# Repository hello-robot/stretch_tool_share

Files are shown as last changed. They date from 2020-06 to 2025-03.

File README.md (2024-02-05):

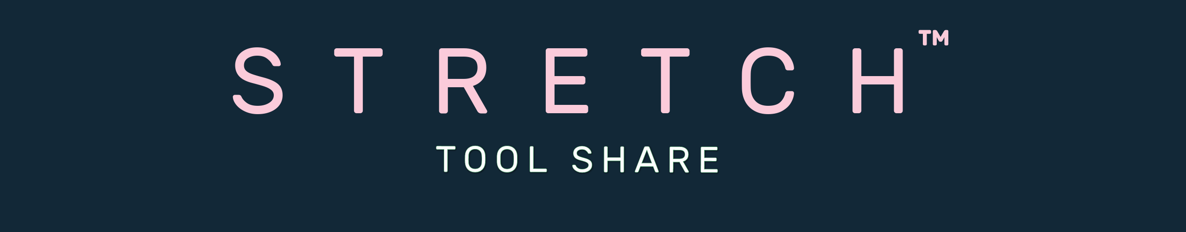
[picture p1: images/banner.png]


# Overview

We designed Stretch's hardware to be easily extended. You can make your own tool and attach it to the wrist to creatively expand what the Stretch RE1 can do. Your tool can also use Dynamixel X-series servos from Robotis via the provided TTL bus. 

In this repository, we provide examples of tools that we've created. We've released them with a permissive Apache 2.0 license, so you're free to use them as you wish. We hope they'll inspire you to create your own tools.

We also include URDF and mesh files for many of the tools in their `stretch_description` folder. See the [Stretch ROS](https://github.com/hello-robot/stretch_ros/tree/master/stretch_description) documentation for guidance on integrating these tools into your robot model.

We'd love it if you shared your creations with the community. We recommend you create a GitHub repository similar to this one for your own tools and then post an announcement to the [forum](https://forum.hello-robot.com/) to let people know about it. 

| Tool | |
|:---:| :---: |
| [NVIDIA Jetson Orin AGX Backpack](./tool_share/jetson_orin_agx_mount) |  || | |
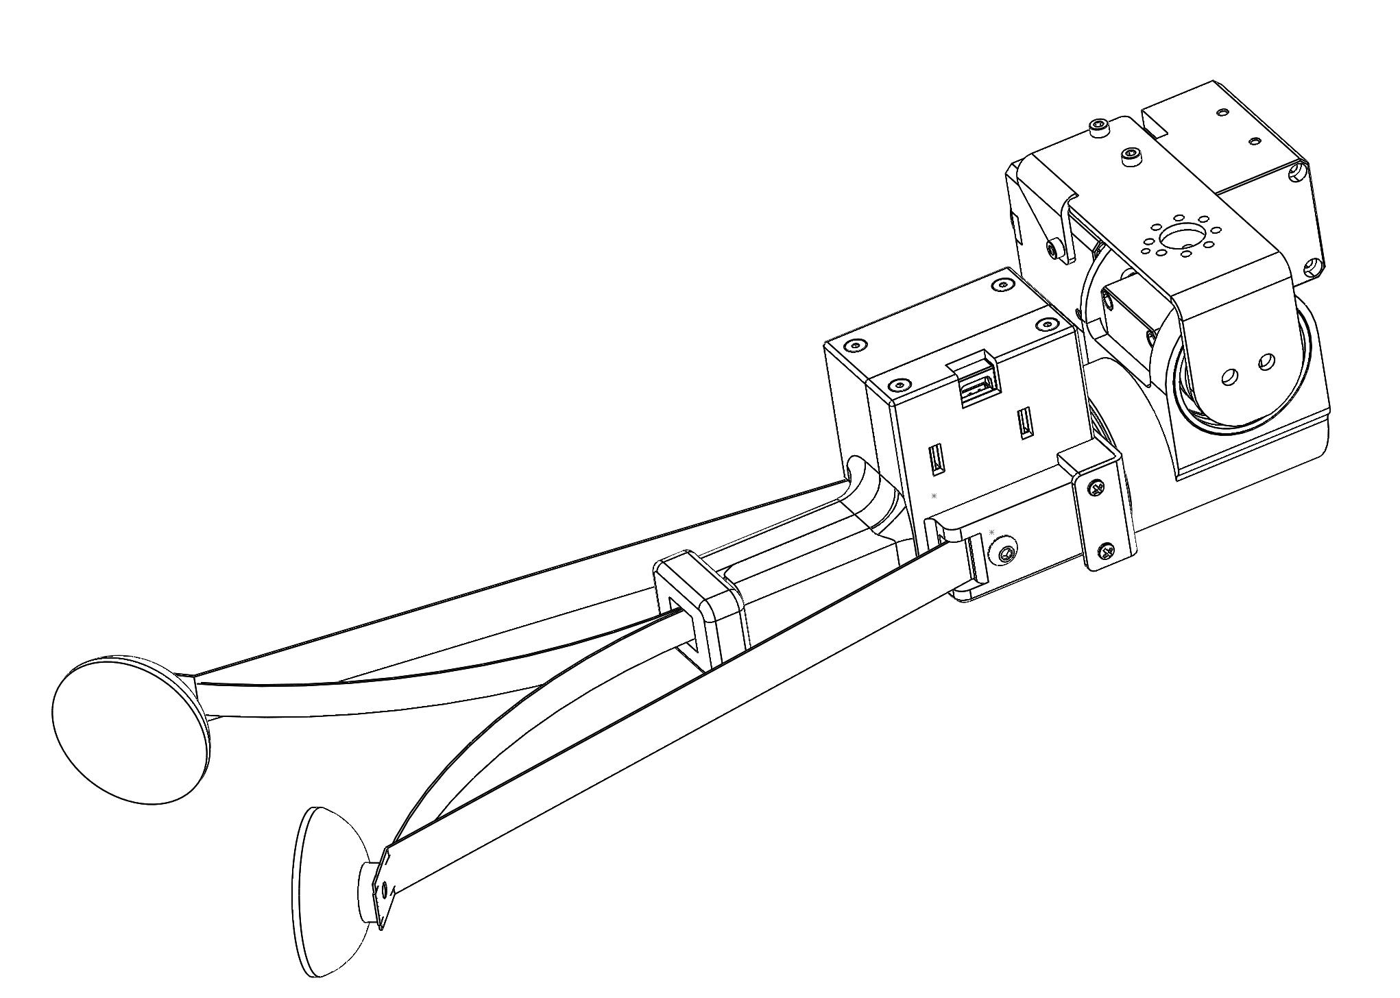
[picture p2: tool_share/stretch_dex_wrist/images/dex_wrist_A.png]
| [Stretch Dex Wrist](./tool_share/stretch_dex_wrist) |  |
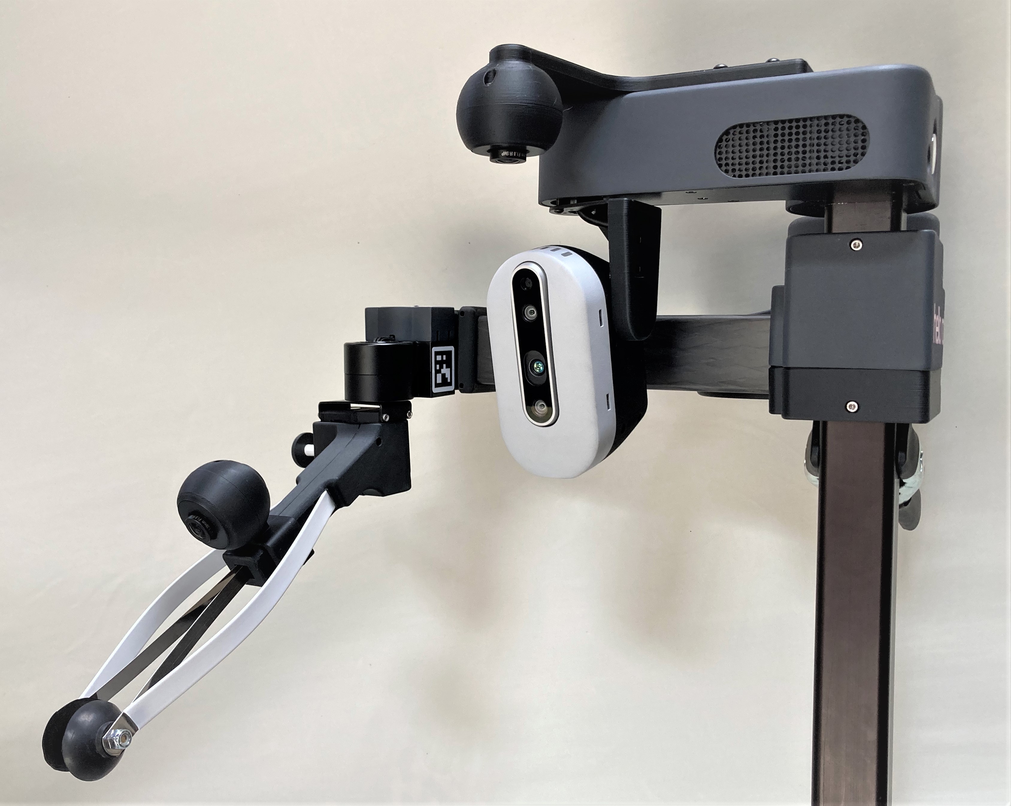
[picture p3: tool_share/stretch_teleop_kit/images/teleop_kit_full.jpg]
| [Stretch Teleop Kit](./tool_share/stretch_teleop_kit) |  |
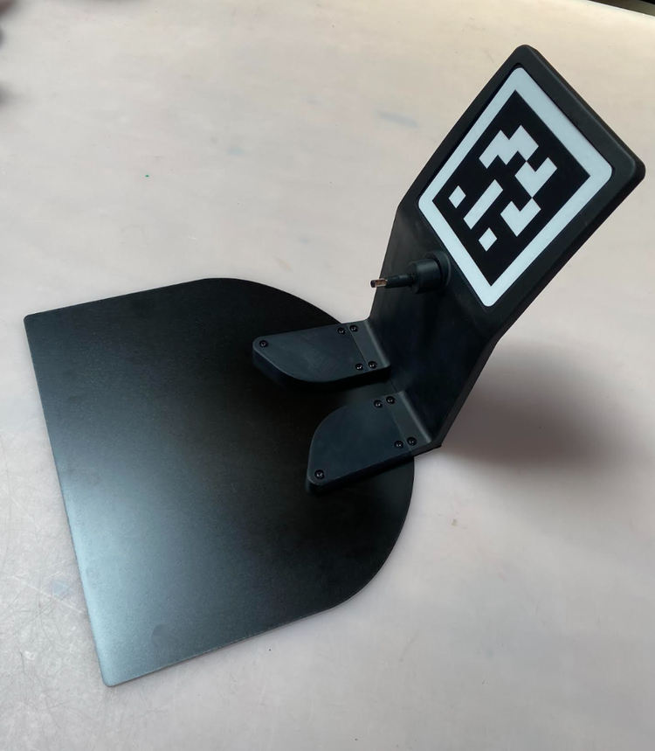
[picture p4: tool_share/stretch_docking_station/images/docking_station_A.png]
| [Stretch Docking Station](./tool_share/stretch_docking_station) |  |
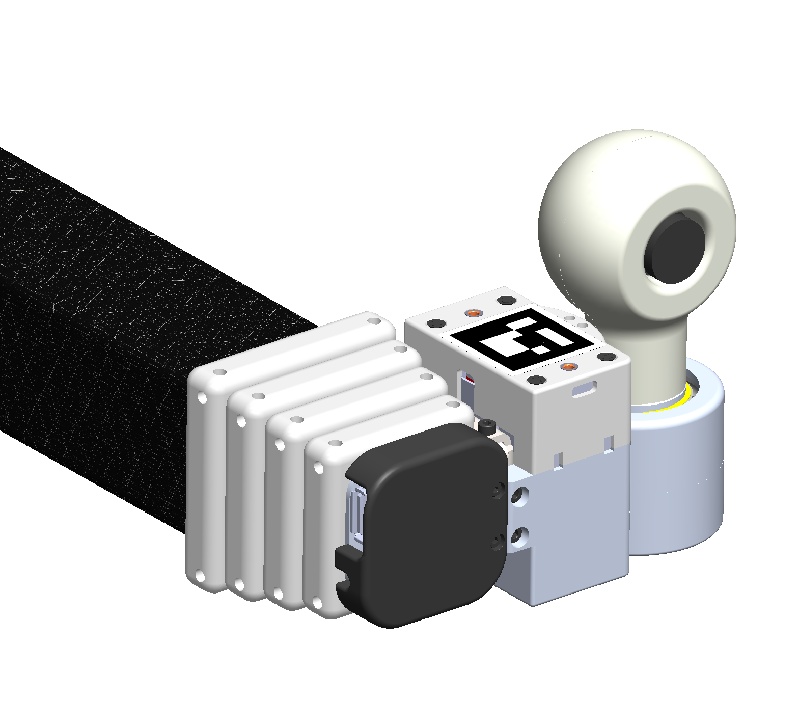
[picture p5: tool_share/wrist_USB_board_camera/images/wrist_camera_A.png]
| [Wrist USB Board Camera](./tool_share/wrist_USB_board_camera) |  |
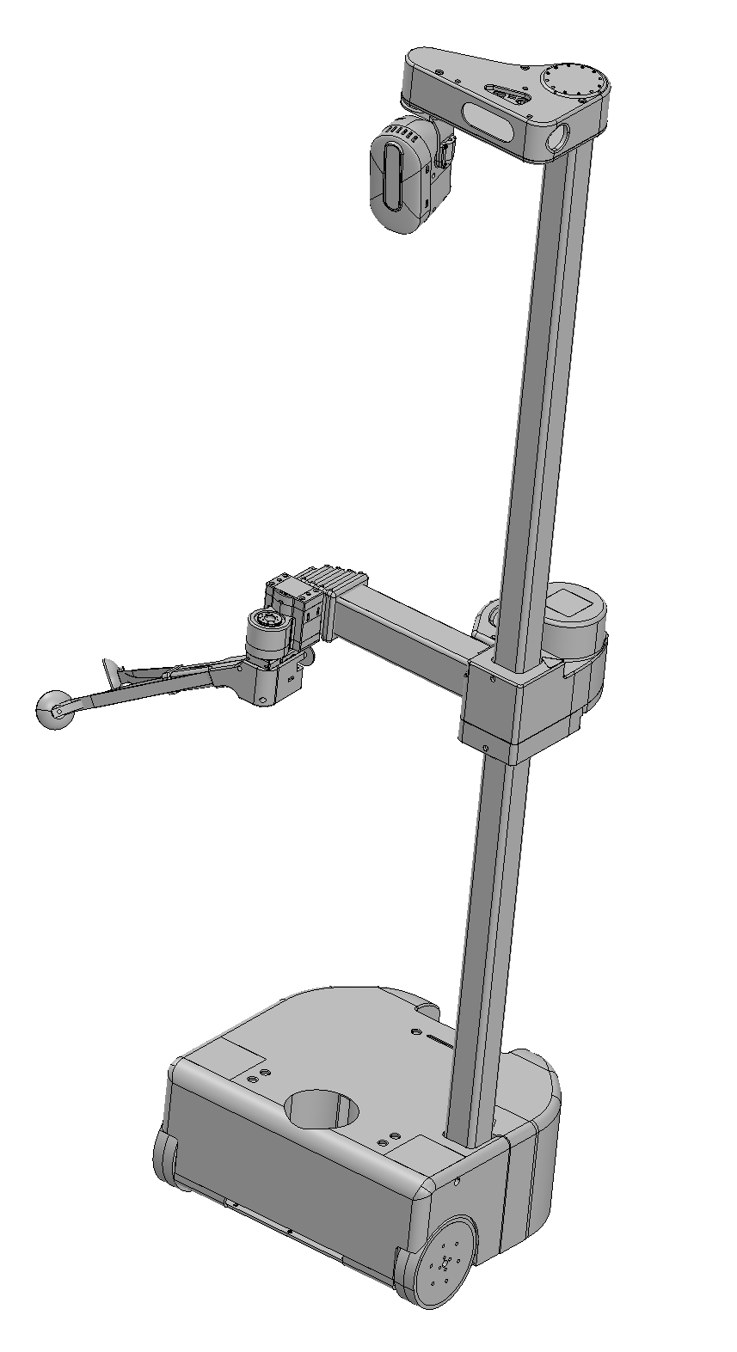
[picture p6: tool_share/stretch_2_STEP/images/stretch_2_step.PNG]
| [Stretch 2 Model](./tool_share/stretch_2_STEP) |  |
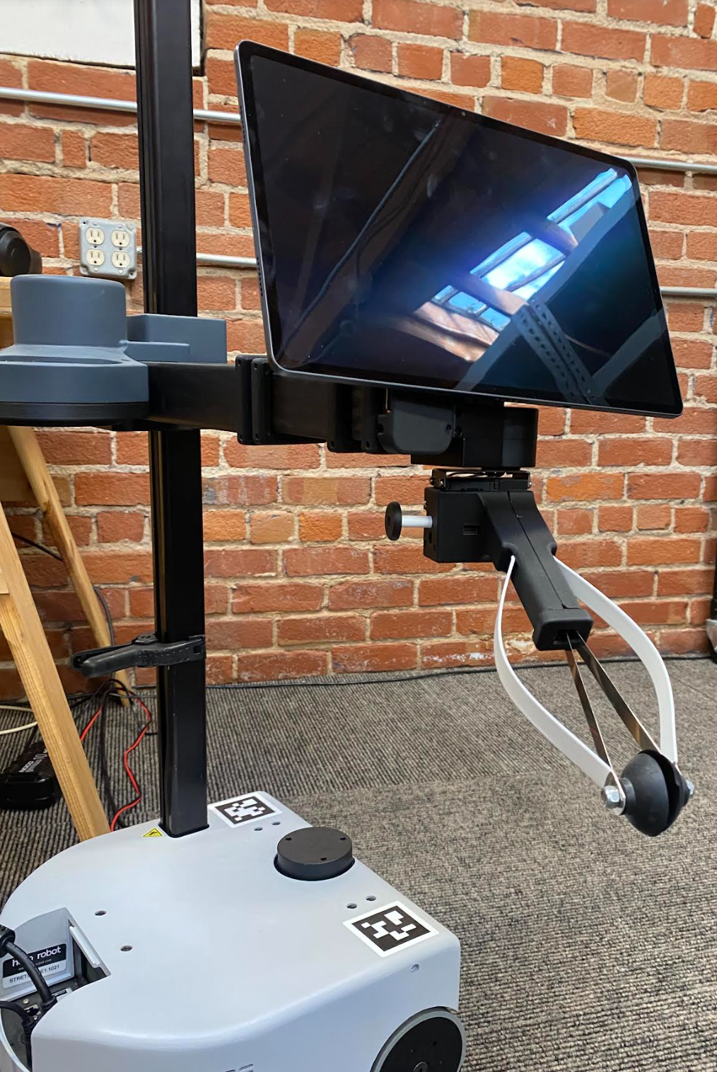
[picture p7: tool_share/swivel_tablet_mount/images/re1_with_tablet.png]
| [Swivel Tablet Mount](./tool_share/swivel_tablet_mount) |  |
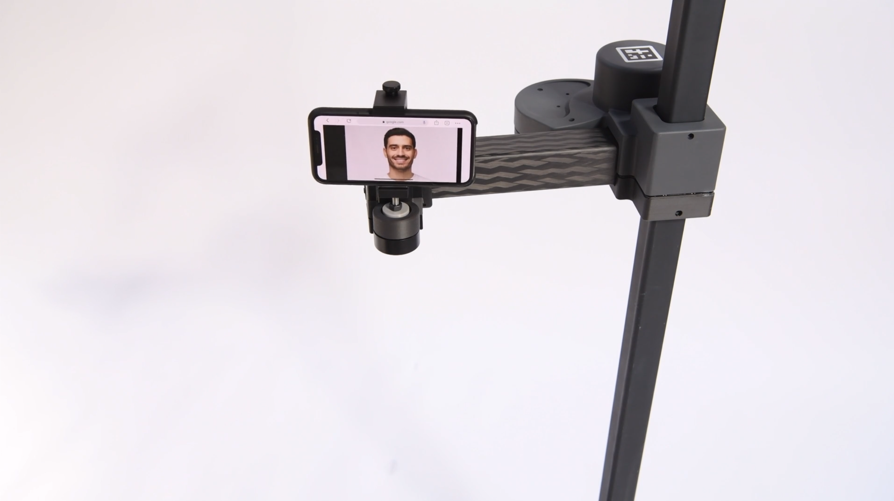
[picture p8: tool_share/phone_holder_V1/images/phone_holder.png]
| [Phone Holder V1](./tool_share/phone_holder_V1) |  |
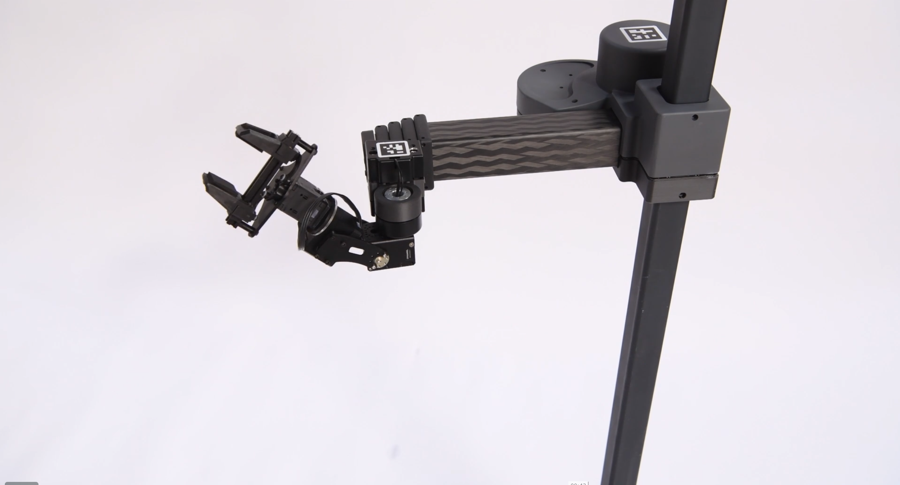
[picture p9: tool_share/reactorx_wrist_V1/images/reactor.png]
| [ReactorX Wrist V1](./tool_share/reactorx_wrist_V1) |  |
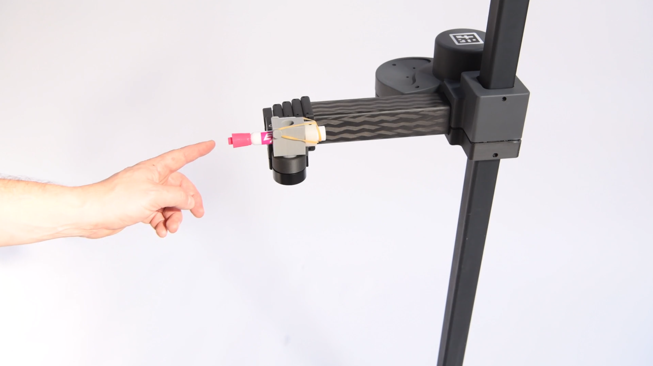
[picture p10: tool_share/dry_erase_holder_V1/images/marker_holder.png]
| [Dry Erase Holder V1](./tool_share/dry_erase_holder_V1) |  |
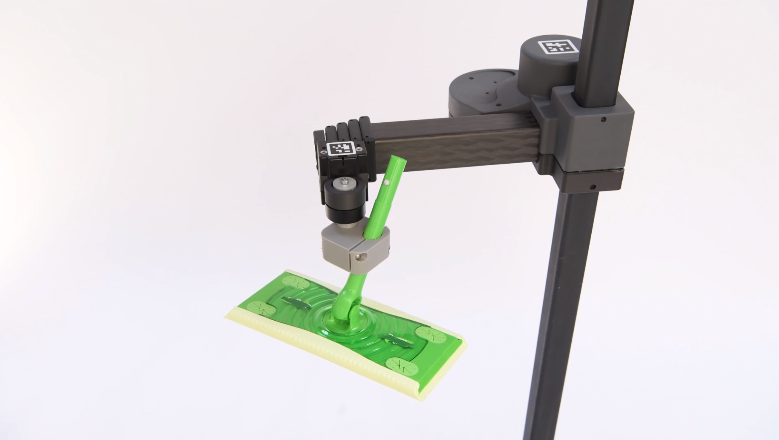
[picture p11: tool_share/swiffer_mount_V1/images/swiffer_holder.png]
| [Swiffer Mount V1](./tool_share/swiffer_mount_V1) |  |
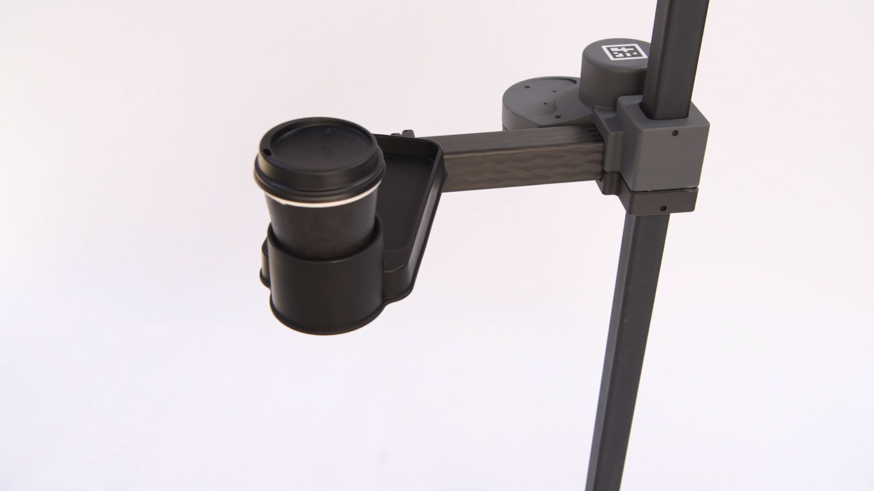
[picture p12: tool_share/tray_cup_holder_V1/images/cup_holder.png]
| [Tray Cup Holder V1](./tool_share/tray_cup_holder_V1) |  |
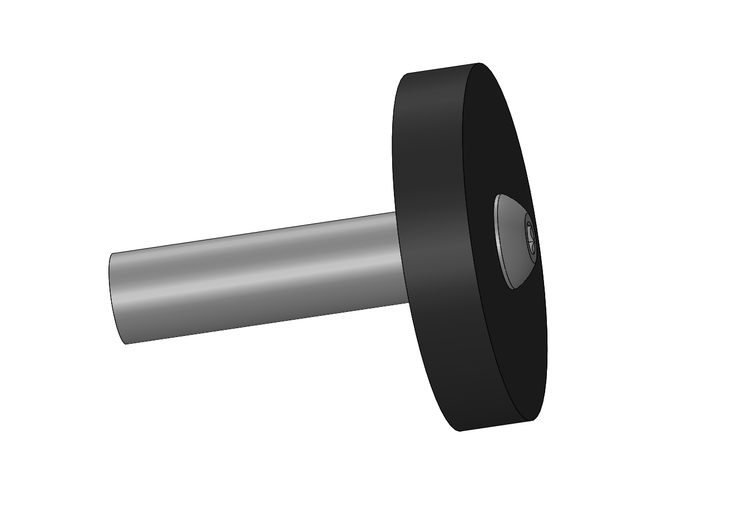
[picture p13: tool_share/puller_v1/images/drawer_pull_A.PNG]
| [Puller V1](./tool_share/puller_v1) |  |
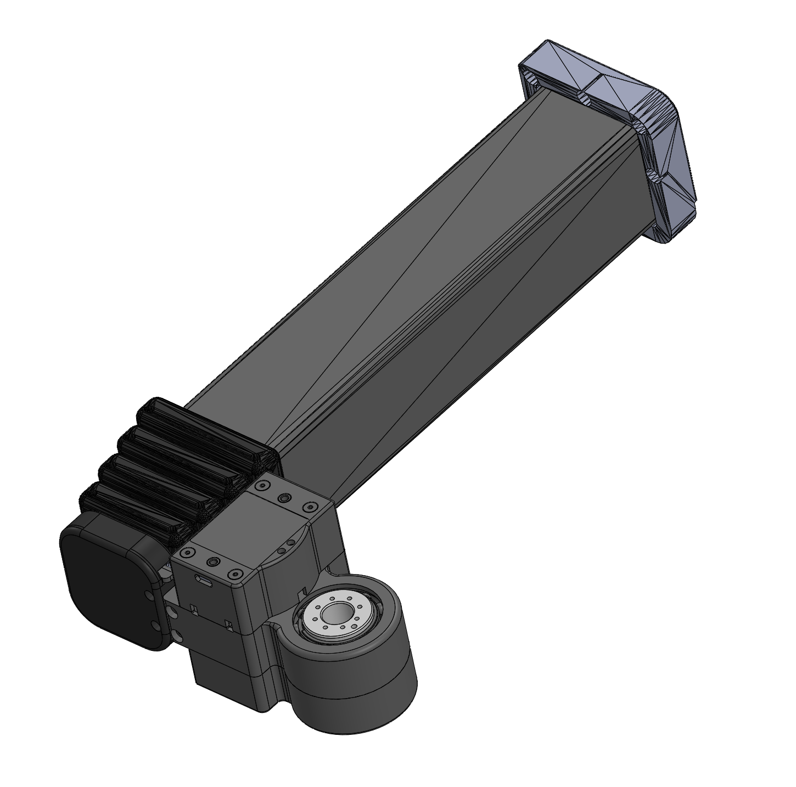
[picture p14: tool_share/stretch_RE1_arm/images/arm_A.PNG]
| [Stretch RE1 Arm](./tool_share/stretch_RE1_arm) |  |
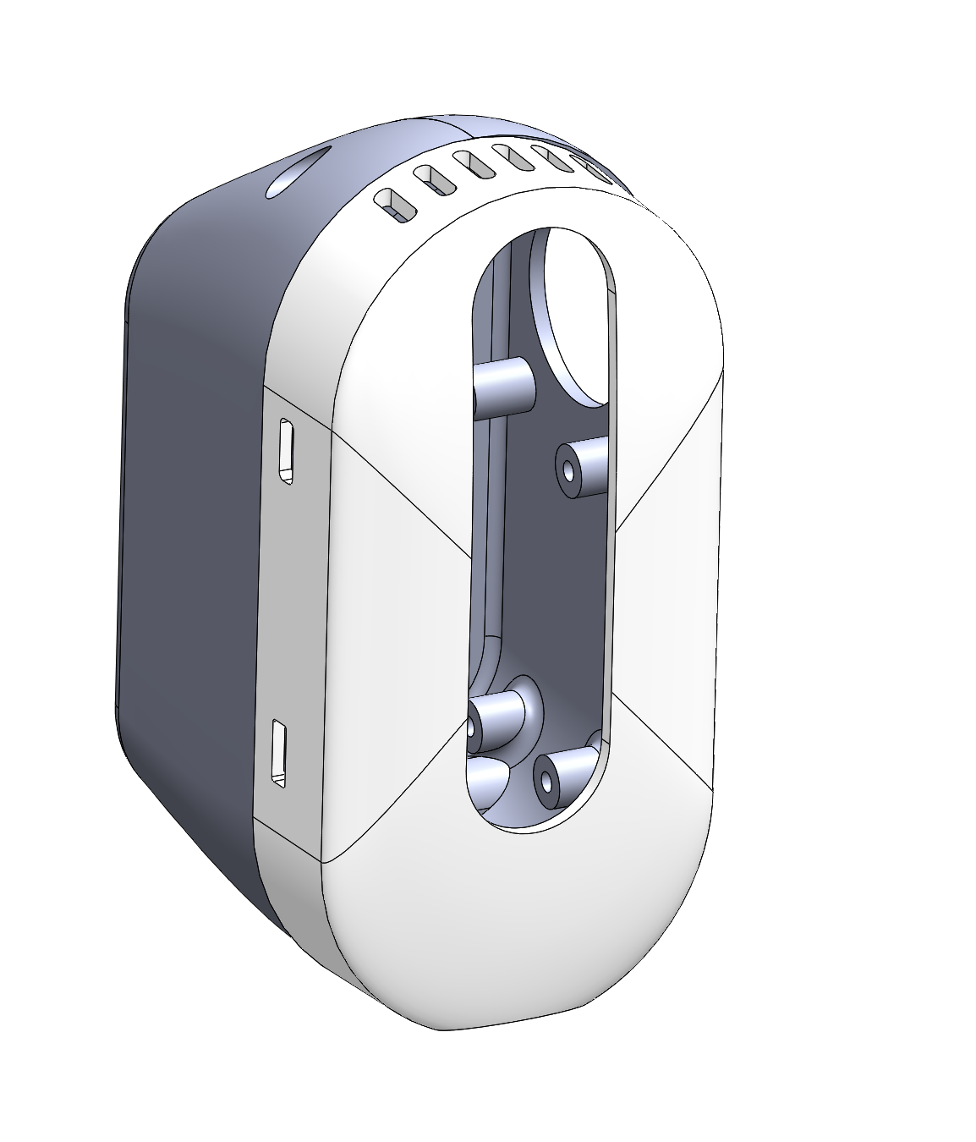
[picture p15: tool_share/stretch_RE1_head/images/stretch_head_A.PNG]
| [Stretch RE1 Head](./tool_share/stretch_RE1_head) |  |
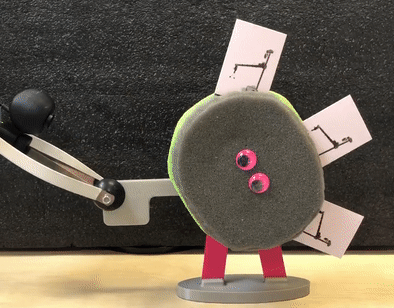
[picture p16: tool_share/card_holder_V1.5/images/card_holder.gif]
| [Easy-Access Card Holder](./tool_share/card_holder_V1.5) |  |
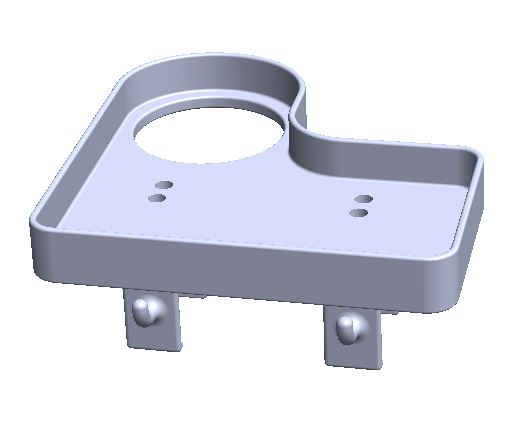
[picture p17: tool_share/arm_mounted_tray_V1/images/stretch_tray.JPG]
| [Arm-Mounted Tray](./tool_share/arm_mounted_tray_V1) |  |
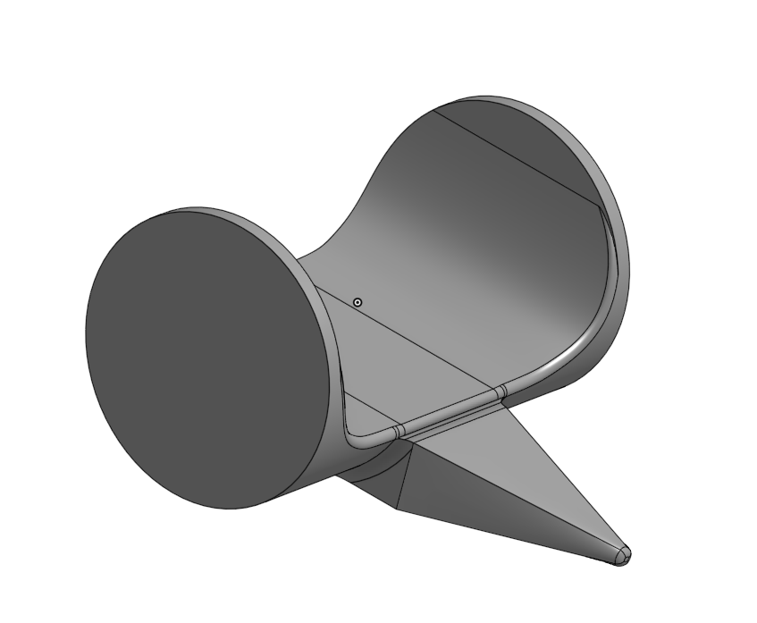
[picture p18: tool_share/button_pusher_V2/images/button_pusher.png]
| [Button Pusher](./tool_share/button_pusher_V2) |  |

## Licenses

The contents in this repository that represent parts of a Stretch robot, such as its head, arm, wrist, and default gripper, are covered by the [CC BY-NC-SA 4.0](https://creativecommons.org/licenses/by-nc-sa/4.0/) license. Please note that the Stretch robot and its default gripper are also covered by patents. Please see the [ROBOT_LICENSE](ROBOT_LICENSE.md) file for details.

Other contents in this repository created by Hello Robot Inc. that specifically pertain to the tools that attach to the Stretch mobile manipulators as accessories are covered by the [Apache 2.0](http://www.apache.org/licenses/LICENSE-2.0) license. Please see the [TOOL_LICENSE](TOOL_LICENSE.md) file for details.

The contents of this repository are intended for use with the Stretch mobile manipulators, which are robots produced and sold by Hello Robot Inc. For further information, including inquiries about dual licensing, please contact Hello Robot Inc.

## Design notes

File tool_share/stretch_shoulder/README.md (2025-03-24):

# Stretch Shoulder

This step file captures the robot's shoulder shell. It aims to make it easier to build designs in CAD that attach to the shoulder's mounting points. Schematics and more details available in the [Extending Stretch with Additional Hardware](https://docs.hello-robot.com/0.3/extending_stretch/extending_stretch_additional_hardware/).

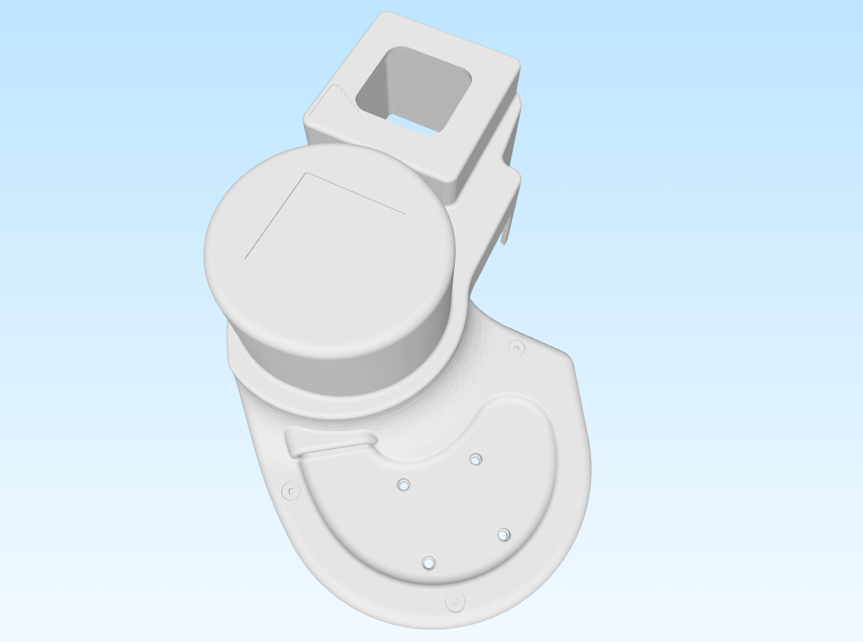
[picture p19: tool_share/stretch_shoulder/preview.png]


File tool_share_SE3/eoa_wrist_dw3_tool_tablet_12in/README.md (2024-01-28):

To install:

Add the following to your user yaml:

robot:
  tool: eoa_wrist_dw3_tool_tablet_12in

params:
  - stretch_tool_share_se3.eoa_wrist_dw3_tool_tablet_12in.params

Copy mesh and xacro data to ~/repos/stretch_urdf/stretch_urdf/<ROBOT_MODEL>

Make a new top level xacro under stretch_urdf, eg:

stretch_description_SE3_eoa_wrist_dw3_tool_tablet_12in.xacro

<?xml version="1.0"?>
<robot xmlns:xacro="http://www.ros.org/wiki/xacro" name="stretch">

  <xacro:include filename="stretch_main.xacro" />
  <xacro:include filename="stretch_aruco.xacro" />
  <xacro:include filename="stretch_d435i.xacro" />
  <xacro:include filename="stretch_laser_range_finder.xacro" />
  <xacro:include filename="stretch_base_imu.xacro" />
  <xacro:include filename="stretch_respeaker.xacro" />
  <xacro:include filename="stretch_wrist_dw3.xacro" />
  <xacro:include filename="stretch_tool_tablet_12in.xacro" />
  <xacro:include filename="stretch_head_nav_cam.xacro" />
</robot>

Then run ~/repos/stretch_urdf/urdf_generate.py to create a new URDF that matches your tool
Then copy the URDF and meshes to 

pkg = str(importlib_resources.files("stretch_urdf"))  # .local/lib/python3.10/site-packages/stretch_urdf)

Then copy the URDF and meshes for ROS2...

Note: Need to copy mesh and urdf files to the PKG install place
 1298  cd ~/repos/stretch_tool_share/tool_share_SE3/eoa_wrist_dw3_tool_tablet_12in
 1300  cp meshes/*.STL ~/repos/stretch_urdf/stretch_urdf/SE3/meshes/
 1301  cp xacro/stretch_tool_tablet_12in.xacro ~/repos/stretch_urdf/stretch_urdf/SE3/xacro/

 cp stretch_urdf/SE3/*.urdf ~/.local/lib/python3.10/site-packages/stretch_urdf/SE3/
 1319  ./stretch_urdf/tools/stretch_urdf_viz.py 
 1320  cp stretch_urdf/SE3/meshes/*tablet* ~/.local/lib/python3.10/site-packages/stretch_urdf/SE3/meshes/
 1321  ./stretch_urdf/tools/stretch_urdf_viz.py 
 1322  ls
 1323  cd stretch_urdf/
 1324  pip3 install -e .
 1329  pip3 list | grep stretch

Verify that new tool shows up here
 1330  ./stretch_urdf/tools/stretch_urdf_viz.py

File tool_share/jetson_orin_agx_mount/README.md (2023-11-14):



## Nvidia Jetson Orin AGX Backpack

**Created by**: Hello Robot Inc

This tool allows an Nvidia Jetson Orin AGX to be mounted and wired to the Stretch base. The design uses a laser cut piece of white Delrin ordered from Ponoko.com, and a number of off the shelf items listed below.

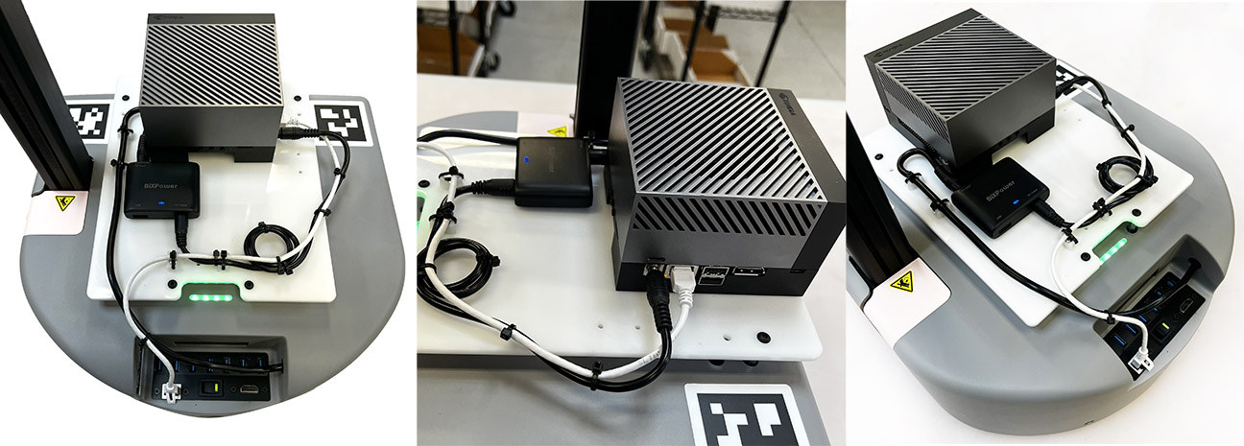
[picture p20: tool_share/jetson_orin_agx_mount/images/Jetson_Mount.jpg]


## Parts List

| Item | Qty | Vendor |
|---|:---:|---:|
| [DC Power Pigtails Cable, DC 5.5mm x 2.5mm Male Plug Jack to Bare Wire Open End Power Supply Replacement 3Ft](https://www.amazon.com/gp/product/B09JKNRHBZ/ref=ppx_yo_dt_b_asin_title_o03_s00?ie=UTF8&psc=1) | 1 | Amazon |
| [12V DC to 19V DC Mini Size Ultra-slim High Efficiency 90W Power Adapter DD90M-19V](https://www.bixpower.com/BX-DD90M-p/bx-dd90m-19v.htm) | 1 | BIX |
| [JST VH 3.96 mm Pitch 2 Pin](https://www.amazon.com/pzsmocn-JST-VH-VH-SMT-Terminal-Connector/dp/B089QRPTYS?th=1) | 1 | Amazon |
| [CAT6A Slim Cable UTP Booted 1.5 FT](https://www.amazon.com/gp/product/B07WZQCBBF/ref=ppx_yo_dt_b_asin_title_o05_s00?ie=UTF8&psc=1) | 1 | Amazon |
| [White Delrin Laser Cut Base](https://www.ponoko.com/materials/white-delrin) using [Jetson_Orin_AGX_base_plate_flat_pattern.DXF](CAD/Jetson_Orin_AGX_base_plate_flat_pattern.DXF) | 1 | Ponoko |
| [Male-Female Threaded Hex Standoff](https://www.mcmaster.com/93655A308/) | 4 | McMaster-Carr |
| [Cable Tie Mount](https://www.mcmaster.com/7566K12/) | 5 | McMaster-Carr |
| [Cable Zip Ties 4 Inch](https://www.amazon.com/gp/product/B07V6QLSBP/ref=ppx_yo_dt_b_search_asin_title?ie=UTF8&psc=1) | 8 | Amazon |
| [Phillips Rounded Head Thread-Forming Screws](https://www.mcmaster.com/90380A375/) | 5 | McMaster-Carr |
| [Black-Oxide Alloy Steel Button Head Torx Screws](https://www.mcmaster.com/96452A714/) | 4 | McMaster-Carr |
| [Torx Flat Head Thread-Cutting Screws for Metal](https://www.mcmaster.com/90390A112/) | 4 | McMaster-Carr |

## Assembly instructions                                                                                               
 [NVIDIA Jetson Orin AGX Mount Assembly Instructions PDF](images/Stretch_2_NVIDIA_Jetson_Orin_AGX_Mount_Installation.pdf)                                                                                  
1. Cut the DC power cable 20" in length. Pigtail the cable and expose 3/16" of copper wire . Crimp with JST-VH crimper tool and attach the JST-VH 2 pin connector.

2. Remove base shell from Stretch base.

3. Connect the 2 pin connector to 12volt Aux on PIMU.

4. Using a digital multimeter place the <span style="color:red;">**positive (red) probe**</span> inside the barrel jack connector of the new cable, and touch the **negative (black) probe** on the outside of the barrel jack connector.

5. Turn on Stretch and measure the voltage coming out of new cable that is connected to the 12volt Aux connector using a digital multimeter. Ensure that the voltage reading is **positive 12V** or higher
      > [!WARNING]
      > Ensuring that the voltage coming out of the new cable is positive, is crucial in protecting Stretch's main power board from damaging.

6. Route cable through Aux hole in the base shell and re-install base shell.

7. Mount the Jetson Orin AGX to white delrin custom plate using 4x Torx Flat Head Thread-Cutting Screws for Metal.

8. Add 4x Male-Female Threaded Hex Standoff to Stretch Base accessory mounts.

9. Mount the white delrin custom plate to standoffs using 4x Steel Button Head Torx Screws.

10. Plug in ethernet cable to Jetson Orin AGX.

11. Plug your custom length DC power cable into the BIX power adaptor. Plug the Bix power adapter to Jetson Orin AGX.
    > [!IMPORTANT]
    > The BIX Power Adapter is a crucial component that we highly recommend purchasing for this setup. It adds additional safety features to the power path system. Not adding this part to the setup can lead to the Jetson power system failing.

12. Attach 5x Cable tie mounts using 5x Phillips Rounded Head Thread forming screws.

13. Zip-tie cables and cut excess.

## Software

Adding this requires limiting the range of motion of the lift joint so that it does not collide with the part. To do this, modify the lower range in your ```stretch_user_params.yaml``` to:

```commandline
lift:
  range_m: [0.25, 1.xxx]
```

Note: `1.xx` is the calibrated upper bound found from ```stretch_params.py | grep lift | grep range_m```

Note: This conservatively limits the range of motion such that the standard gripper will not collide when stowed.

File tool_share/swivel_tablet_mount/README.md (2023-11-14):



## Swivel Tablet Mount

**Created by**: Hello Robot Inc

This tool allows a tablet to be attached to the Stretch wrist. The design uses an off-the-shelf swivel phone holder, two 3D printed adapter plates, and a die-cut double stick tape..

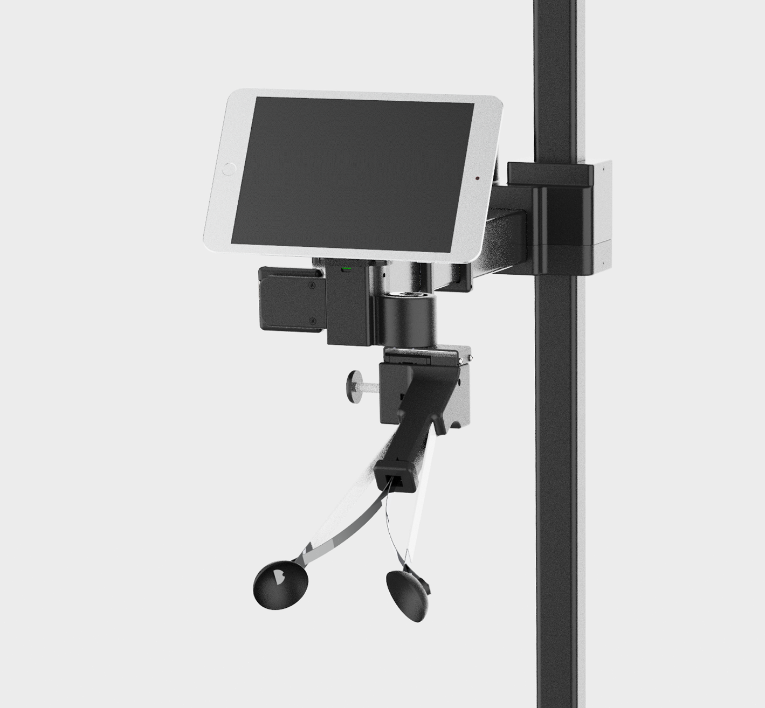
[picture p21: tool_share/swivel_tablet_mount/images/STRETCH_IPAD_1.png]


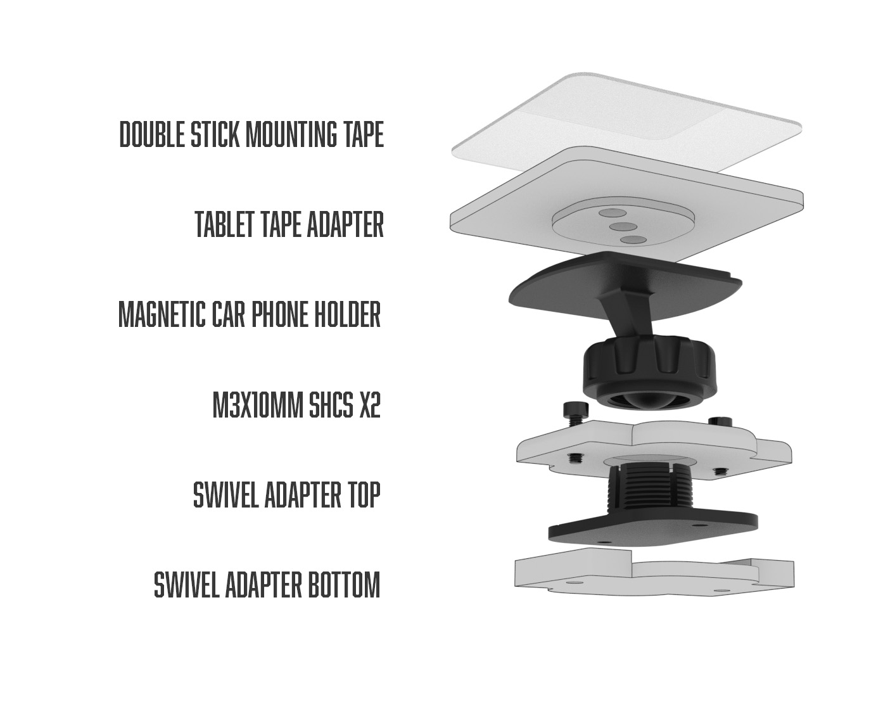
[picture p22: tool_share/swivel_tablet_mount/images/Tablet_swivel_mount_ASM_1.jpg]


## Parts List

| Item | Qty | Vendor |
|---|:---:| -----: |
| [M3x10mm SHCS](https://www.mcmaster.com/91290A115/) | 2 | McMaster-Carr|
| [Double stick mounting tape 2 3/8"](https://www.amazon.com/gp/product/B09VRXDMWW/ref=ppx_yo_dt_b_search_asin_title?ie=UTF8&psc=1) | 1 | Amazon |
| [swivel_adapter_top.STL](CAD/swivel_adapter_top.STL) | 1 | PLA 3D printer |
| [swivel_adapter_bottom.STL](CAD/swivel_adapter_bottom.STL) | 1 | PLA 3D printer | 
| [tablet_tape_adapter.STL](CAD/tablet_tape_adapter.STL) | 1 | PLA 3D printer |
| [Magnetic car phone holder](https://www.amazon.com/gp/product/B075XZBKBQ/ref=ppx_yo_dt_b_search_asin_title?ie=UTF8&th=1) | 1 | Amazon |

## Assembly instructions
[View 3D Assembly](CAD/ASSEM_ball_swivel.STEP)

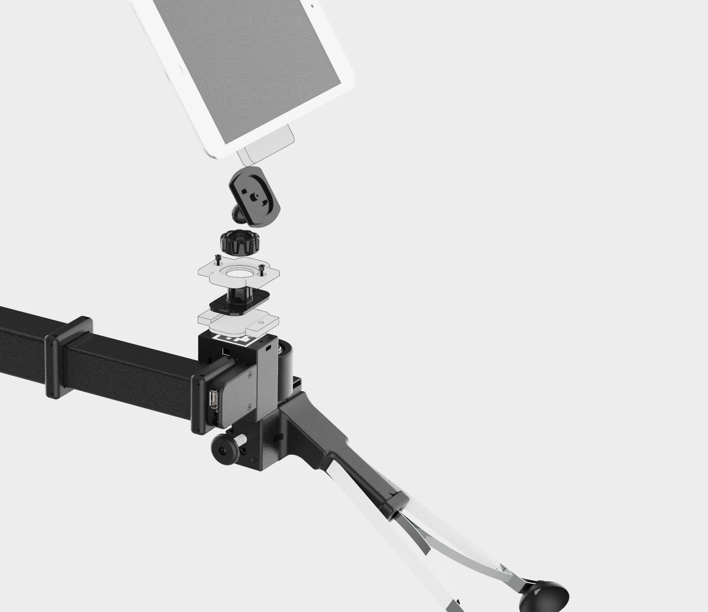
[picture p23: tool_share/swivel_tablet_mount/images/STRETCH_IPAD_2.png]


1. Remove the rubber cover from the phone holder. You'll see metal plate holding the magnets. Remove the metal plate with a screw driver.
2. Attach the 'tablet_tape_adapter' to the phone holder, reusing the screw you just remove. Note: If the adapter does not sit flat you may want to clip the plastic 'L' tabs from the holder using side cutters.
3. Unscrew the large nut on the phone holder and disengage the ball from its socket.
4. Remove the red sticker from the phone holder, exposing the double stick tape. Stick the phone holder firmly onto the 'swivel adapter'
5. Attach the swivel adapter to the top of the Stretch wrist using the M3 bolts
6. Attach the tablet_tape_adapter to your tablet in the desired position using the 'double stick mounting tape'
7. Finally, insert the ball back into the socket of the phone holder. Attach firmly using the large nut.

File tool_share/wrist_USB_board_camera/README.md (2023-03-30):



## Wrist USB Board Camera

**Create by**: Hello Robot Inc

This design allows you to attach a USB board camera to the wrist yaw joint of Stretch. The wrist mounted camera can pan left-right, making it perfect for simple remote inspection tasks.

The camera can be integrated into your robot URDF by integrating its [stretch_description](./stretch_description) as described in the [Stretch ROS documentation](https://github.com/hello-robot/stretch_ros/tree/master/stretch_description).


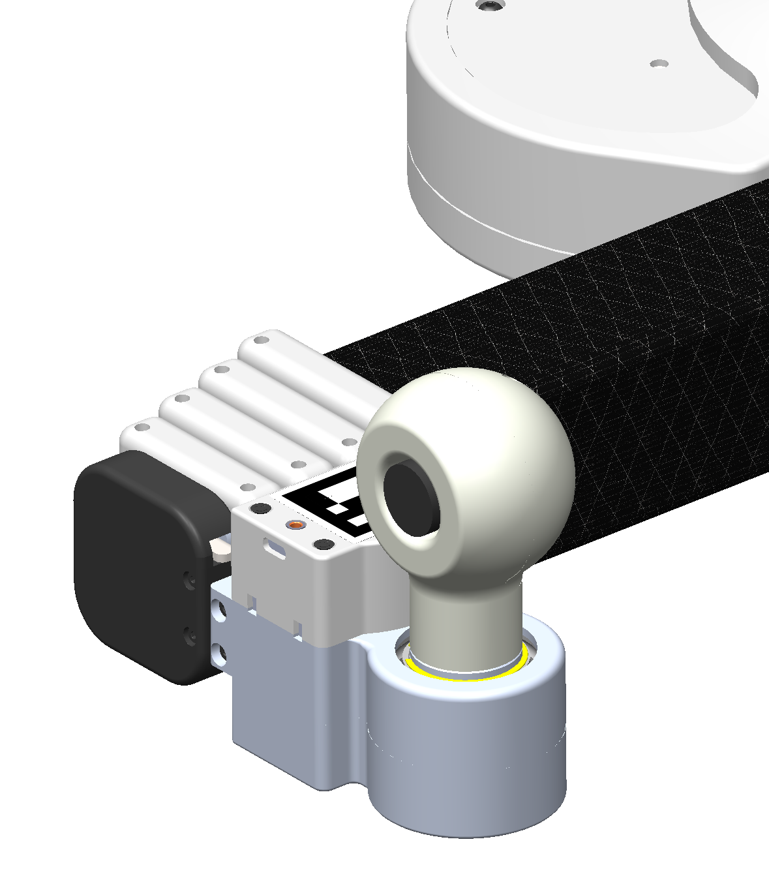
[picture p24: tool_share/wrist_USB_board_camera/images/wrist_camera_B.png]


## Parts List

| Item | Qty | Vendor |
| --- |:---:| -----: |
| [M2x8mm SHCS](https://www.mcmaster.com/91290A015) | 8 | McMaster-Carr|
| [M2x6mm Thread Forming Screw](https://www.mcmaster.com/96817A209) | 5 | McMaster-Carr|
| [Board_Camera_Ball_Shell.STL](CAD/Board_Camera_Ball_Shell.STL) | 1 | PLA 3D printer|
| [Board_Camera_Ball_Cover.STL](CAD/Board_Camera_Ball_Cover.STL) | 1 | PLA 3D printer |
| [ELP 2MP USB Board Camera](https://www.amazon.com/ELP-Camera-Megapixel-Windows-Android/dp/B00KA7WSSU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) (Suggested) | 1 | Amazon / Spinel |

## Assembly instructions
[View 3D assembly](CAD/wrist_USB_board_camera_assembly.STL)

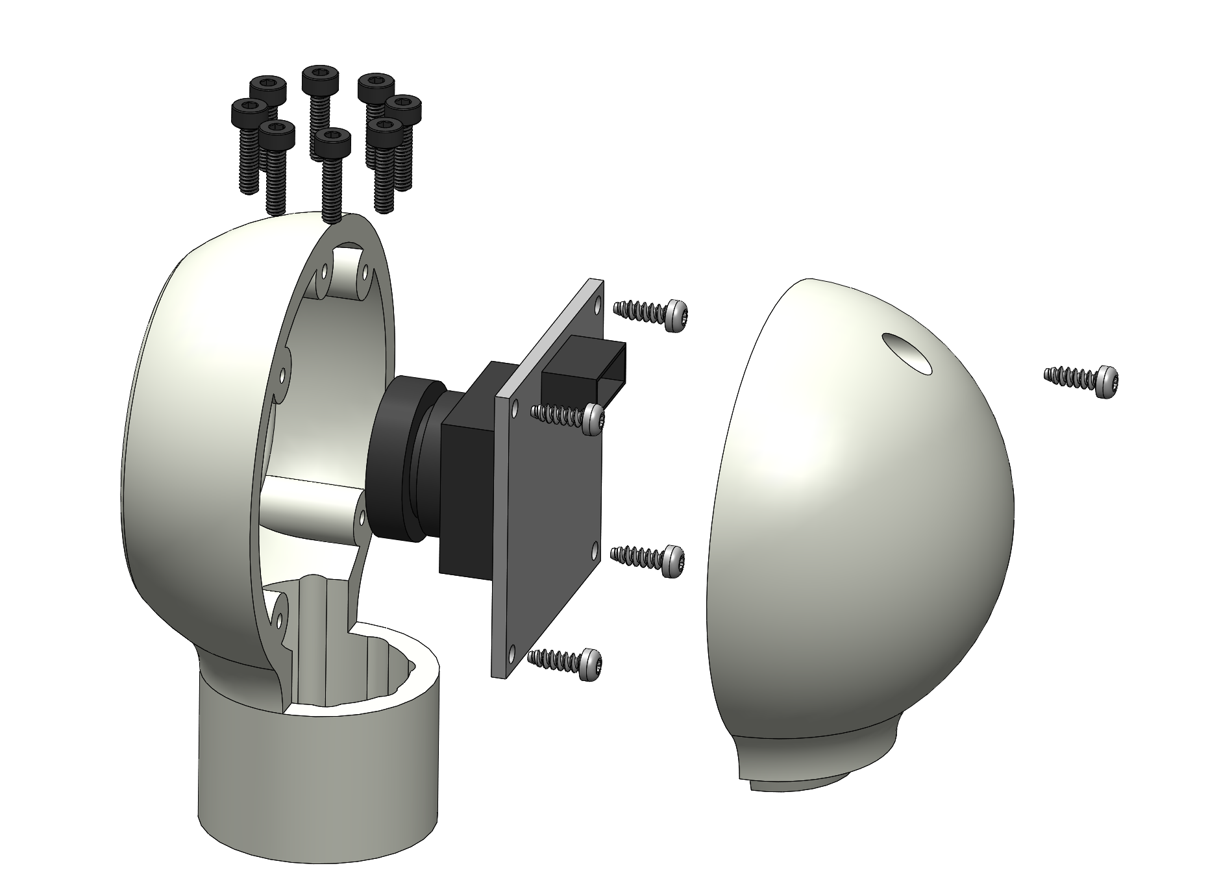
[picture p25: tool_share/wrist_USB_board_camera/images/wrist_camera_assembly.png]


1. Attach the Board_Camera_Ball_Shell to the wrist tool plate using the 8 M2 bolts
2. Attach the camera to the Board_Camera_Ball_Shell using 4 self-threading screws
3. Attach the USB cable and route it down and through the wrist yaw passage
4. Attach the Board_Camera_Ball_Cover using 1 self-threading screw
5. Plug the USB cable into the USB-A port on the wrist

NOTE: The USB cable that comes with the camera uses a JST-PH connector. You may want to make your own cable with a custom length using a right-angle USB-A cable. This may require a JST-PH crimp tool.

NOTE: A variety of USB board cameras are available from ELP and Spinel, among others. The shells may need to be modified to accommodate variations in the mechanical packaging of these cameras.

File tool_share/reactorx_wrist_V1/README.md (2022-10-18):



## Reactor X Wrist

**Created by**: Hello Robot Inc

Here we describe how to modify an [Interbotx ReactorX 150 Dynamixel arm](https://www.trossenrobotics.com/reactorx-150-robot-arm.aspx) to add a Pitch-Roll wrist plus parallel jaw gripper to Stretch, giving you a Yaw-Pitch-Roll wrist!

The ReactorX 150 comes standard with Dynamixel XM430-W350-T servos for the shoulder joints and XL430-W250-T servos for its wrist and gripper. We're going to disassemble the arm and then rebuild it so that the Pitch and Roll DOF use the stronger XM430-W350-T servos.

[View the 3D assembly](CAD/ReactorX_Wrist_V1.STL)

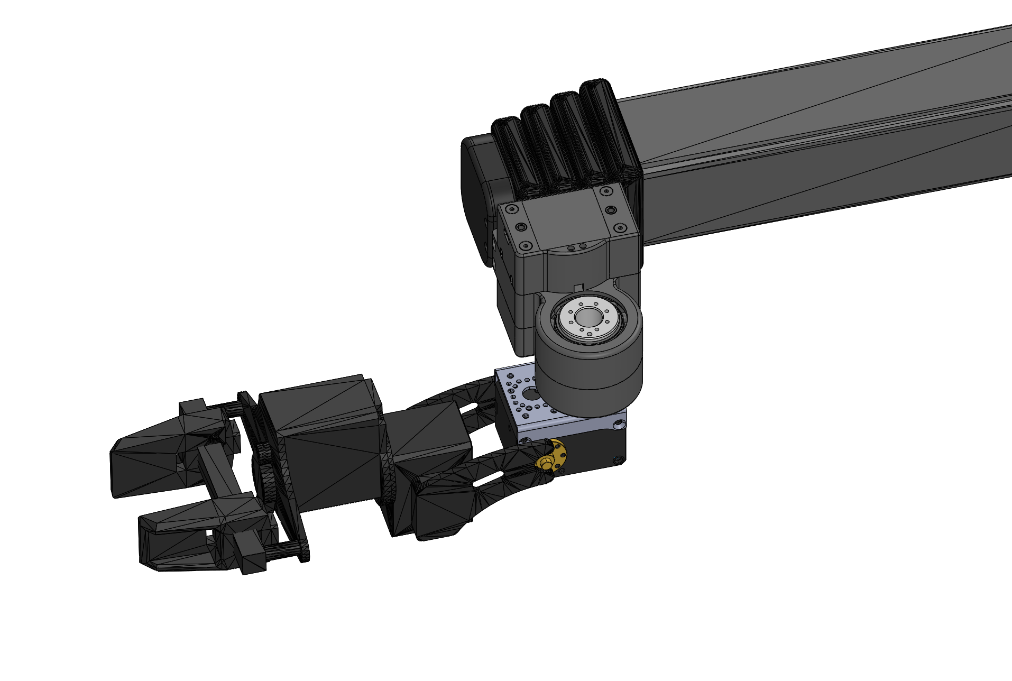
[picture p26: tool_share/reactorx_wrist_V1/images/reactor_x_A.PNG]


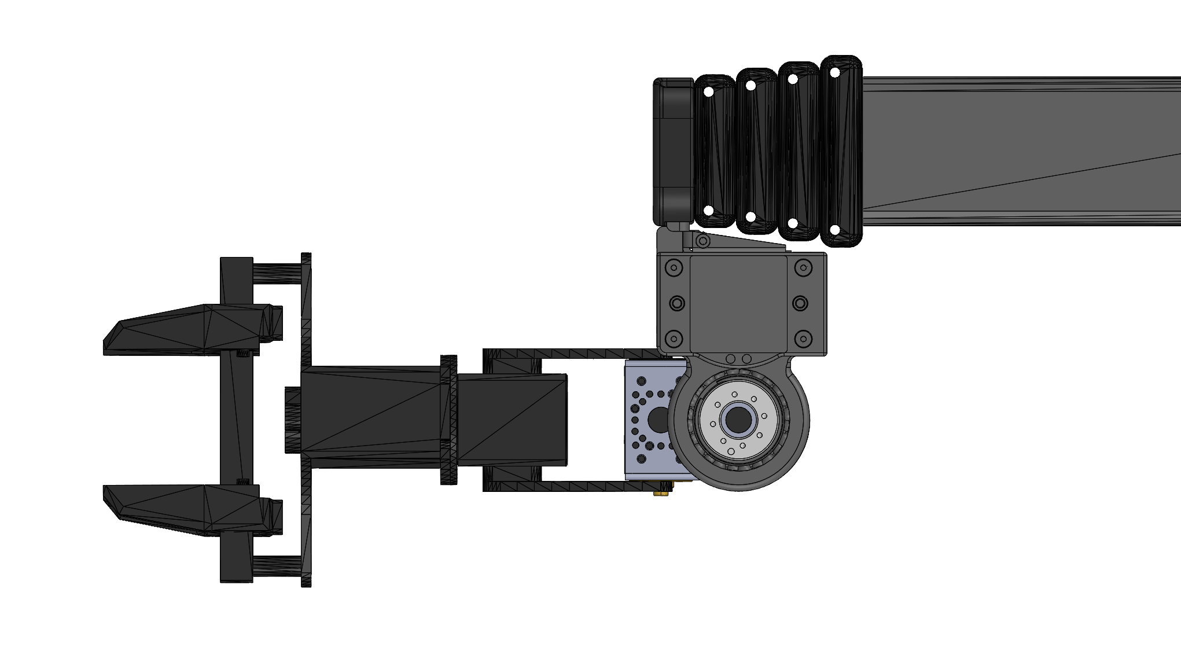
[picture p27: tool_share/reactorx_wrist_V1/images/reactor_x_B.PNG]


## Parts List

| Item | Qty | Vendor |
| --- |:---:| -----: |
| [ReactorX 150 Robot Arm](https://www.trossenrobotics.com/reactorx-150-robot-arm.aspx) | 1 | Trossen Robotics |
| [Robotis FR12-S101K Frame](http://www.robotis.us/fr12-s101k-set/) | 1 | Robotis |
| [M2x4mm SHCS](https://www.mcmaster.com/90128a176) | 10 | McMaster Carr |

## Wrist Build

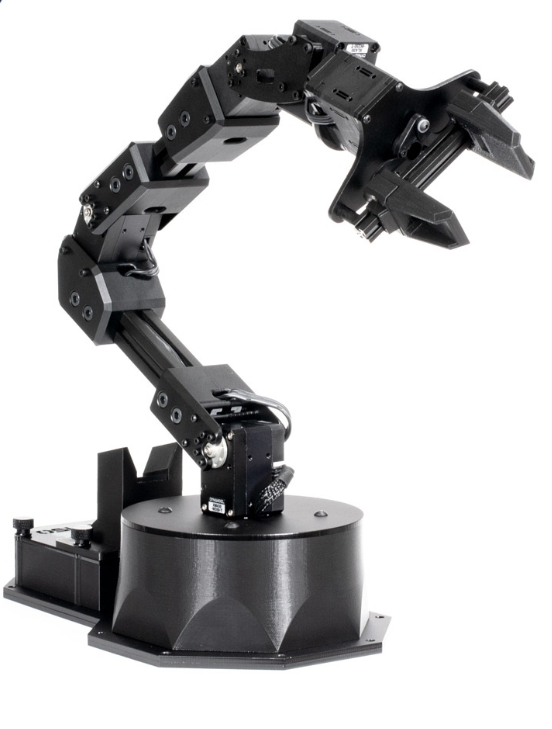
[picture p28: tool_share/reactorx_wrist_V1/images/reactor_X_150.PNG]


Start with a ReactorX 150

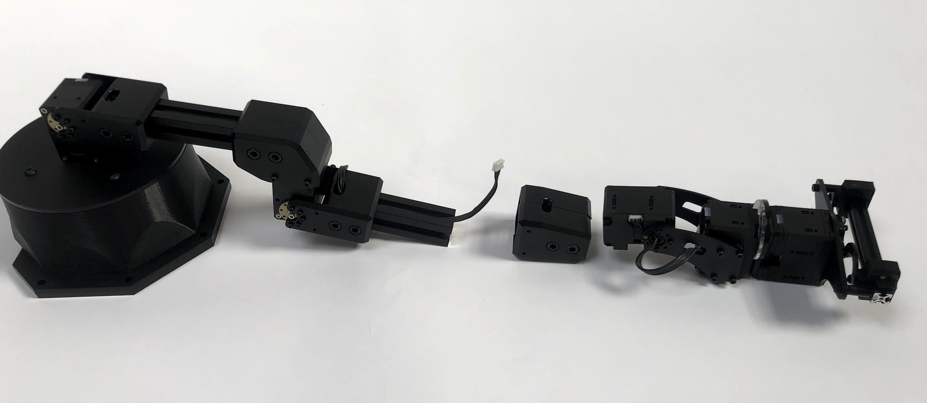
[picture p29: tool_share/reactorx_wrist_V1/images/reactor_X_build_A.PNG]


Detach the the wrist unit from the arm. This includes the final pitch / roll /gripper DOFs with the XL430 servos.

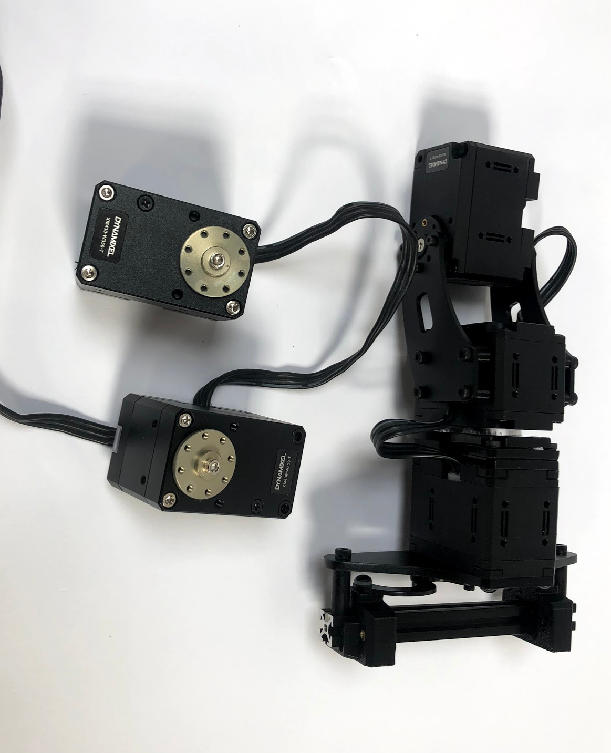
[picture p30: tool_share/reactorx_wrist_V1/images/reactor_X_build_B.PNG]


Remove the XM430 servos from the shoulder of the arm. The XM430s have the metal horns as shown.

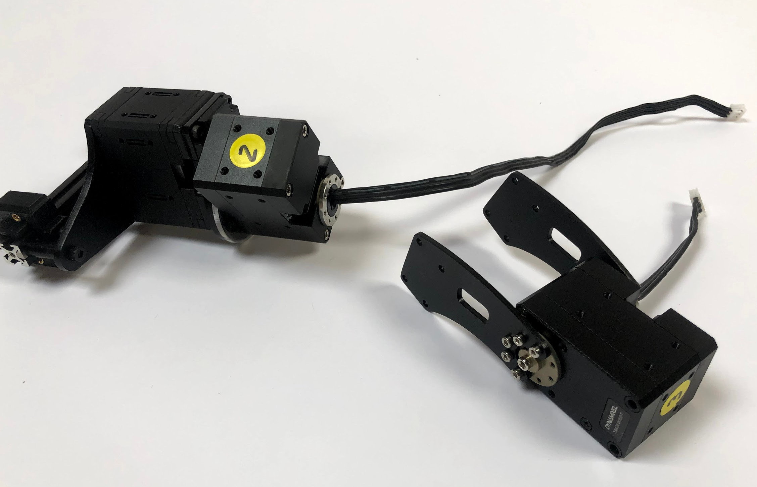
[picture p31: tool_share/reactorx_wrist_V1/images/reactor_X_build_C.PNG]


No replace the pitch and roll servos with the XM430s. Pay attention to how the cables route and which ports they plug into so you can recable the wrist correctly. 

To attach the two side plates to the pitch servo (above, right), you'll want to use the shorter M2x4mm screws. The ones that came off of the XL430s are too long and will cause the servo to bind up if used. 

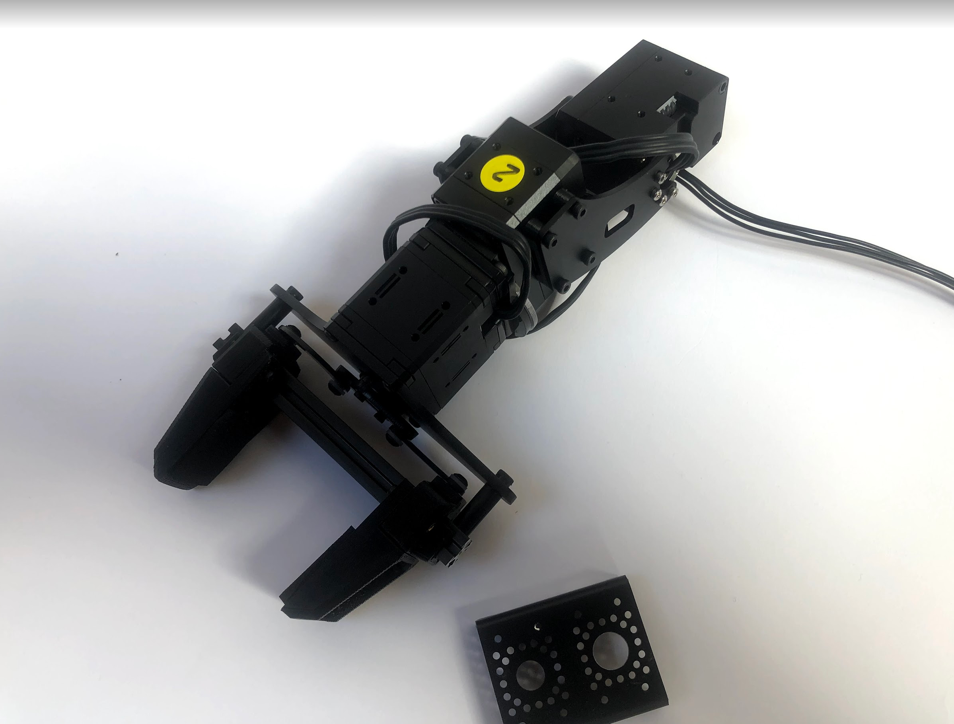
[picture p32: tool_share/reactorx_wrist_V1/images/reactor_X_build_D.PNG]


Recable the servos and attach the pitch and roll joints to the gripper. You're done!

## Other Modifications

The FR12-S101K frame doesn't allow a X-Series TTL connector to pass through by default. You will need to drill out one of the 8mm holes on a drill press to 10mm. This will allow the cable routing to go through the center of Wrist Yaw rotation (recommended)

## Dynamixel Configuration

The Dynamixel servos that come with the Reactor arm need to be reprogrammed with the correct IDs and baudrate. Out of the box, the Reactor servos use a baudrate of 1Mbps while Stretch requires 115200Kbps. To reconfigure the servos:

1. Download and install the Dynamixel Wizard 2.0 from Robotis
2. Attach your 3 DOF gripper-wrist to a PC using a U2D2 adapter from Robotis
3. Launch the Wizard and click Scan. It should identify the three servos.
4. Select each servo from the left hand drop down menu and set its baudrate and ID. Hit save.

By convention we use Dynamixel IDs of:

* Wrist PITCH: 14
* Wrist ROLL: 15
* Gripper: 16

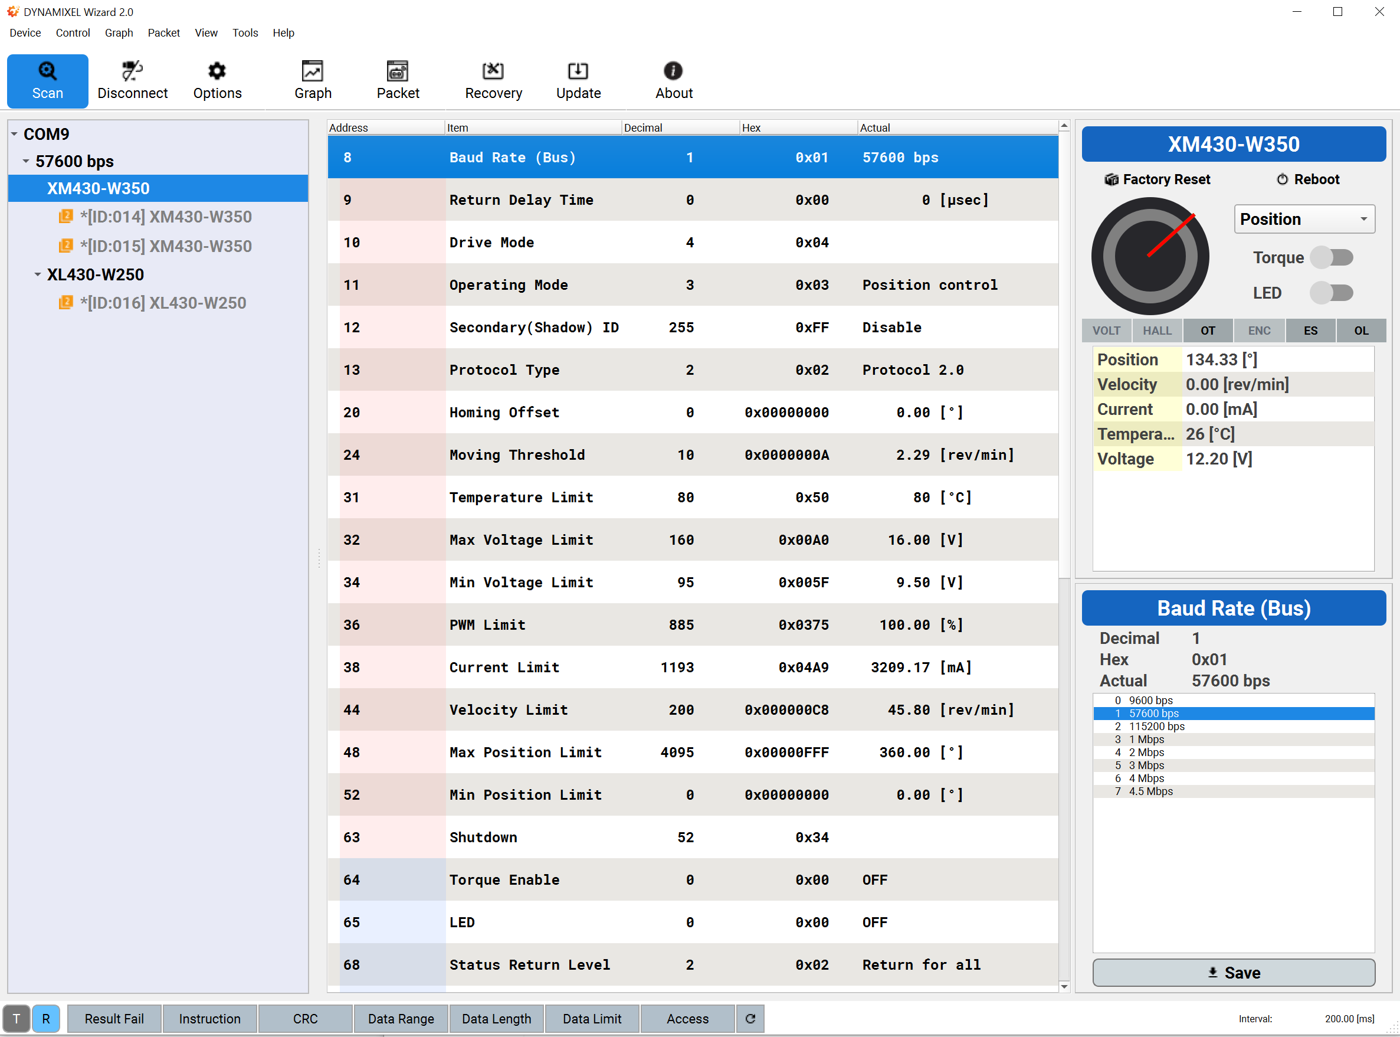
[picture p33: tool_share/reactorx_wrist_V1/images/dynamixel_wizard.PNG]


## Assembly instructions

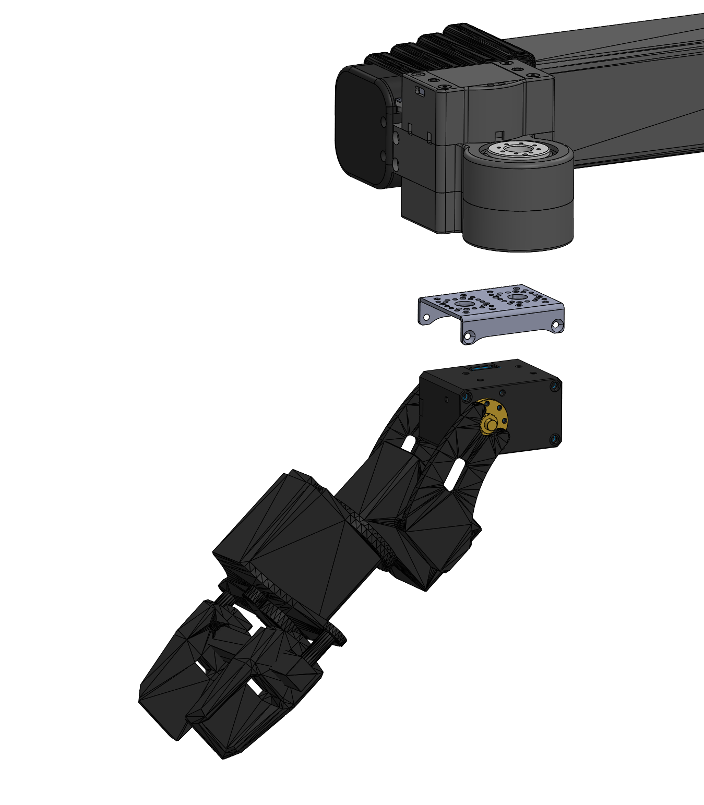
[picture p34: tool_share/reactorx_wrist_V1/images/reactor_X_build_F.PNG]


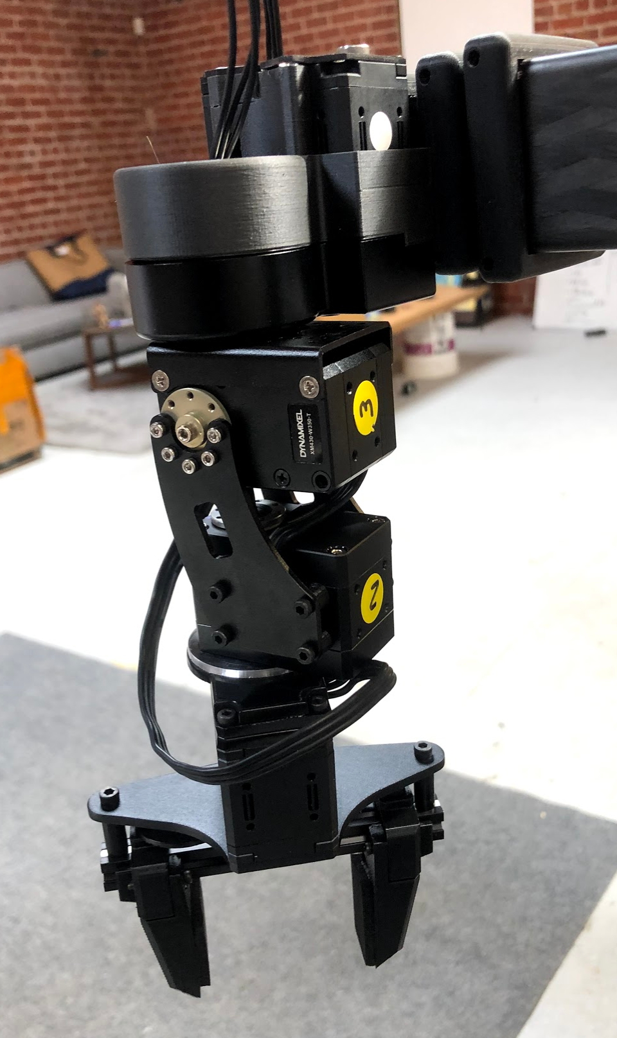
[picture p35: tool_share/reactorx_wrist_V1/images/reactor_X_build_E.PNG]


Now attach your wrist to the Stretch tool plate using the Robotis Frame and their provided hardware, as shown above.

## Code

You're ready to start using your wrist. Once it is plugged into the robot you will want to:

### Install Stretch Tool Share

```bash
>>$ pip install -U hello-robot-stretch-tool-share
```

#### Backup User YAML

```
$ cd $HELLO_FLEET_PATH/$HELLO_FLEET_ID
$ cp stretch_user_params.yaml stretch_user_params.yaml.bak
```

#### Update User YAML

```yaml
   robot:
     tool: tool_reactor_wrist
     params: ['stretch_tool_share.reactorx_wrist_v1.params']
   lift:
     i_feedforward: 0.75
   hello-motor-lift:
     gains:
       i_safety_feedforward: 0.75
```

#### Set the Baud Rate

The default YAML for the Reactor wrist is set to 115200. Your robot may be running at 57600. 

You can check the current baud settings by:

```bash
>>$ stretch_params.py | grep baud
stretch_body.robot_params.nominal_params   param.end_of_arm.baud                                                  115200                        
stretch_body.robot_params.nominal_params   param.head.baud                                                        115200                        
stretch_body.robot_params.nominal_params   param.head_pan.baud                                                    115200                        
stretch_body.robot_params.nominal_params   param.head_tilt.baud                                                   115200                        
stretch_body.robot_params.nominal_params   param.stretch_gripper.baud                                             115200                        
stretch_body.robot_params.nominal_params   param.tool_none.baud                                                   115200                        
stretch_body.robot_params.nominal_params   param.tool_stretch_gripper.baud                                        115200                        
stretch_body.robot_params.nominal_params   param.wrist_yaw.baud                                                   115200  
```

You can change the baud for a joint (eg ID 15)

```bash
>>$ REx_dynamixel_set_baud.py /dev/hello-dynamixel-wrist 15 115200
```

Ensure that all baud rates are at 115200 for the end-of-arm (IDs 13, 14, 15, 16)

#### Jog the Wrist

Try out the jog tool

```bash
>>$ reactor_wrist_jog.py
```

## Important Notes
With the release of the Stretch Dex Wrist, the Reactor Wrist build is not being actively supported by Hello Robot. Parameters describing the range of motion of the wrist pitch, roll, and gripper were most recently updated by [Kavya Puthuveetil](https://kpputhuveetil.github.io/) from [RCHI Lab @ CMU](https://rchi-lab.github.io/) for an independent research project using the Reactor X Wrist in September 2022. As a result, these values may not match the convention used for other end of arm tools in Stretch Tool Share created by Hello Robot. We provide visualizations of the updated range of motion and zero position of each joint here for your reference.

### Wrist Pitch
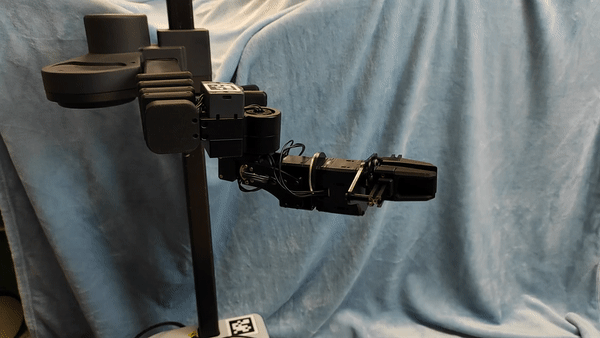
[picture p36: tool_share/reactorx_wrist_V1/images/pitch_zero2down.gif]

Pitch Angle = 0 &rarr; Pitch Angle = π/2

### Wrist Roll
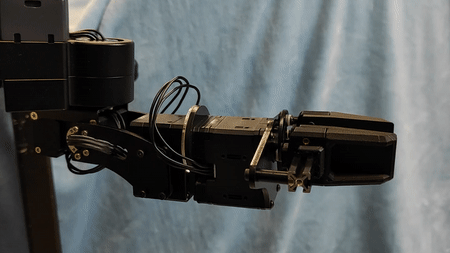
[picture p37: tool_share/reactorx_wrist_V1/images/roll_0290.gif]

Roll Angle = 0 &rarr; Roll Angle = π

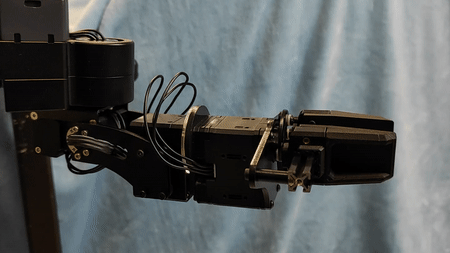
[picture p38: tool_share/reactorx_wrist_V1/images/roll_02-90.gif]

Roll Angle = 0 &rarr; Roll Angle = -π

### Gripper
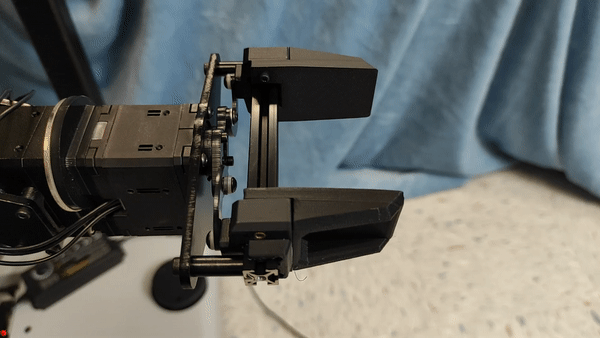
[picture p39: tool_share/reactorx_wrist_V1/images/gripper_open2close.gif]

Gripper Angle = π/2 &rarr; Gripper Angle = 0

### Example: All Joints Zeroed
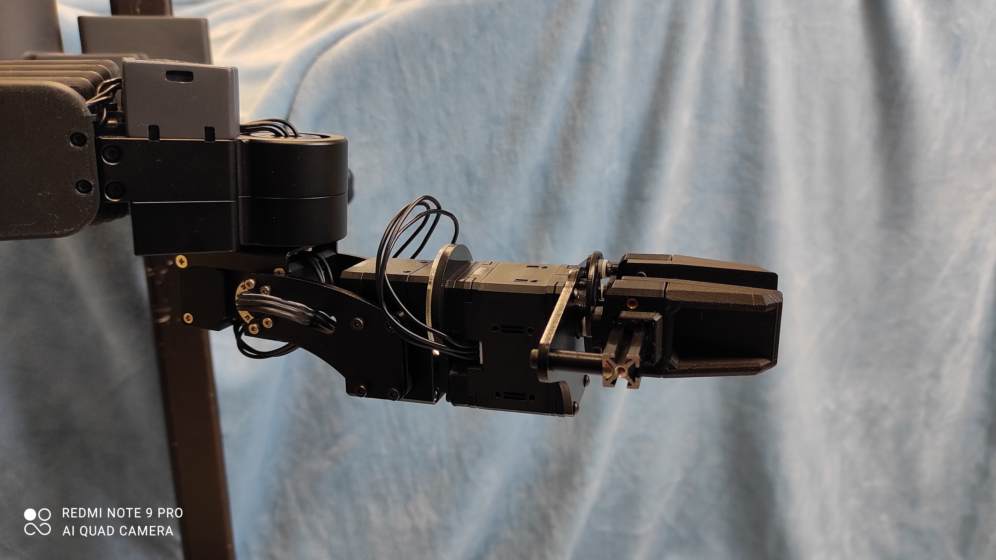
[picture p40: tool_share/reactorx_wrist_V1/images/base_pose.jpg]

Pitch, Roll, Gripper Angle = 0

### Modifying Reactor X Wrist Parameters
To customize the range of motion or zero position of any of the gripper joints for your own application, you can modify the 'range_t' and 'zero_t' parameters, respectively, defined in `stretch_tool_share/python/stretch_tool_share/reactorx_wrist_v1/params.py`.

Note that your changes will not be applied unless you override the system version of the Python package `hello-robot-stretch-tool-share` with a local install. To do this, execute the file `stretch_tool_share/python/local_install.sh` by navigating to the `stretch_tool_share/python` directory and running:

```
./ local_install.sh
```

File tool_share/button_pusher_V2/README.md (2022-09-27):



## Button Pusher

**Create by**: Hello Robot Inc. and Henry Evans

A simple part to help Stretch push buttons or anything else you can imagine. The concave shape is designed to avoid blocking the gripper teleop camera, allowing for high-percision and easy use.  

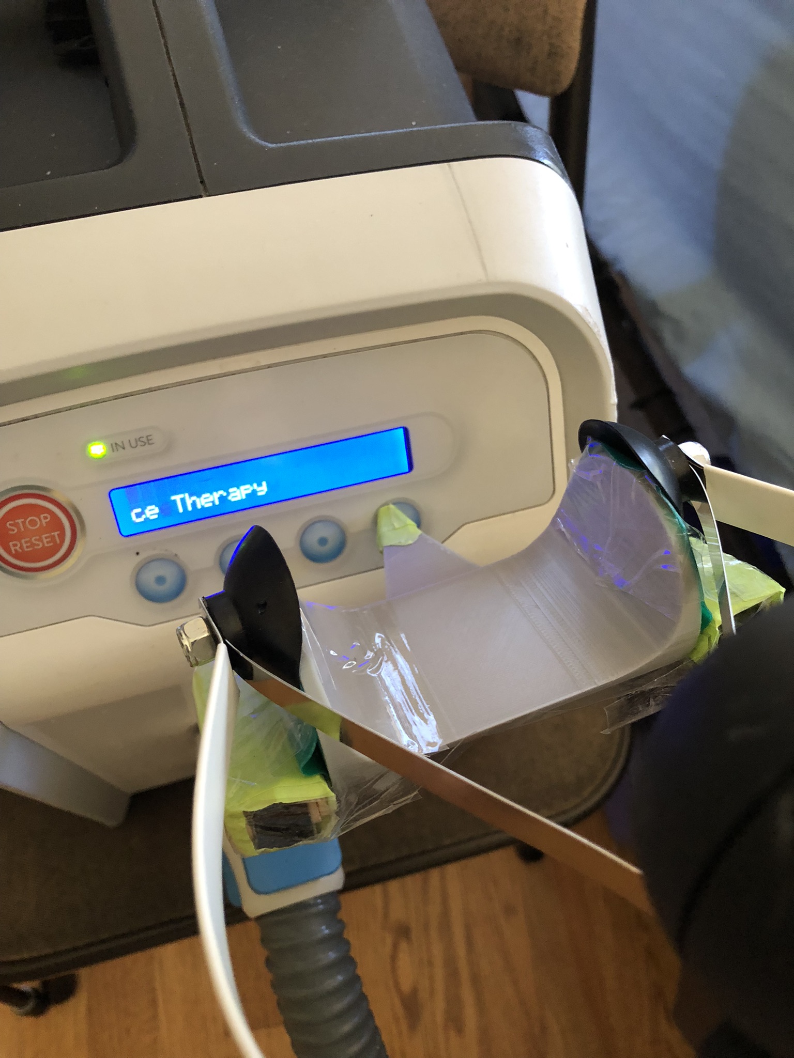
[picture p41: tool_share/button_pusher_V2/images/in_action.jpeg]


We found adding a layer of Dycem non-slip material helped with a more secure grip on the tool. Foam or cardboard blocks under each gripper pad may help stabilize as well. 

## Parts List

| Item | Qty | Vendor |
| --- |:---:| -----: |
| [button_pusher_V2.stl](CAD/button_pusher_V2.stl) | 1 | PLA 3D printer|
| [Dycem](https://www.dycem-ns.com/dycemshop/product/non-slip-reel/) | 1 | Various|

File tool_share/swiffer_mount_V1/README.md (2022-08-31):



## Swiffer Mount

**Created by**: Hello Robot Inc

This tool allows a Swiffer duster to your Stretch. The designs uses a clamp to hold the Swiffer handle in place, allowing the height and orientation of the Swiffer to be adjusted by loosening the clamp.

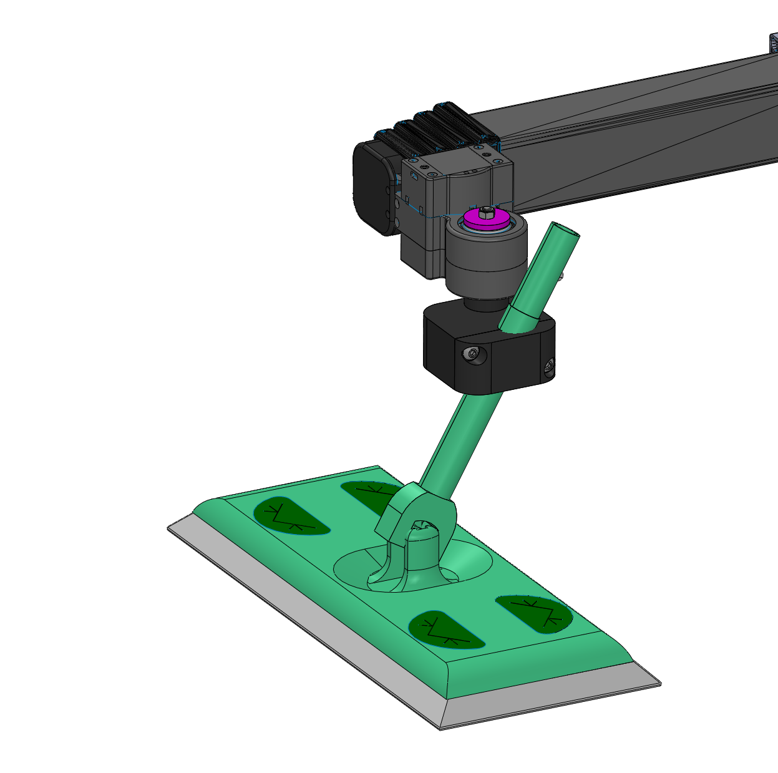
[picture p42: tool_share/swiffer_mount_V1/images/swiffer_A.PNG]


## Parts List

| Item | Qty | Vendor |
|---|:---:| -----: |
| [M5x50mm BHCS](https://www.mcmaster.com/92095A228) | 3 | McMaster-Carr|
| [M5 nut](https://www.mcmaster.com/93330a449) | 4 | McMaster-Carr|
| [swiffer_mount.STL](CAD/swiffer_mount.STL) | 1 | PLA 3D printer|
| [swiffer_mount_clamp.STL](CAD/swiffer_mount_clamp.STL) | 1 | PLA 3D printer |
| [wrist_end_cap_5mm.STL](CAD/wrist_end_cap_5mm.STL) | 1 | PLA 3D printer |
| [Swiffer Sweeper Cleaner Dry and Wet Mop Kit](https://www.amazon.com/gp/product/B00N6FT6TM/ref=ppx_yo_dt_b_asin_title_o08_s00?ie=UTF8&psc=1) | 1 | Amazon |

## Assembly instructions
[View 3D Assembly](CAD/ASSEM_Swiffer_Holder_V1.STL)





1. Attach the M5 bolt through the swiffer_mount_primary part and lock into place by tightening the M5 nut
2. Attach  swiffer_mount_primary to the tool plate using the wrist_end_cap_5mm and a second M5 nut. Friction holds the assembly in place against the tool plate.
3. Attach the swiffer_mount_clamp part using two M5 bolts and nuts, clamping the shaft of the Swiffer handle in place. Adjust the length and orientation of the Swiffer and clamp in place.
4. Clean away!

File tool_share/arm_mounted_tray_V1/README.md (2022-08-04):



# Arm-Mounted Tray

**Created by**: Hello Robot Inc

## Overview

Stretch carrying condiments

This tray conveniently clips onto Stretch's first arm link to provide a surface for carrying objects, including two hooks in the front and a cup holder to assist a variety of tasks. 

## Parts List

| Item | Qty | Vendor |
| --- |:---:| -----: |
| [Tray](CAD/stretch_tray.STL) | 1 | PLA 3D Printer |
| [Arm Clips](CAD/tray_clip.STL) | 2 | PLA 3D Printer |
| [M4x6mm Socket Head Screw](https://www.mcmaster.com/91292A107/) | 4 | McMaster-Carr |
| [M4 Nut](https://www.mcmaster.com/91828A231/) | 4 | McMaster-Carr |

## Assembly instructions
[View 3D assembly](CAD/stretch_arm_tray_asm.STL)

Exploded View

1. Install one M4 screw through each tray hole, and secure each with an M4 nut set in the tray clips. Ensure the hooks on the tray clips are facing the flat side of the tray, away from the cupholder.
2. Press the tray onto the first arm link until it snaps into place.

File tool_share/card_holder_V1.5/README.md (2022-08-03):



## Easy-Access Playing Card Holder

**Created by**: Hello Robot Inc

Card holder in use

A spinning card holder that Stretch can manipulate to position cards in an optimal position for grasping or to signal which card an opponent should take. 

Card holder in use

## Parts List

| Item | Qty | Vendor |
| --- |:---:| -----: |
| [Gear Wheel](CAD/gear_wheel.STL) | 1 | PLA 3D printer |
| [A Frame](CAD/A_frame.STL) | 1 | PLA 3D printer |
| [Base](CAD/base_v2.STL) | 1 | PLA 3D printer |
| [Pull Tab](CAD/pull_tab.STL) | 1 | PLA 3D printer |
| Foam Block* | 1 | Recycled Material |

*We used extra packing foam, but styrofoam or anything similar should work!

## Assembly instructions

Assembly

1. Cut an approximately 6 inch diameter circle out of the foam. Slice around the perimiter about 2 inches into the foam to create a slot to hold cards.  
2. Gently press the spikes on the front of the gear wheel into the center of the foam circle. Push the axel on the A frame through the hole in the back of the wheel gear and into the foam until the back of the wheel gear meets the front of the A frame. 

3. With the foam and gear wheel secured onto the A frame, push the frame into the openings on the base.

4. Slide the pull tab into the slot on the A Frame. The teeth on the pull tab should interlock with the teeth on the wheel gear so pulling and pushing the tab spins the wheel.

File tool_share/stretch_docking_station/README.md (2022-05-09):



# Stretch Docking Station

**Created by**: Hello Robot Inc

## Overview



The Stretch Docking Station provides automated charging of Stretch. A 110mm Aruco tag on the docking station allows the robot to accomplish visually guided docking. 

## Hardware

Coming soon.

### Assembly

Coming soon.

## Software

Coming soon.

### ROS Support

#### URDF

The Stretch Docking Station,  can be included in Gazebo and RViz. The URDF data is [available on the Stretch Tool Share](https://github.com/hello-robot/stretch_tool_share/tree/master/tool_share/stretch_docking_station/stretch_docking_station_description).

```bash

x

```

### Gazebo

Coming soon.

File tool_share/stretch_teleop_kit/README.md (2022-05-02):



# Stretch Teleop Kit

**Created by**: Hello Robot Inc

## Overview







The Stretch Teleop Kit allows for improved remote teleoperation of Stretch. It adds two fish-eye USB cameras to Stretch. One is added to the robot's gripper for a better view while manipulating. The other is added to the robot's head and points downward, providing a better view while navigating. 

## Hardware

The Stretch Teleop Kit uses [two Spinel UC20MPE_F185 USB cameras](https://store.spinelelectronics.com/UC20MPE_F185) that provide a 185 degree FOV and 2MP resolution. These board cameras are mounted in 3D printed shells and attached to existing mount points of the Stretch. 

### Assembly

Hello Robot has [provided the STL files, BOM, and assembly instructions necessary](images/Stretch_RE1_Teleop_Kit_Build.pdf) to build your own Stretch Teleop Kit. Alternatively, the kit is [available for sale by Hello Robot](https://hello-robot.com/). 

**Note if building your own kit:*: The Spinel cameras come with a custom USB to JST ZH cable. We recommend using a custom length cable however in order to improve the cable routing of your system. Please contact Hello Robot for details. 

| 3D Printed Parts                                             |
| ------------------------------------------------------------ |
| [3DP-808_Teleop_Camera_Mount_Front.STL](CAD/3DP-808_Teleop_Camera_Mount_Front.STL) |
| [3DP-809_Head_Teleop_Mount_Back.STL](CAD/3DP-809_Head_Teleop_Mount_Back.STL) |
| [3DP-810_Head_Teleop_Mount.STL](CAD/3DP-810_Head_Teleop_Mount.STL) |
| [3DP-811_Gripper_Teleop_Mount_Back.STL](CAD/3DP-811_Gripper_Teleop_Mount_Back.STL) |
| [3DP-812_Gripper_Teleop_Mount_Bottom.STL](CAD/3DP-812_Gripper_Teleop_Mount_Bottom.STL) |

## Software

### Teleoperation Interface

The Stretch Teleop Kit includes the [open-source teleoperation interface (beta)](https://github.com/hello-robot/stretch_fisheye_web_interface) that utilizes these cameras as shown below. 



### ROS Support

#### URDF

The Stretch RE1 URDF can be augmented with these two cameras as well. The URDF information [is found here](./stretch_description).

To add the Teleop Kit to your URDF:

```bash
cd ~/catkin_ws/src/stretch_ros/
git pull

cd ~/repos
git clone https://github.com/hello-robot/stretch_tool_share

cd ~/repos/stretch_tool_share/tool_share/stretch_teleop_kit/stretch_description
cp urdf/stretch_teleop_kit.xacro ~/catkin_ws/src/stretch_ros/stretch_description/urdf
cp urdf/stretch_description.xacro ~/catkin_ws/src/stretch_ros/stretch_description/urdf
cp meshes/*teleop*.STL ~/catkin_ws/src/stretch_ros/stretch_description/meshes
```

### Gazebo
The Stretch RE1 robot with the Teleop Kit can also be simulated with [Gazebo](https://gazebosim.org/) simulator. The information on Stretch robot's Gazebo implementation can be found here [stretch_gazebo](https://github.com/hello-robot/stretch_ros/tree/master/stretch_gazebo).

To add Teleop kit to the Stretch Gazebo implementation:

```bash
cd ~/catkin_ws/src/stretch_ros/
git pull

cd ~/repos
git clone https://github.com/hello-robot/stretch_tool_share

cd ~/repos/stretch_tool_share/tool_share/stretch_teleop_kit/stretch_description
cp urdf/stretch_teleop_kit.xacro ~/catkin_ws/src/stretch_ros/stretch_description/urdf
cp urdf/stretch_gazebo.urdf.xacro ~/catkin_ws/src/stretch_ros/stretch_gazebo/urdf/stretch_gazebo.urdf.xacro
cp meshes/*teleop*.STL ~/catkin_ws/src/stretch_ros/stretch_description/meshes
```

During Gazebo simulation the two Teleop camera's video streams would be published to the topics "teleop/gripper_camera" and "teleop/head_camera".



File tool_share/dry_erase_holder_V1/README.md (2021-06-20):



## Dry Erase Holder

**Created by**: Hello Robot Inc

This tool allows Stretch to hold a dry erase marker.  It is spring loaded, allowing for compliant interaction between the marker and a white board. 

The tool can be integrated into your robot URDF by integrating its [stretch_description](./stretch_description) as described in the [Stretch ROS documentation](https://github.com/hello-robot/stretch_ros/tree/master/stretch_description).



## Parts List

| Item | Qty | Vendor |
| --- |:---:| -----: |
| [Expo Dry Erase](https://www.amazon.com/gp/product/B00006IFIL/ref=ppx_yo_dt_b_asin_title_o04_s00?ie=UTF8&psc=1) | 1 | Amazon |
| [M5x50mm Hex Head Bolt](https://www.mcmaster.com/91287A333) | 1 | McMaster-Carr |
| [M5 Nut](https://www.mcmaster.com/90591A260) | 2 | McMaster-Carr|
| [wrist_end_cap_5mm](CAD/wrist_end_cap_5mm.STL) | 1 | PLA 3D Printer |
| [dry_erase_bushing_block](CAD/dry_erase_bushing_block.STL) | 1 | PLA 3D Printer |
| [Size 30 Rubber Band](https://www.mcmaster.com/12205t76) | 2 | McMaster-Carr |
| [3/4" Shaft Collar](https://www.mcmaster.com/60475k74) | 1 | McMaster-Carr |

## Assembly instructions
[View 3D assembly](CAD/ASSEM_Dry_Erase_Holder_V1.STL)



1. Install the bolt into the dry_erase_bushing block and secure from below with an M5 nut.
2. Attach the dry erase bushing block to the tool plate, securing from below with the wrist_end_cap_5mm and an M5 nut. Orient the block so the marker points forward. 
3. Attach the shaft collar to your dry erase marker, approximately 8mm from the back of the marker.
4. Slide the marker into the bushing block. Loop a rubber band around the back of the marker and over to one of the pegs on the side of the bushing block. Repeat with the other peg.
5. The marker should now easily spring back when pushed against. You're ready to write!

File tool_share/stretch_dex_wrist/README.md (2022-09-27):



## Stretch Dex Wrist

**Created by**: Hello Robot Inc

The [Stretch Dex Wrist](https://hello-robot.com/stretch-dex-wrist) is commercially available from Hello Robot. The following hardware guides are available:

* [RE1 DexWrist Hardware Guide](https://docs.hello-robot.com/0.2/stretch-hardware-guides/docs/dex_wrist_guide_re1/)
* [RE2 DexWrist Hardware Guide](https://docs.hello-robot.com/0.2/stretch-hardware-guides/docs/dex_wrist_guide_re2/)

Additional resources available here include:

* [Gazebo Support](./gazebo_support/README.md)
* [URDF](https://github.com/hello-robot/stretch_tool_share/tree/master/tool_share/stretch_dex_wrist/stretch_description)

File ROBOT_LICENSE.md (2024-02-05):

The following license applies to the entire contents of this directory that represent parts of the Stretch robots (the "Robot Contents"), such as the robot's head, arm, wrist, and default gripper. The Robot Contents consists of software and data for use with the Stretch mobile manipulators, which are robots produced and sold by Hello Robot Inc.

Copyright 2020-2024 Hello Robot Inc.

The Robot Contents are licensed under the Creative Commons Attribution-NonCommercial-ShareAlike-4.0-International (CC BY-NC-SA 4.0) license (the "License"); you may not use the Robot Contents except in compliance with the License. You may obtain a copy of the License at

https://creativecommons.org/licenses/by-nc-sa/4.0/

Unless required by applicable law or agreed to in writing, the Robot Contents distributed under the License are distributed on an "AS IS" BASIS, WITHOUT WARRANTIES OR CONDITIONS OF ANY KIND, either express or implied. See the License for the specific language governing permissions and limitations under the License.

Patents pending and trademark rights cover the Robot Contents. As stated by the detailed License, "Patent and trademark rights are not licensed under this Public License."

For further information about the Robot Contents including inquiries about dual licensing, please contact Hello Robot Inc.

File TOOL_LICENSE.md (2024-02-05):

The following license applies to the contents (the "Tool Contents") in this repository specific to tools created by Hello Robot Inc. that attach to the Stretch robots. This license explicitly excludes any contents covered by the license found in the ROBOT_LICENSE.md file. The Tool Contents does not include any part of the Stretch robot, such as its arm, wrist, or default gripper.

The Tool Contents consists of software and data related to tools intended for use with the Stretch mobile manipulators, which are robots produced and sold by Hello Robot Inc.

Copyright 2020-2024 Hello Robot Inc.

The Tool Contents are licensed under the Apache License, Version 2.0 (the "License"). You may not use the Tool Contents except in compliance with the License. You may obtain a copy of the License at

http://www.apache.org/licenses/LICENSE-2.0

Unless required by applicable law or agreed to in writing, the Tool Contents are distributed under the License are distributed on an "AS IS" BASIS, WITHOUT WARRANTIES OR CONDITIONS OF ANY KIND, either express or implied. See the License for the specific language governing permissions and limitations under the License.
   
For further information about the Tool Contents including inquiries about dual licensing, please contact Hello Robot Inc.

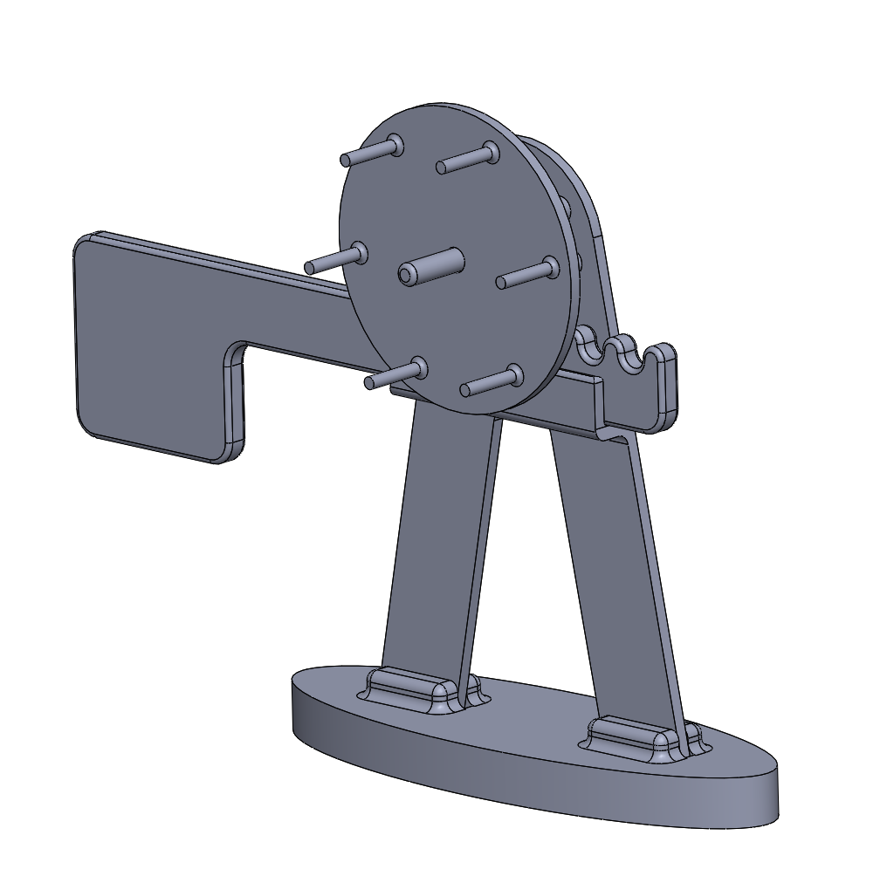
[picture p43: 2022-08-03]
tool_share/card_holder_V1.5/images/card_hold_assm.PNG

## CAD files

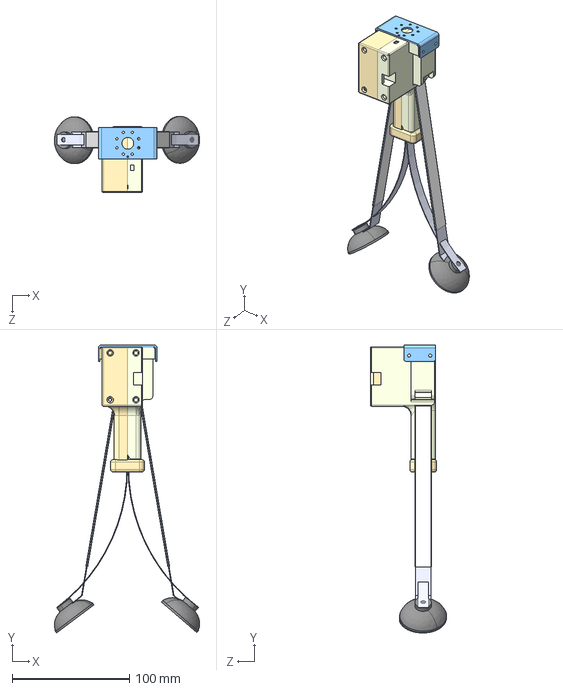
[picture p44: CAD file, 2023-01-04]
tool_share/stretch_2_STEP/CAD/ASM-210_Straight_Gripper_simple.STEP
123.9 x 245.6 x 65.0 mm

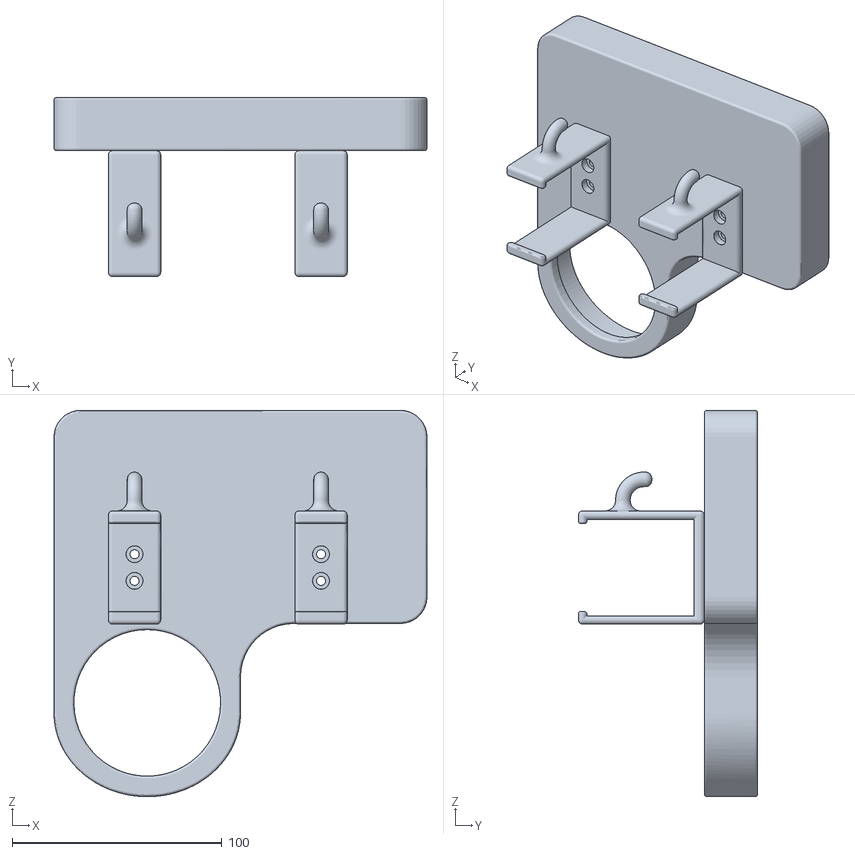
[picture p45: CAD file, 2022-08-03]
tool_share/arm_mounted_tray_V1/CAD/stretch_arm_tray_asm.STL
177.8 x 85.4 x 184.1

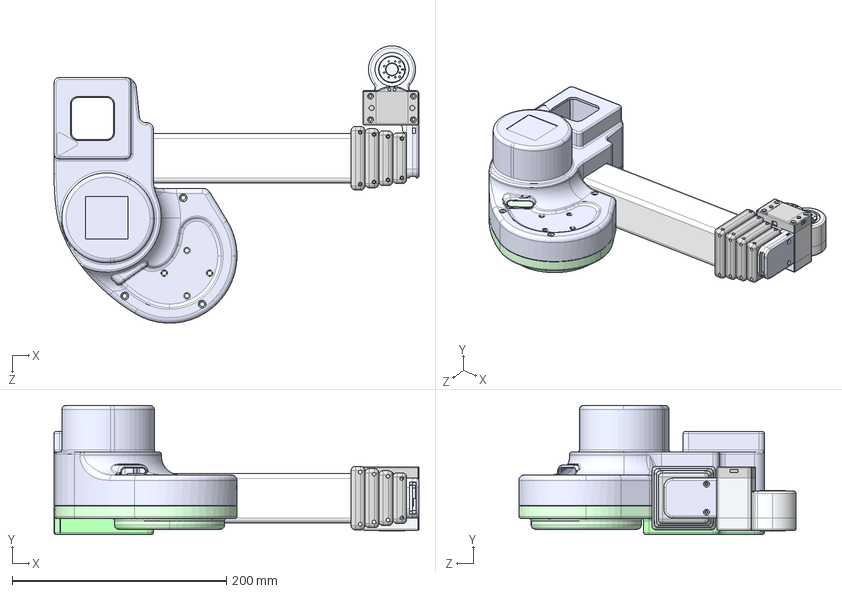
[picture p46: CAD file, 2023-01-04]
tool_share/stretch_2_STEP/CAD/ASM_Arm_with_Wrist_simple.STEP
341.1 x 120.6 x 259.1 mm

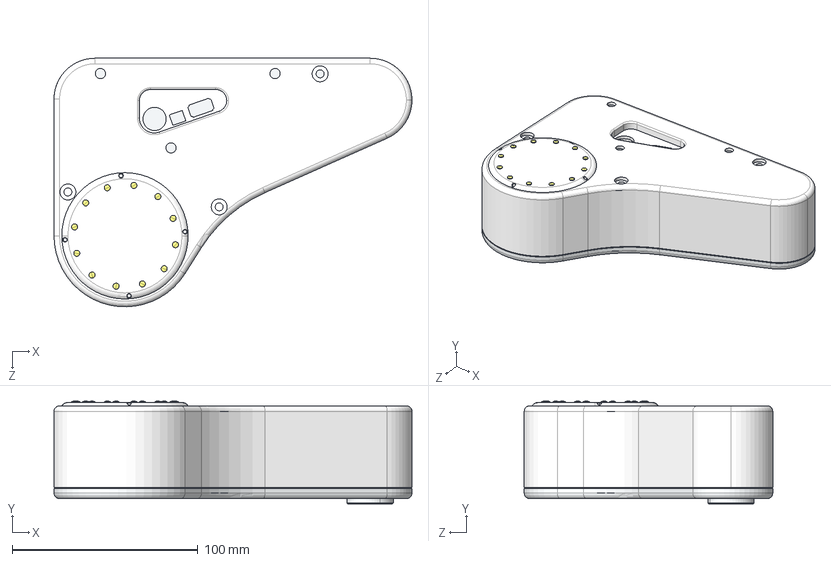
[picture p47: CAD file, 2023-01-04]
tool_share/stretch_2_STEP/CAD/ASM-head_module.STEP
192.7 x 55.4 x 133.8 mm
BIG-924_head_shell
HDW-923_LightPipe_LFB025CTP x 12
HDW-A01_5288T111_Oil-Resistant Buna-N Backup Rings_5288T111 x 4
BIG-926_head_bottom_plate_simple
HDW-920_head_pan_shaft
VND-821_head_mount_plate

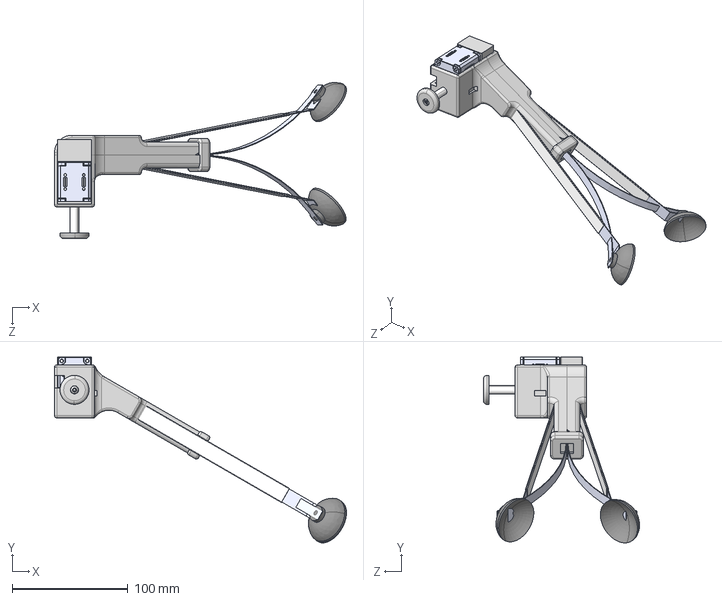
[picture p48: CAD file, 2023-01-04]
tool_share/stretch_2_STEP/CAD/ASM-207_Gripper_Simple.STEP
251.8 x 160.2 x 134.8 mm

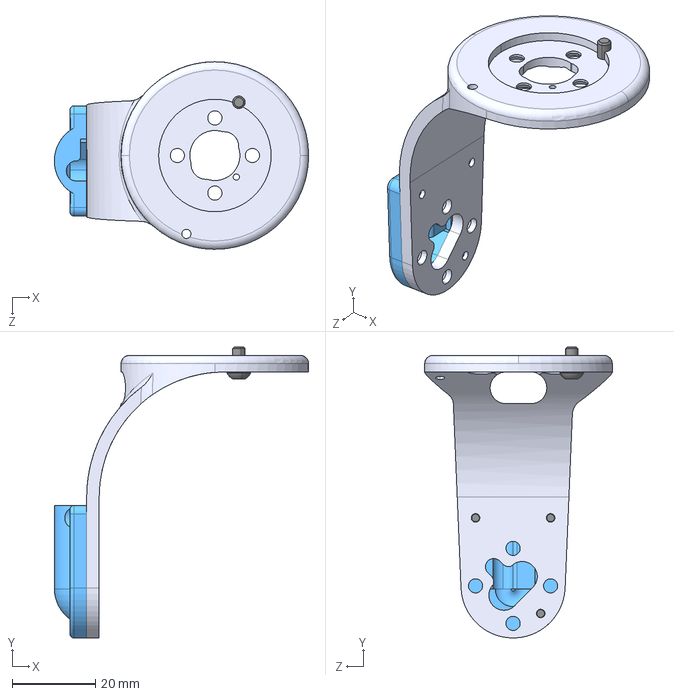
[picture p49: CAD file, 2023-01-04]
tool_share/stretch_2_STEP/CAD/ASM_head_tilt_hanger.STEP
61.0 x 69.8 x 45.0 mm

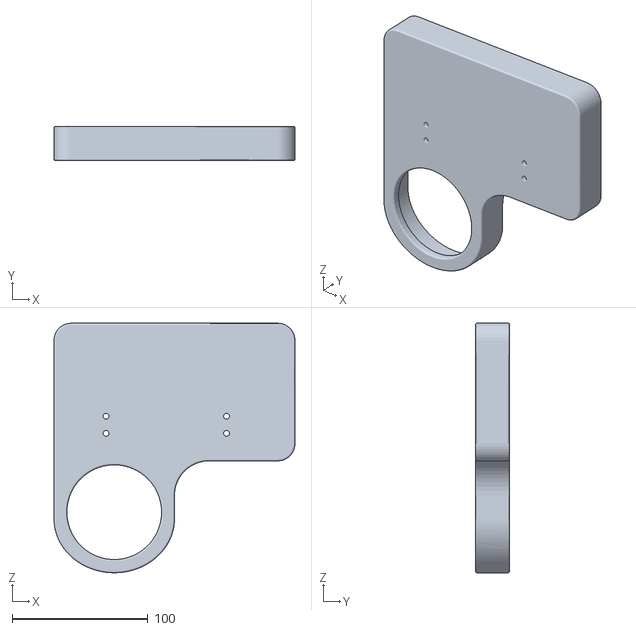
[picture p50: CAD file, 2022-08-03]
tool_share/arm_mounted_tray_V1/CAD/stretch_tray.STL
177.8 x 25.4 x 184.1

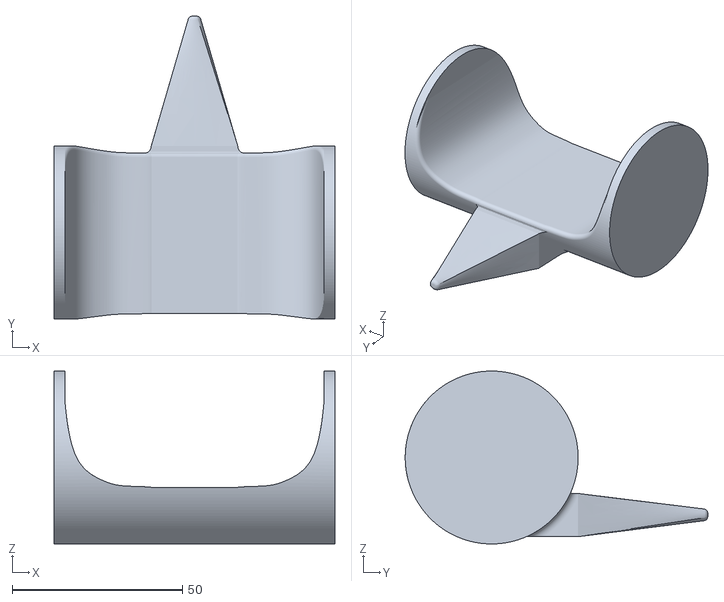
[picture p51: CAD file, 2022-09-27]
tool_share/button_pusher_V2/CAD/button_pusher_V2.stl
82.5 x 88.9 x 50.8

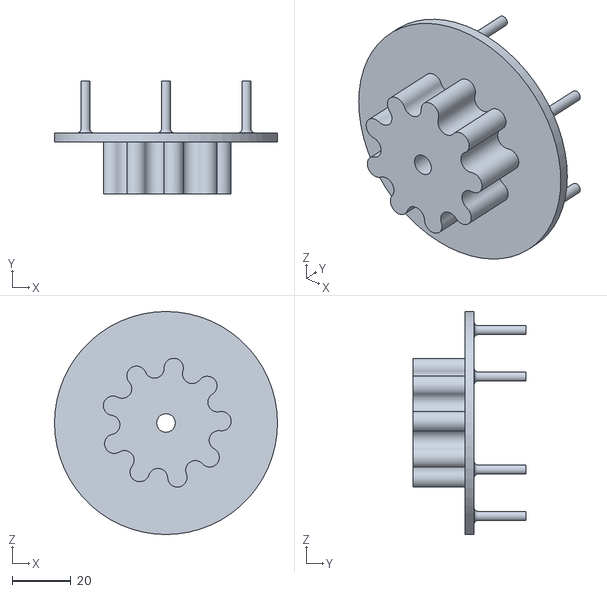
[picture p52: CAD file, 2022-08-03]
tool_share/card_holder_V1.5/CAD/gear_wheel.STL
76.2 x 38.7 x 76.2

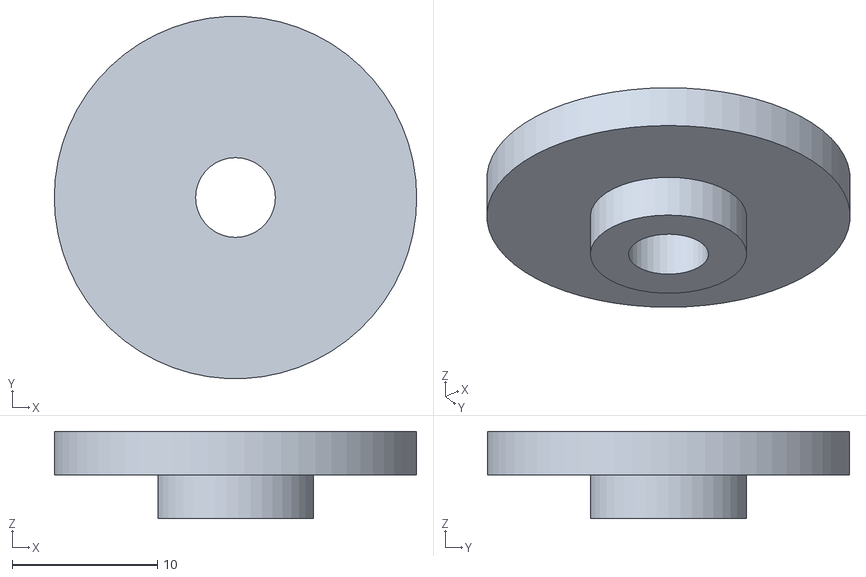
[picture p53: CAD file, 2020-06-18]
tool_share/dry_erase_holder_V1/CAD/wrist_end_cap_5mm.STL
25.0 x 25.0 x 6.00

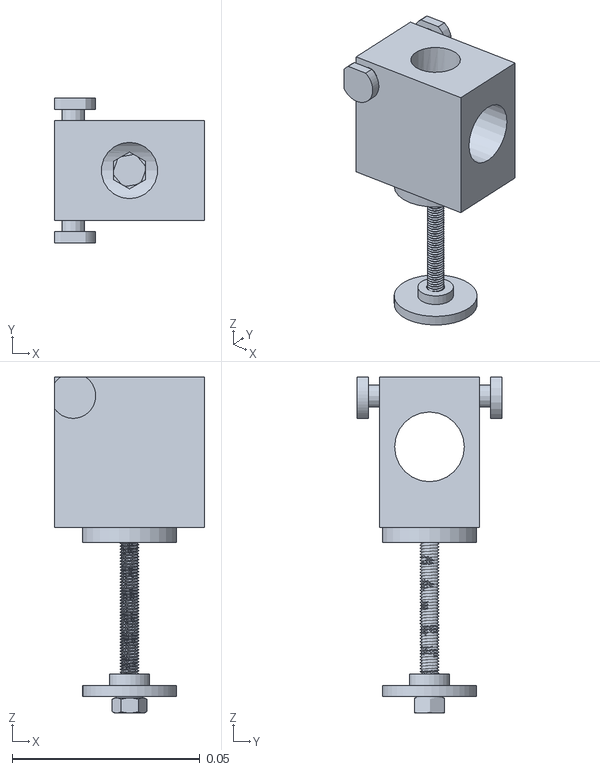
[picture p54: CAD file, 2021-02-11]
tool_share/dry_erase_holder_V1/stretch_description/meshes/link_dry_erase_holder.STL
0.04 x 0.0385 x 0.0894

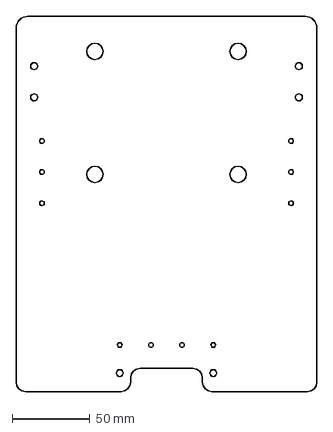
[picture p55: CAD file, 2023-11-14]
tool_share/jetson_orin_agx_mount/CAD/Jetson_Orin_AGX_base_plate_flat_pattern.DXF
193.0 x 241.0 mm

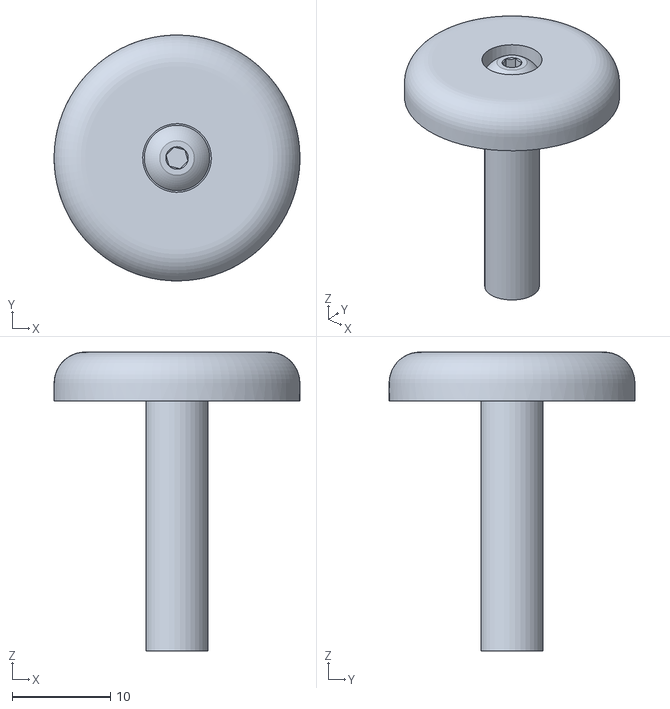
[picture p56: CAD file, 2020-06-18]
tool_share/puller_v1/CAD/ASSEM_Puller_V1.STL
25.0 x 25.0 x 30.4

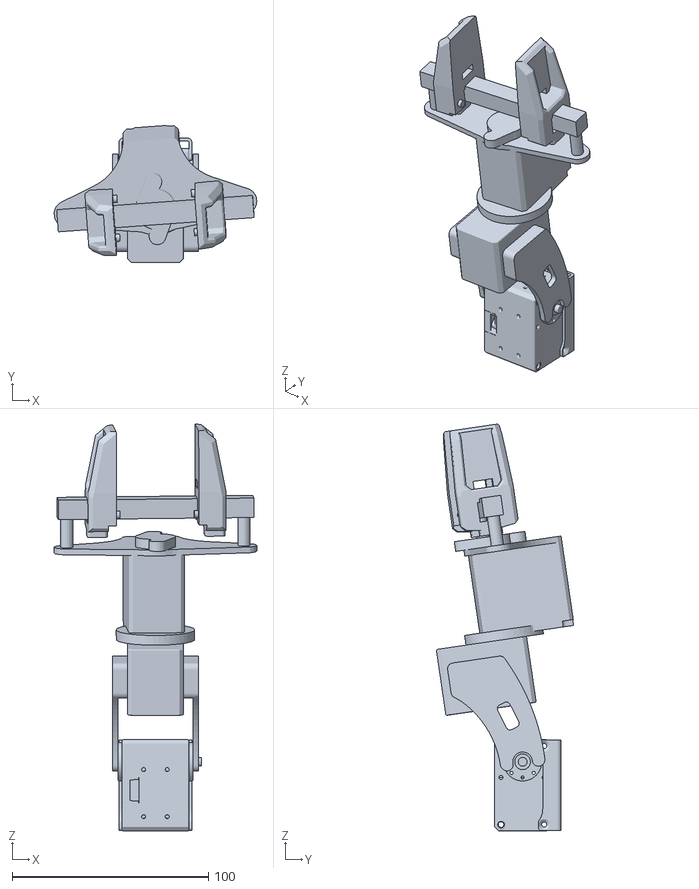
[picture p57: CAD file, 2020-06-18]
tool_share/reactorx_wrist_V1/CAD/ReactorX_Wrist_V1.STL
103.2 x 69.9 x 207.4

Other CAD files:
tool_share/phone_holder_V1/CAD/wrist_mount_spacer.STL
tool_share/stretch_dex_wrist/stretch_description/meshes/link_wrist_roll.STL
tool_share/stretch_dex_wrist_beta/stretch_description/meshes/link_wrist_roll.STL
tool_share/stretch_docking_station/stretch_docking_station_description/meshes/link_docking_aruco.STL
tool_share/card_holder_V1.5/CAD/A_frame.STL
tool_share/card_holder_V1.5/CAD/base_v2.STL
tool_share/card_holder_V1.5/CAD/pull_tab.STL
tool_share/dry_erase_holder_V1/CAD/dry_erase_bushing_block.STL
tool_share/dry_erase_holder_V1/stretch_description/meshes/link_dry_erase_marker.STL
tool_share/puller_v1/CAD/Puller_V1.STL
tool_share/stretch_2_STEP/CAD/HDW-911_gripper_mount_bracket.STEP
tool_share/stretch_2_STEP/CAD/SIM-401_Roll_Hanger_simple.STEP
tool_share/stretch_2_STEP/CAD/SUB-202_head_tilt_simple.STEP
tool_share/stretch_2_STEP/CAD/SUB-216_Dex_Wrist_simple.STEP
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

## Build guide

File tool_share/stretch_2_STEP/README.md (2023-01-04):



## Stretch 2 Model

**Created by**: Hello Robot Inc

This is a STEP model of the Stretch 2 robot (Nina batch). It includes a poseable SolidWorks SLDASM of the mated STEP files for both the standard Stretch 2 and the DexWrist Stretch 2 . It can assist the design of your own tools for your Stretch. 



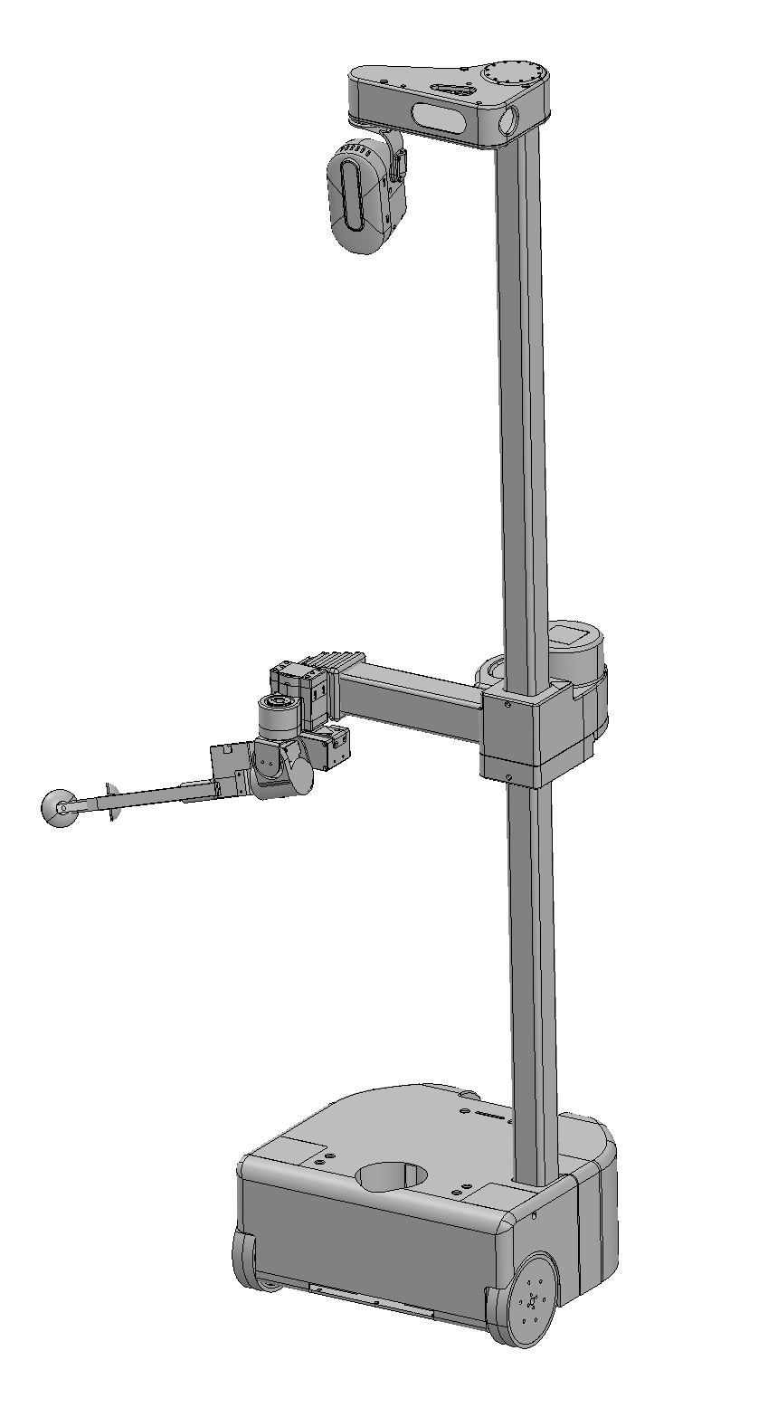
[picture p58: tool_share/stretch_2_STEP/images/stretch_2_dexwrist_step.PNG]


| Files      |
| ---------- |
| [CAD](CAD) |

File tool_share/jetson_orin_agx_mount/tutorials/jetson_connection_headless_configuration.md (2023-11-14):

# Jetson Connection Via Headless Configuration
**Note**
    If you didn't configure your Jetson with the SDK Manager because of the Ubuntu versions then maybe this could be of great help for you.

As always there are several ways to enter your Jetson with only a terminal for the first one you can read it in the [documentation](https://developer.nvidia.com/embedded/learn/get-started-jetson-agx-orin-devkit) that NVIDIA has or read it below:

## Connecting via screen command
**Note**
    To check the hardware layout of the Jetson AGX Orin click [here](https://developer.nvidia.com/embedded/learn/jetson-agx-orin-devkit-user-guide/developer_kit_layout.html).
1. First you will need to connect in the USB micro-B port ( **9** ) the micro USB cable into one of Stretch's USB ports. If you want to connect an ethernet cable is completly optional.
2. Then connect the included power supply into the USB Type-C™ port above the DC jack ( **4** ).
3. Your developer kit should automatically power on, and the white LED near the power button will light. If not, press the Power button ( **1** ).
4. Wait up to 1 minute.
5. On your computer, use a serial terminal application to connect via host serial port to the developer kit

Now that you have done this steps it's time to connect to our Jetson, you can use a Windows, Mac or Linux computer for this, the next steps are going to be in Linux:

First you will need to locate the **tty** device in your terminal, to do this you can write down

```{.bash .shell-prompt}
dmesg | grep --color 'tty'
```

If you didn't have your Jetson connected with the micro usb you can connect it and try again and see what's different it should appear something like this:
```{.bash .shell-prompt}
[ xxxx.xxxxxx] cdc_acm 1-3.3.4:1.1: ttyACM3: USB ACM device
```

In case you want to check it better you can input the command
```{.bash .shell-prompt}
ls -l /dev/ttyACM3   # In our case was ACM3
```

And it should output the general information of the ttyACM3 device
```{.bash .shell-prompt}
crw-rw---- 1 root dialout 166, 3 Aug 24 10:42 /dev/ttyACM3
```

Now for the connection part, if you don't have installed the screen program in Linux you can install it writing down this in the terminal:
```{.bash .shell-prompt}
sudo apt-get install -y screen
```

Now with the device name discover in the previous step you can use it to input the screen command:
```{.bash .shell-prompt}
sudo screen /dev/ttyACM3 115200
```
And now in your terminal you will have to login in your ubuntu account that you have on the jetson.

<p align="center">
  
</p>

**Note**
    If you didn't configure your Jetson with the SDK Manager you can complete the CUI-based "Jetson Initial configuration" (oem-config) using your PC's keyboard. Read the NVIDIA [documentation](https://developer.nvidia.com/embedded/learn/get-started-jetson-agx-orin-devkit).

## Connecting via SSH
For this type of connection first we need to know what's our board IP Adress. This is for the ones that have a serial console access, use the ifconfig command to get the required information in the Jetson terminal: 
```{.bash .shell-prompt}
hello-robot@ubuntu:~$ ifconfig

...

eth0: flags=4099<UP,BROADCAST,MULTICAST>  mtu 1500
    	inet 10.1.10.205  netmask 255.255.255.0  broadcast 10.1.10.205

wlan0: flags=4163<UP,BROADCAST,RUNNING,MULTICAST>  mtu 1500
    	inet 10.1.10.205  netmask 255.255.255.0  broadcast 10.1.10.205
    	
```
This will show you all the connections that your Jetson has and you can have 2 output options with the IP address, the first one is if you have your Jetson connected to the internet via ethernet cable, with this the IP address will show up in the ethernet section, the second one is if you don't have an ethernet cable connected and instead you are connected via normal internet connection then the IP address will show up in the wlan0 section. With this now you can conncect your Jetson via SSH, if you have your Jetson connected to a monitor and you want to try it on Stretch follow the assembly instructions and then from your Stretch terminal just input the next command:
```{.bash .shell-prompt}
ssh jetson-username@ip-address
```
And now you will need to write the password that you configure and that's it, see below the output after you write down your password:
```{.bash .shell-prompt}
jetson-username@ip-address password:

Welcome to Ubuntu 20.04.6 LTS (GNU/Linux 5.10.120-tegra aarch64)

 * Documentation:  https://help.ubuntu.com
 * Management:     https://landscape.canonical.com
 * Support:        https://ubuntu.com/advantage

This system has been minimized by removing packages and content that are
not required on a system that users do not log into.

To restore this content, you can run the 'unminimize' command.

Expanded Security Maintenance for Applications is not enabled.

9 updates can be applied immediately.
9 of these updates are standard security updates.
To see these additional updates run: apt list --upgradable

35 additional security updates can be applied with ESM Apps.
Learn more about enabling ESM Apps service at https://ubuntu.com/esm

Last login: Thu Aug 24 10:21:30 2023
```
Now you can create your own projects using the Jetson of your preference! You go and watch the Github Repository from NVIDIA called [Jetson Inference](https://github.com/dusty-nv/jetson-inference/tree/master) there are some tutorials for inference and real time vision or even a docker file with ROS to try your own projects.

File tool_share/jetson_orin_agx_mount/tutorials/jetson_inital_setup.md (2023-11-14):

# Jetson Initial Setup Tutorial
**Warning**
    This is only if you are flashing the Jetson for the first time, because every data that you have in here will be erased completely, this is only for the first time.

**Note**
    The connection between the Jetson and the robot computer is by micro usb.

## Step 1
To begin with this tutorial you must have installed the NVIDIA SDK Manager and also have your Jetson in Force Recovery Mode, if you haven't done that you can go and see the [README](https://github.com/hello-robot/stretch_tool_share/blob/feature/jetson_tutorials/tool_share/jetson_orin_agx_mount/tutorials/README.md) file and then come back.

## Step 2
Once the SDK Manager it’s installed and already running you’ll need to select the appropriate login tab.

<p align="center">

</p>

## Step 3
Once you log in it will show you the step by step tutorial that you need to follow, we recommend that you have the latest version of jetpack installed and it depends if you want to disable the Host Machine button or the Additional SDKS button, then click the continue button.
<p align="center">

</p>

## Step 4
Don’t worry if it doesn’t detect your board you can check that later in step 2-3 from the SDK Manager, in those steps you will select, download and install the components that you want to have for your Jetson, this will take around 20-40 minutes to download depending on your internet connection and around 40-45 minute to install all the components.
<p align="center">

</p>

## Step 5
During the process of the installation the SDK Manager will show you up a dialog when it's ready to flash your Jetson, you’ll need to select the appropriate board, in our case the Jetson AGX Orin, but if you have another one like the AGX Xavier like the image from below it’s also fine!
<p align="center">

</p>

You can see that there are 2 options, the automatic setup or the manual setup, we would recommend to use the manual setup and configure by your own the OEM Configuration and the Storage Device, if you have your board connected but the SDK Manager doesn’t detect it, at least for the Jetson Orin AGX, click the refresh button but if this doesn’t work you can watch the troubleshooting section below.

Once you have done all of this and everything is installed then you are finished, you can start to configure the Jetson, with a monitor is easier! Now you can check how to run docker with ROS2 in your Jetson and start your own projects for deep learning. 

If you want tu **shutdown** your Jetson you could input the command `sudo shutdown -h now` in your Jetson terminal, also you can do it via GUI but sometimes the Jetson's fan may still be working, so to avoid this it's better to do it the CLI way.

# Troubleshooting
**Note**
    To check the hardware layout of the Jetson AGX Orin click [here](https://developer.nvidia.com/embedded/learn/jetson-agx-orin-devkit-user-guide/developer_kit_layout.html).

If the SDK Manager isn’t detecting your board, at least with the AGX Orin, you’ll need to do the following steps:
1. Be sure that your Jetson is in Force Recovery mode
2. To be sure open a terminal (Ctrl + Alt + T) and write down lsusb
3. To determine whether the Dev Kit is in recovery mode once you write the lsusb command you’ll need to see Bus <bbb> Device <ddd>: ID 0955: <nnnn> Nvidia Corp. Which <bbb> and <ddd> is any 3 digit number and <nnnn> it’s a four digit number that represents the type of your Jetson module, for more information read the [NVIDIA documentation](https://docs.nvidia.com/jetson/archives/r35.4.1/DeveloperGuide/text/IN/QuickStart.html) all the way down.
4. If your <nnnn> doesn’t match the correct module name with the Jetson AGX Orin, for example instead of 7023 is 7045, you’ll need to unplug the micro USB and press the Force Recovery Button ( **2** ) + Reset Button( **3** ), with this you’ll be able to enter the Force Recovery mode, and just in case keep pressing the Force Recovery button and then plug in the micro USB again.
5. Now check with the command lsusb and it should appear the correct <nnnn>, in the case of our Jetson AGX Orin it was 7023.
6. Now continue with the installation in your SDK Manager and you are good to go.

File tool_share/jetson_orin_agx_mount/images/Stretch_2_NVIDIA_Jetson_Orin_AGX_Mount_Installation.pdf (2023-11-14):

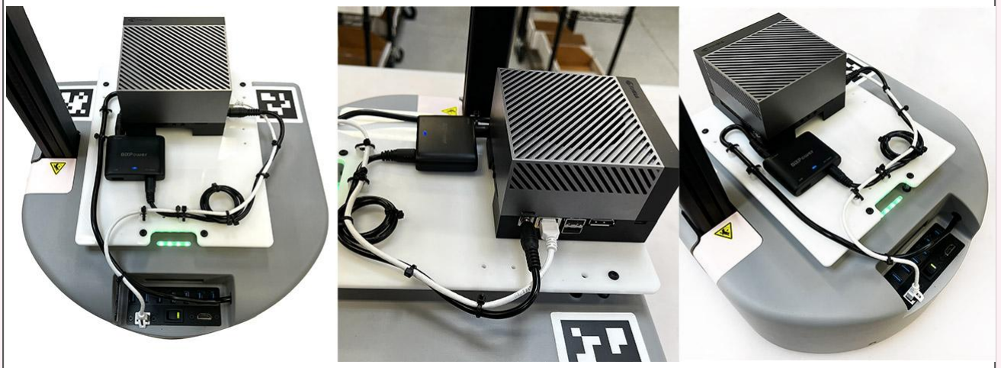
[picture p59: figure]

# STRETCH 2

# NVIDIA Jetson Orin AGX Mount -Installation

2023

Confidential © Hello Robot

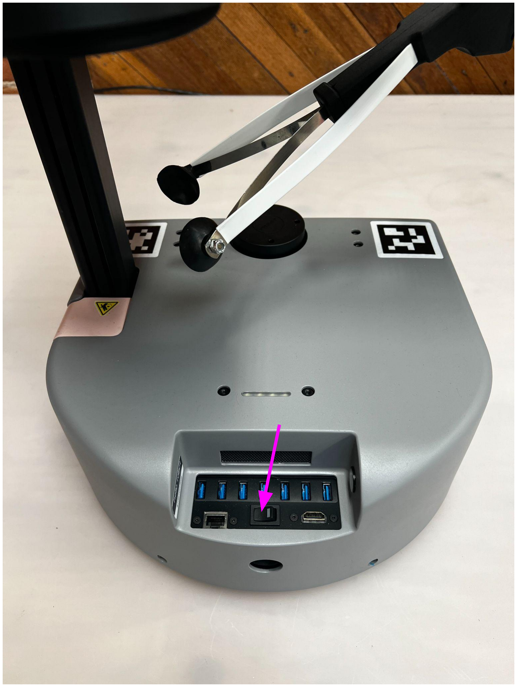
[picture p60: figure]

This guide will show you how to install the Jetson Mount to a Stretch RE2 robot.

- WARNING: Before beginning, ensure that your robot is completely powered down, with the power switch is in the OFF position, pictured here.
- Failure to do this may result in permanent damage to your robot!

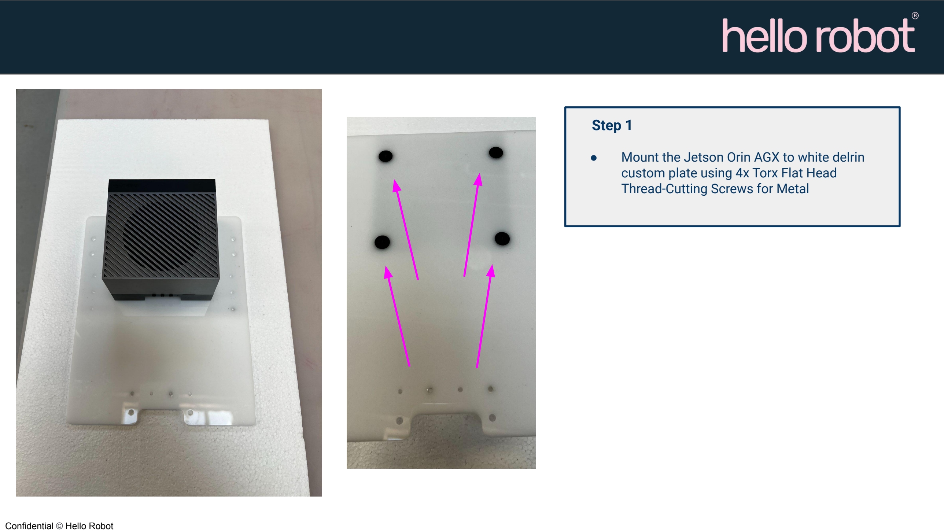
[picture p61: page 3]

Step 1
- Mount the Jetson Orin AGX to white delrin custom plate using 4x Torx Flat Head Thread-Cutting Screws for Metal

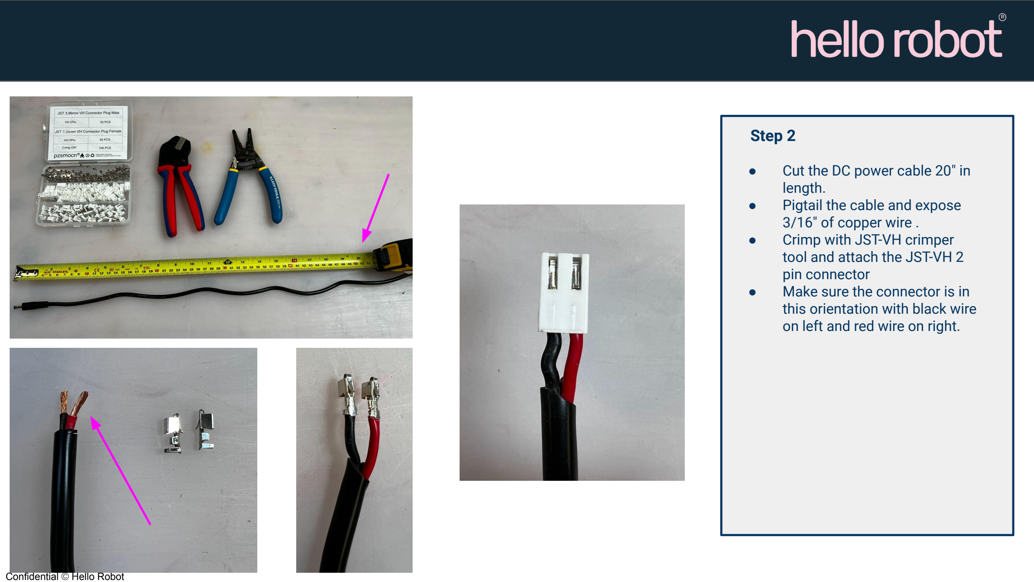
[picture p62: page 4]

Step 2 ● Cut the DC power cable 20" in

length.
- Pigtail the cable and expose 3/16" of copper wire .
- Crimp with JST-VH crimper tool and attach the JST-VH 2 pin connector
- Make sure the connector is in this orientation with black wire on left and red wire on right.

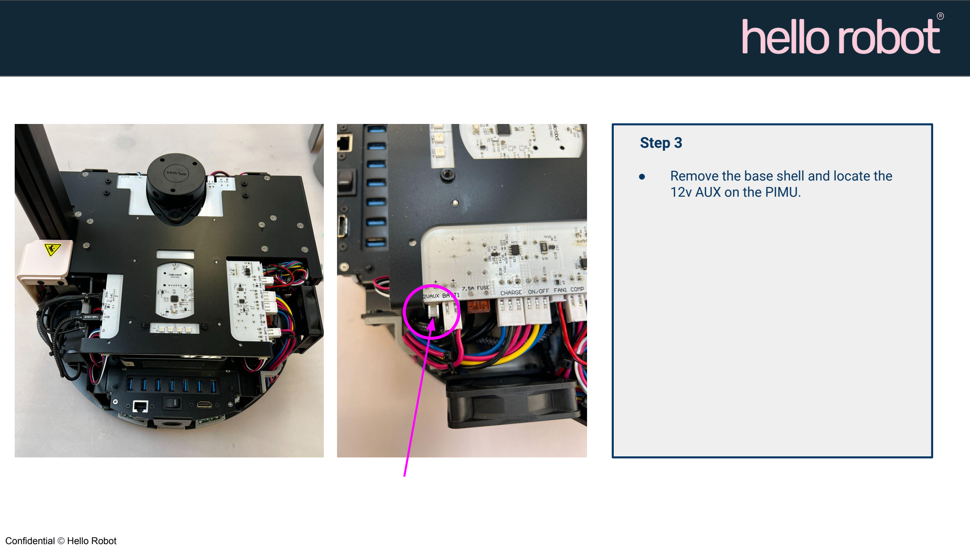
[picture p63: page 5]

Step 3
- Remove the base shell and locate the 12v AUX on the PIMU.

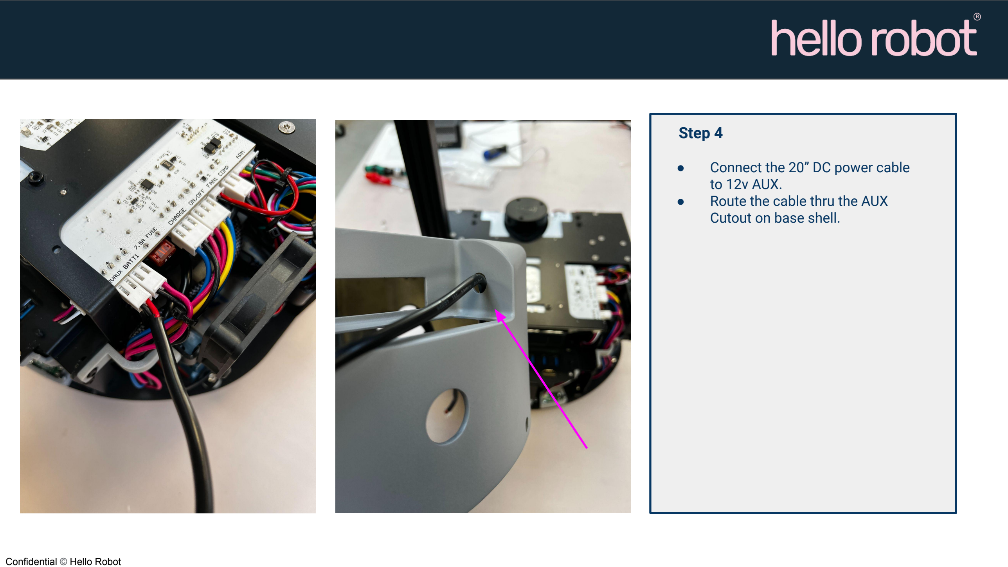
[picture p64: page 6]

Step 4
- Connect the 20” DC power cable to 12v AUX.
- Route the cable thru the AUX Cutout on base shell.

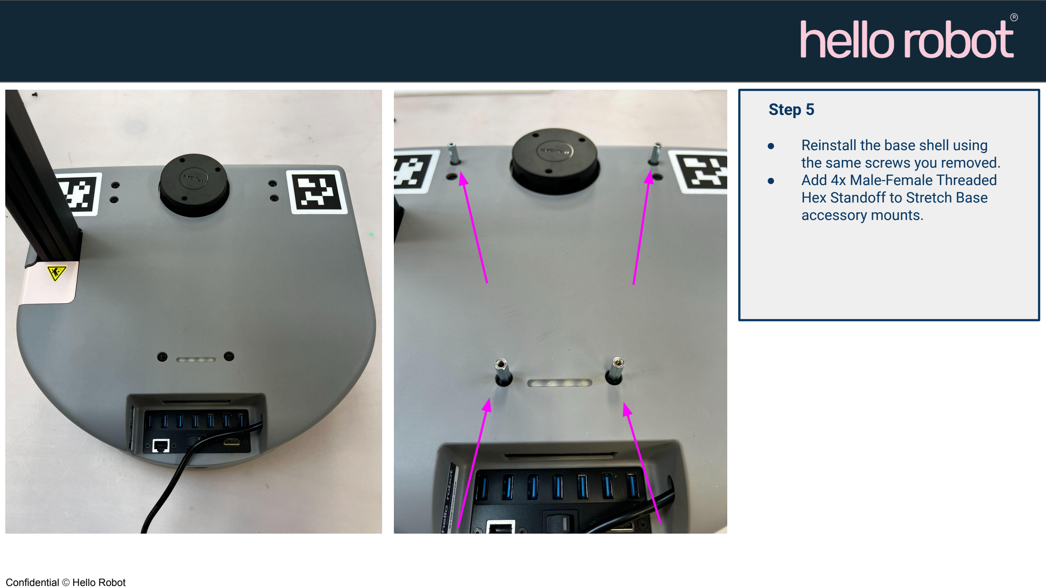
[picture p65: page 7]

Step 5
- Reinstall the base shell using the same screws you removed.
- Add 4x Male-Female Threaded Hex Standoff to Stretch Base accessory mounts.

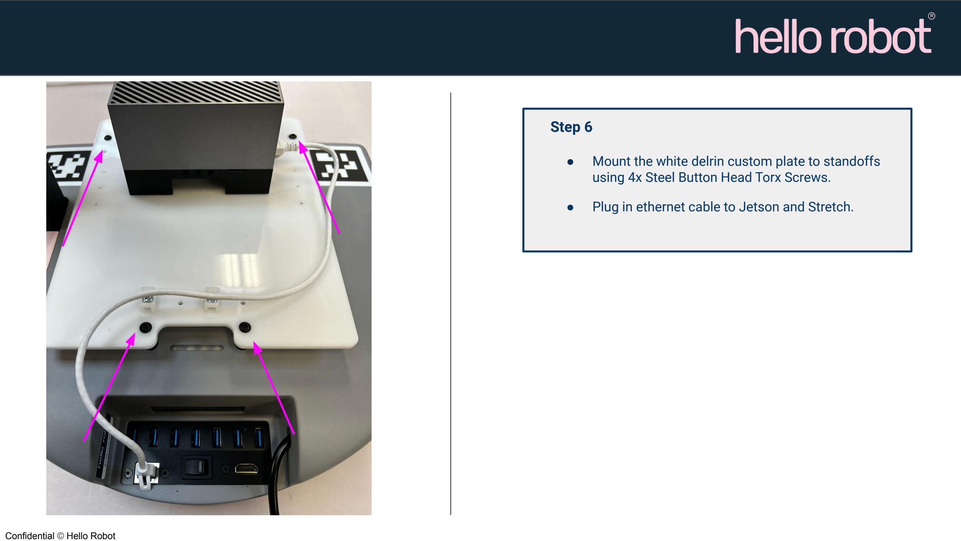
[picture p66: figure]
Step 6; using 4x Steel Button Head Torx Screws.

- Mount the white delrin custom plate to standoffs
- Plug in ethernet cable to Jetson and Stretch.

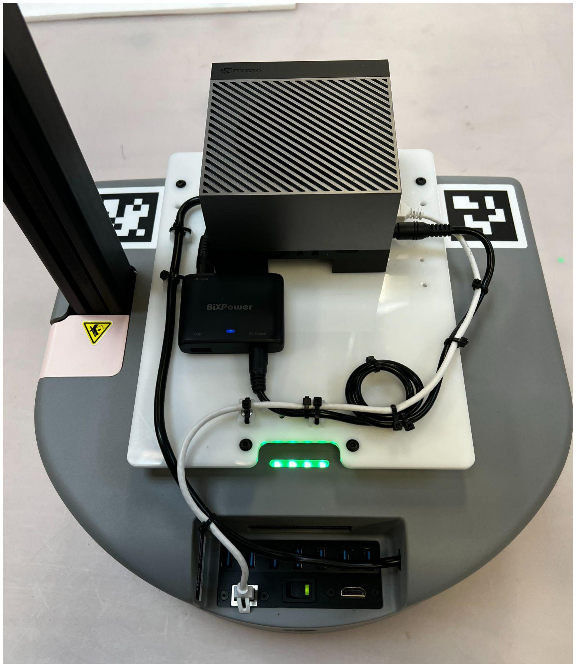
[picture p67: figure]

Step 7
- Attach 5x Cable tie mounts using 5x Phillips Rounded Head Thread forming screws.
- Route cables as pictured and zip-tie in place
- Cut excess zip-tie

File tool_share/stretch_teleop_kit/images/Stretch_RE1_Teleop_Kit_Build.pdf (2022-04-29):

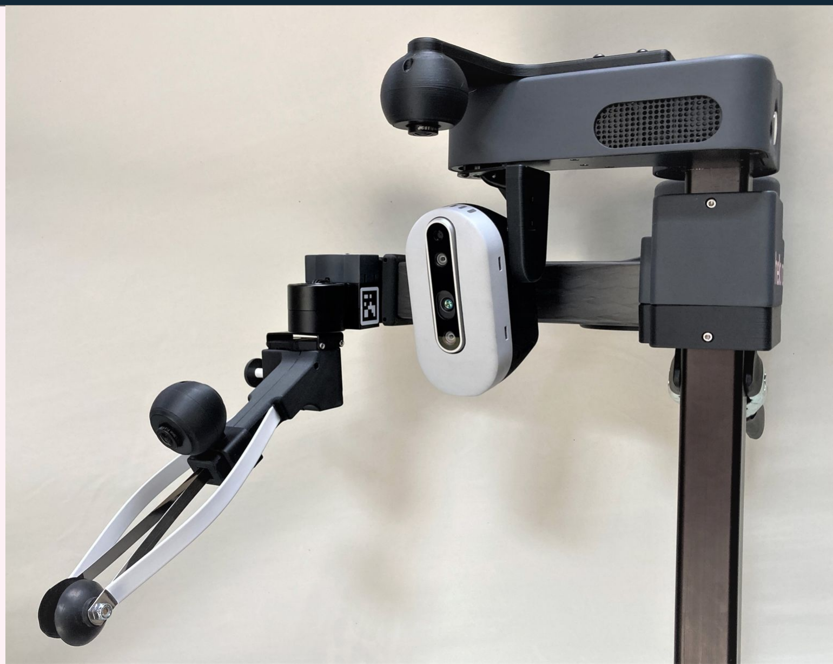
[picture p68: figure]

# Stretch RE1 Teleop Kit Build

# Rev 4.2022

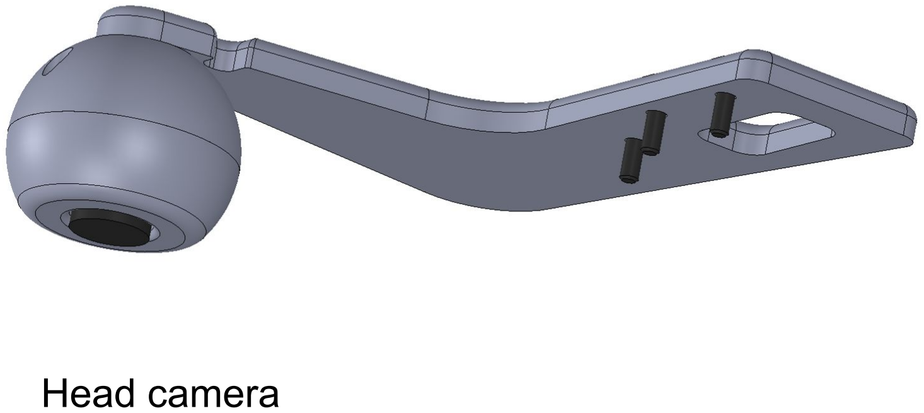
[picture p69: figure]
Head camera
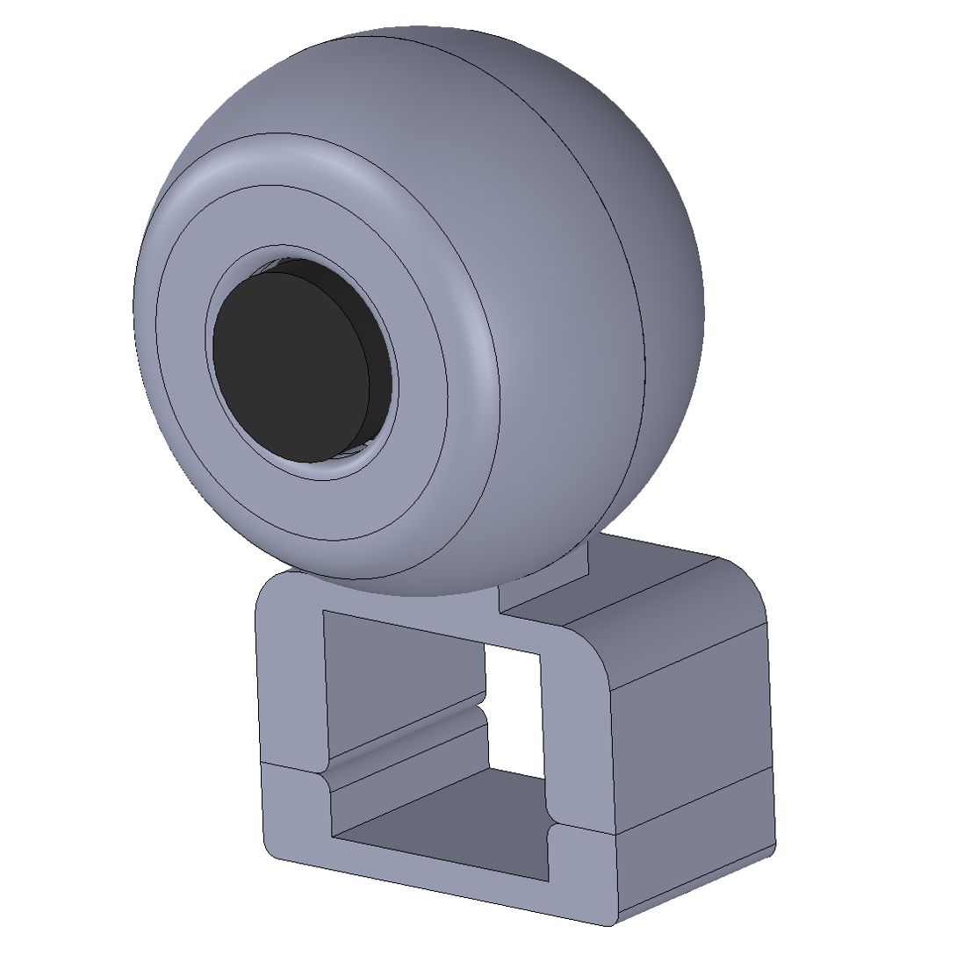
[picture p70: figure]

module | Gripper camera module

Hello Robot Part No | Vendor | Vendor Link | Vendor Part No | Qty | Notes
3DP-810_Head_Teleop_Mount | Hello Robot / Customer | N/A | 3DP-810_Head_Teleop_Mount | 1 | 3D printed PLA
3DP-808_Teleop_Camera_Mount_Front | Hello Robot / Customer | N/A | 3DP-808_Teleop_Camera_Mount_Fr ont | 2 | 3D printed PLA
3DP-809_Head_Teleop_Mount_Back | Hello Robot / Customer | N/A | 3DP-809_Head_Teleop_Mount_Back | 1 | 3D printed PLA
3DP-812_Gripper_Teleop_Mount_Bottom | Hello Robot / Customer | N/A | 3DP-812_Gripper_Teleop_Mount_Bo ttom | 1 | 3D printed PLA
3DP- 811_Gripper_Teleop_ Mount_Back | Hello Robot / Customer | N/A | 3DP- 811_Gripper_Teleop_ Mount_Back | 1 | 3D printed PLA
HDW-205_96817A268_M2.5x8mm_Thread_Forming | McMaster | https://www.mcmaster.com/96817A268/ | 96817A268 | 8
HDW-211_94180A321_M2.5x3.4mm_Heat_Set_Insert | McMaster | https://www.mcmaster.com/94180A321 | 94180A321 | 6
HDW-316_91290A103_M2.5x10mm_SHCS | McMaster | https://www.mcmaster.com/91290A103 | 91290A103 | 6
HDW-267_91239A140_M4x8mm_BHCS | McMaster | https://www.mcmaster.com/91239A140 | 91239A140 | 1
HDW-330_94180A351_M4x4.7mm_HEAT-SET INSERT | McMaster | https://www.mcmaster.com/94180A351 | 94180A351 | 1
HDW-802_91239A149_M4x14mm_BHCS_Black_Ox_Hex | McMaster | https://www.mcmaster.com/91239A149 | 91239A149 | 3
ELE-801_Spinel_UC20MPE_F185_camera | Spinell | https://store.spinelelectronics.com/UC20M
CBL-701-USB_Teleop_Head | Hello Robot / Customer | N/A | CBL-701-USB_Teleop_Head | 1 | Custom USB A-JST ZH. Contact Hello Robot for details.
CBL-702-USB_Teleop_Wrist | Hello Robot / Customer | N/A | CBL-702-USB_Teleop_Wrist | 1 | Custom USB A-JST ZH. Contact Hello Robot for details.
PE_F185 (https://store.spinelelectronics.com/UC20MPE_F185) | UC20MPE_F185 | 2

# Use a soldering iron to install the heat set inserts into the 4 PLA parts

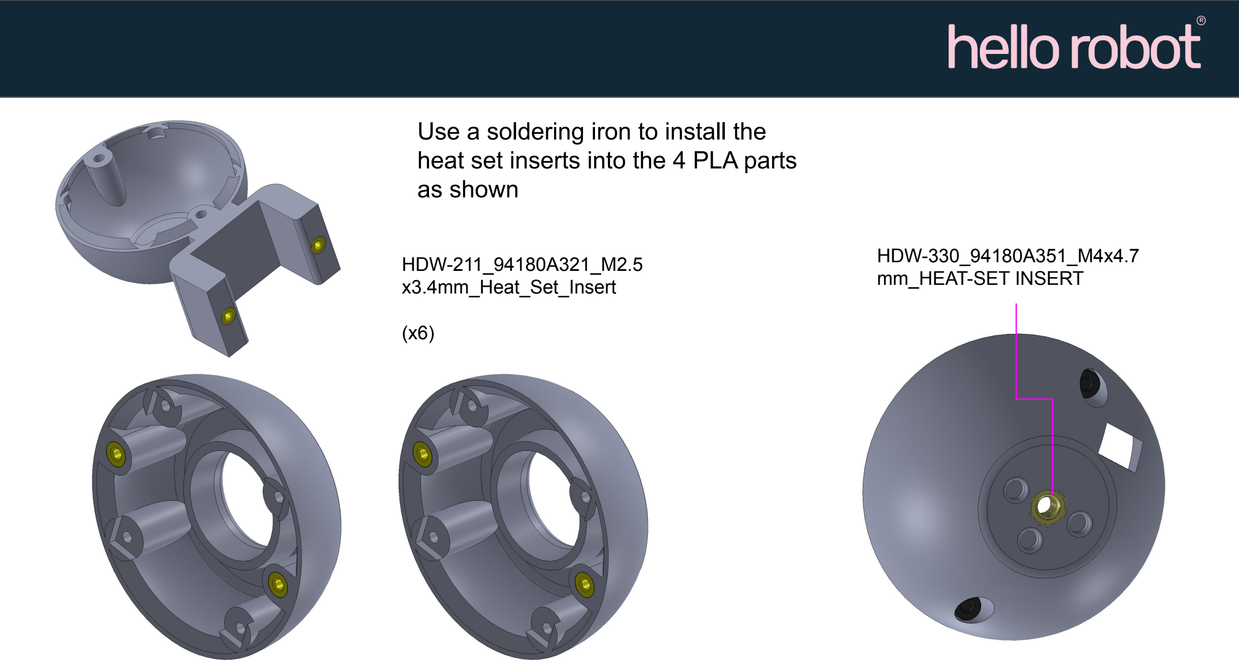
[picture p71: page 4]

# as shown

## HDW-330_94180A351_M4x4.7 mm_HEAT-SET INSERT

## HDW-211_94180A321_M2.5 x3.4mm_Heat_Set_Insert

(x6)

# Install cameras using 8x self

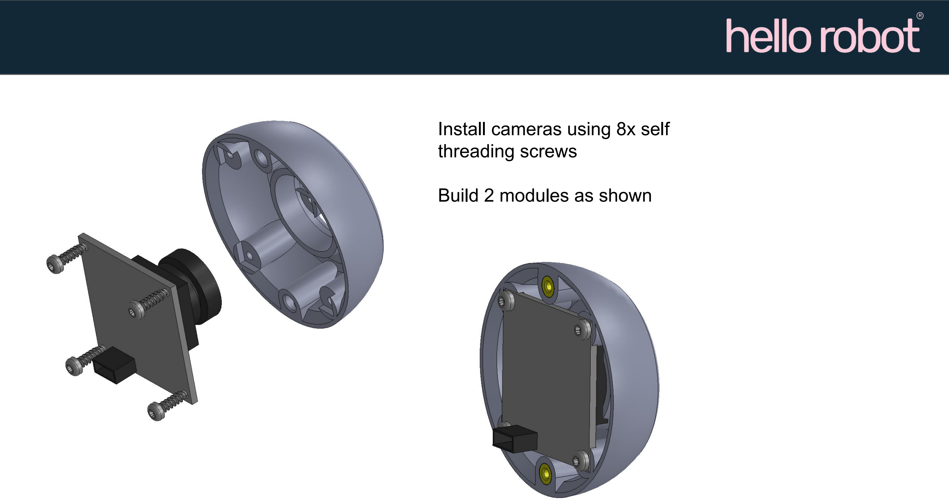
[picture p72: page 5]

# threading screws

# Build 2 modules as shown

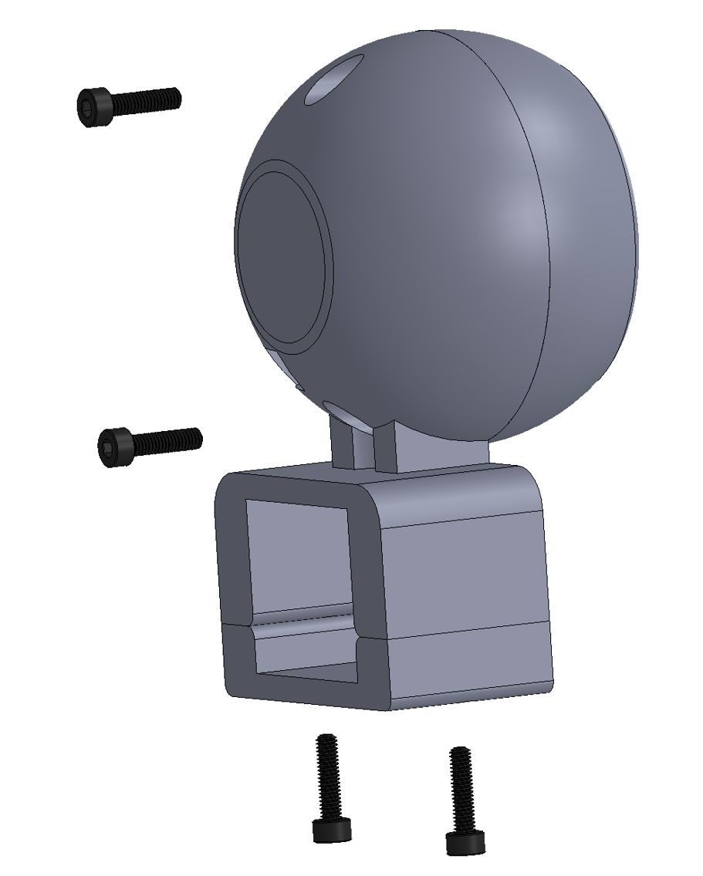
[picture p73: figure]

# Wrist module

# Attach CBL-702-USB_Teleop_Wrist to camera

# Assemble wrist module as shown using x4 M2.5x10mm SHCS bolts

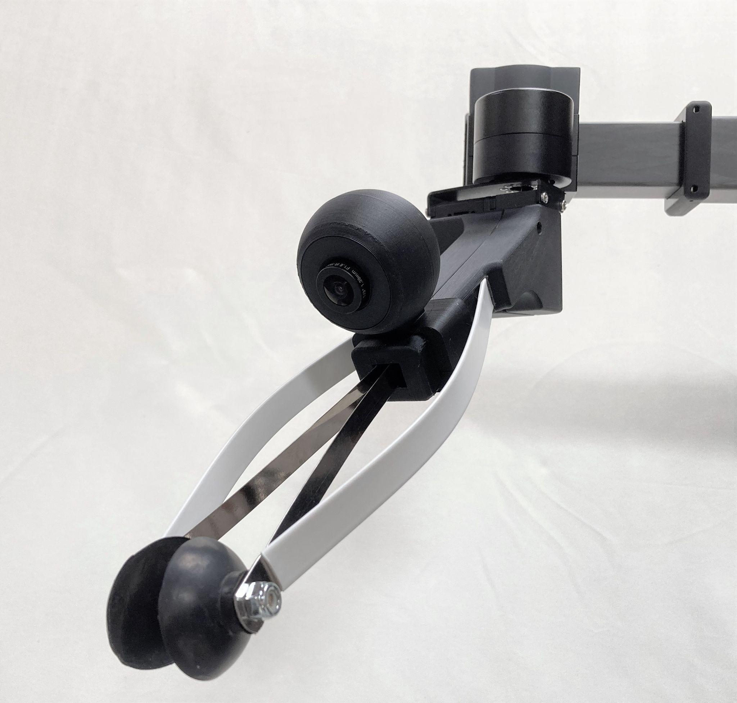
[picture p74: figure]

# Wrist module

Clamp camera module to end of gripper as shown.

# Connect USB-A of cable to RE1 wrist USB-A port

# Head module

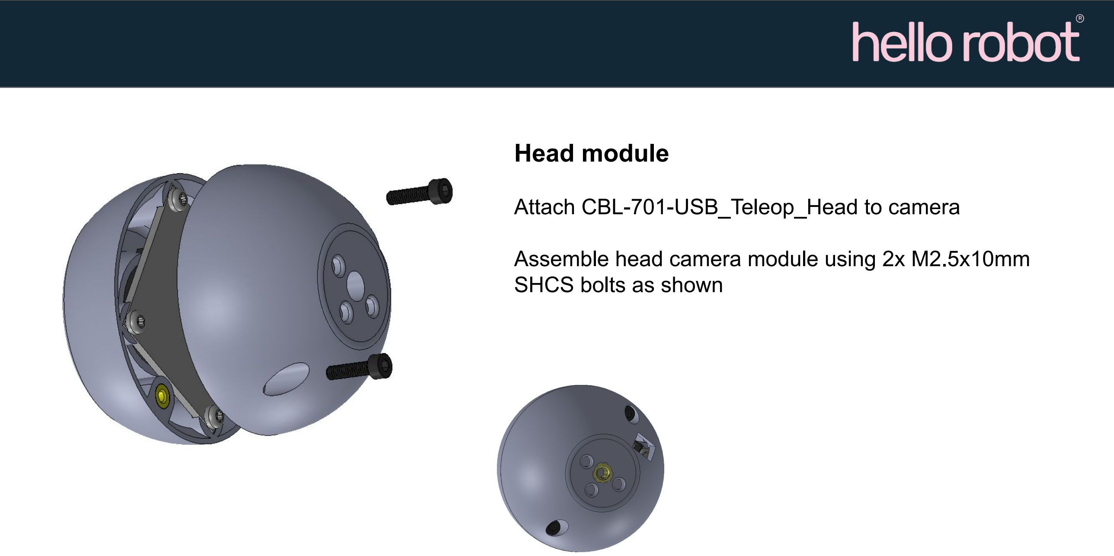
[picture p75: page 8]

# Attach CBL-701-USB_Teleop_Head to camera

# Assemble head camera module using 2x M2.5x10mm SHCS bolts as shown

# Head module

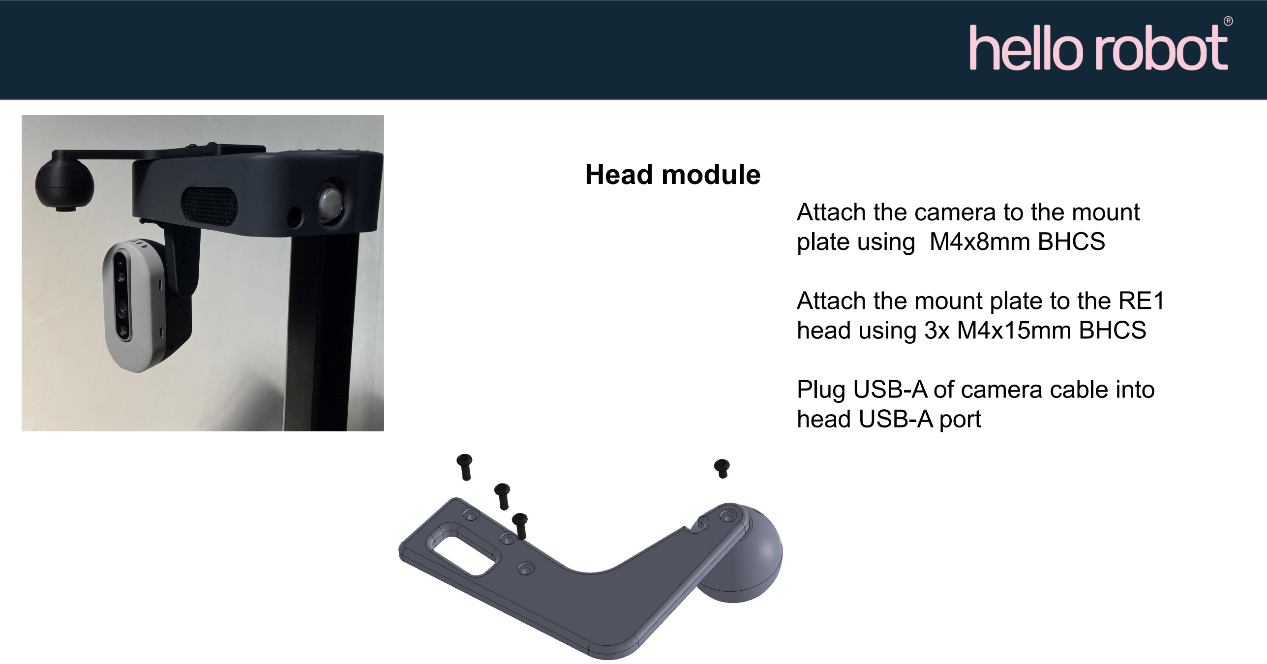
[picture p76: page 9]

# Attach the camera to the mount plate using M4x8mm BHCS

# Attach the mount plate to the RE1 head using 3x M4x15mm BHCS

# Plug USB-A of camera cable into head USB-A port

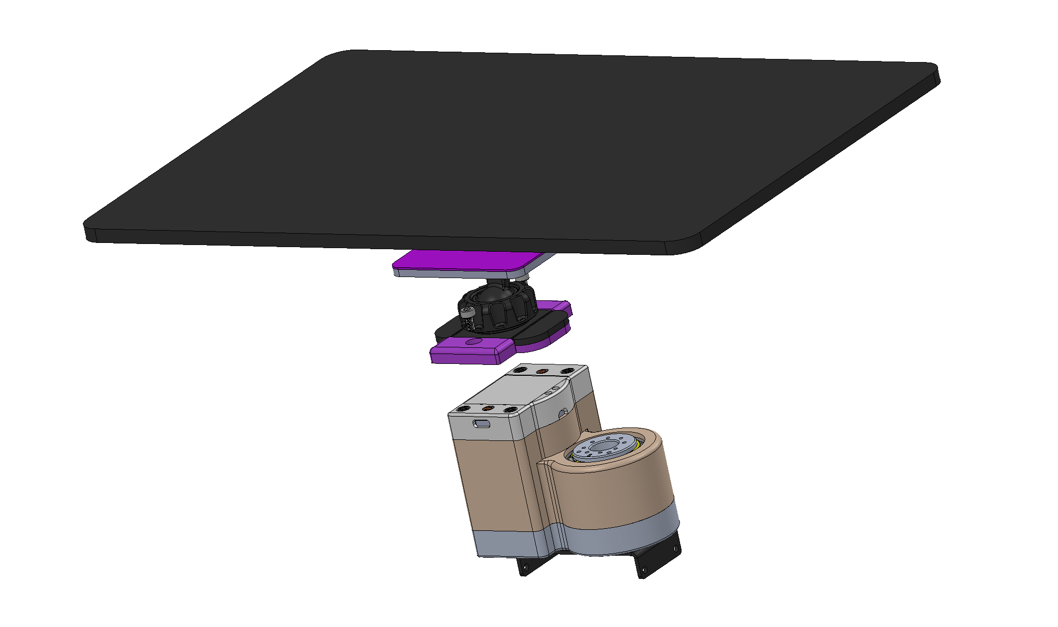
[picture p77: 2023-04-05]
tool_share/swivel_tablet_mount/images/tablet_assembly_exploded.png

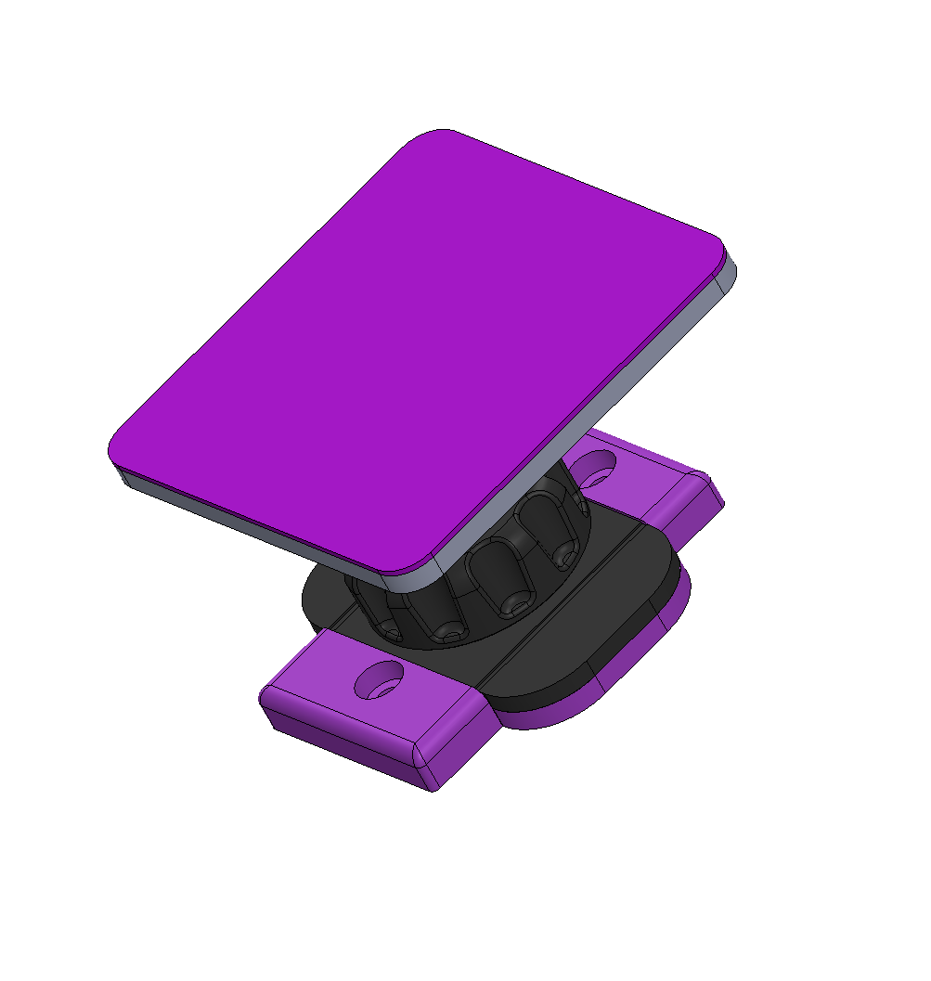
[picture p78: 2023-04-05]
tool_share/swivel_tablet_mount/images/ball_assembly.png

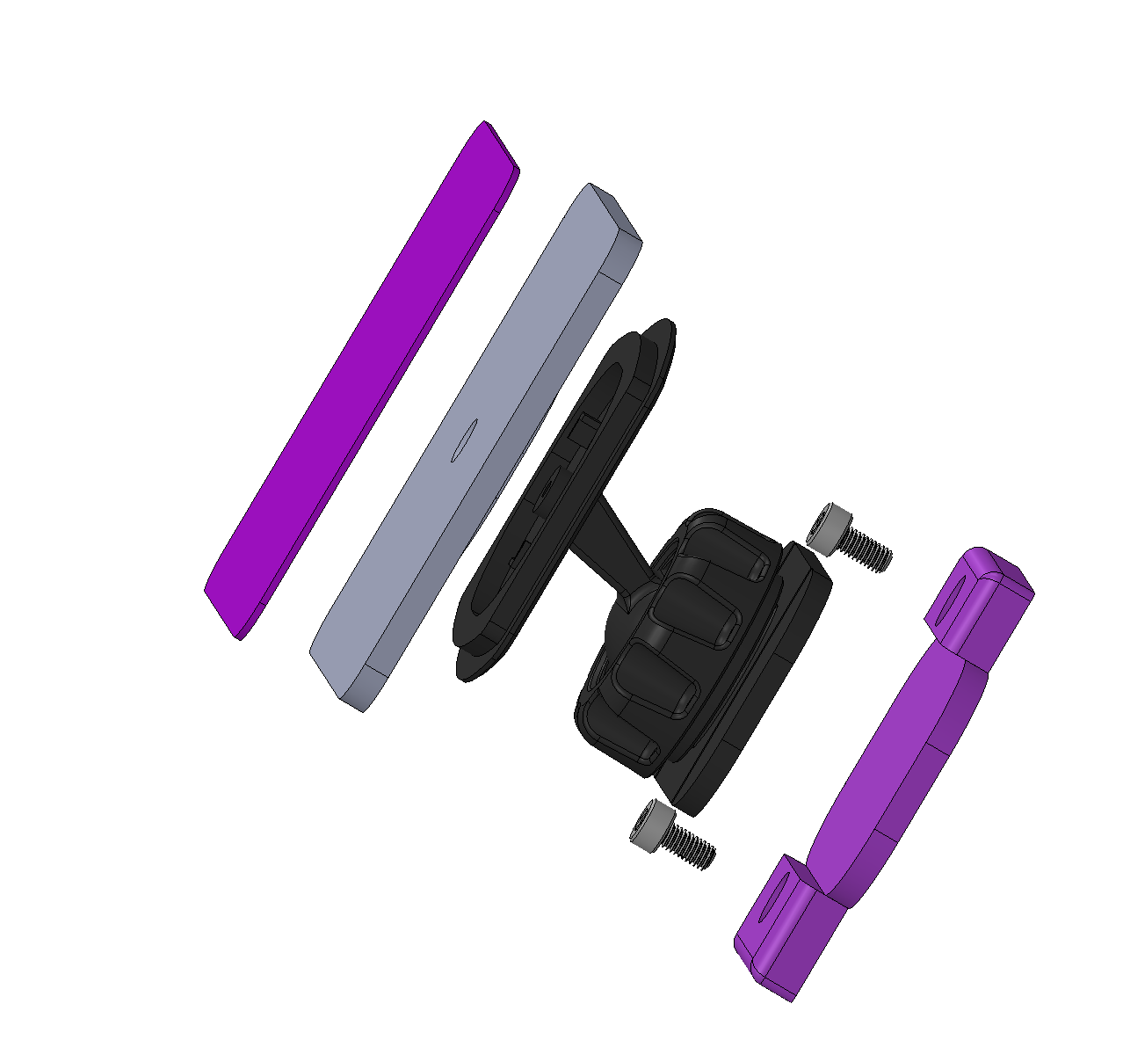
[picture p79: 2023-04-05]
tool_share/swivel_tablet_mount/images/ball_assembly_exploded.png

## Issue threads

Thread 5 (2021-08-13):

Stretch Dex Wrist joints missing new runstop calls

0lionelzhang0, 2021-08-13:
https://github.com/hello-robot/stretch_tool_share/blob/8e6b5c8c2b4f0b1ed6bc83b82a0d6209264ef26d/python/stretch_tool_share/stretch_dex_wrist/wrist_pitch.py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

wrist_pitch and wrist_roll missing the runstop line like in [wrist_yaw](https://github.com/hello-robot/stretch_body/blob/15c93620da897b5f889c90d6a4832a0e4c7a7437/body/stretch_body/wrist_yaw.py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
).

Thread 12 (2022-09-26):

Prevent manual copy of tool_share descriptions

youliangtan, 2022-09-26:
If i understand correctly, in order to use one of the tool_share here (for example: `stretch_dex_wrist`), user will need to copy the `meshes` and `urdf` files in `stretch_dex_wrist/stretch_description/` to the original `stretch_description` repo. Iam not sure if this practice is prone to error.

Just a proposal, if it is better to make it as such in the downstream pkg (e.g. `stretch_custom_tool`), to find the relative description file with `$(find stretch_description)`

```xml
<?xml version="1.0"?>
<robot xmlns:xacro="http://www.ros.org/wiki/xacro" name="stretch">
  <xacro:include filename="stretch_dex_wrist.xacro" />
  <xacro:include filename="$(find stretch_description)/urdf/stretch_main.xacro" />
  <xacro:include filename="$(find stretch_description)/urdf/stretch_aruco.xacro" />
  <xacro:include filename="$(find stretch_description)/urdf/stretch_d435i.xacro" />
  <xacro:include filename="$(find stretch_description)/urdf/stretch_laser_range_finder.xacro" />
  <xacro:include filename="$(find stretch_description)/urdf/stretch_respeaker.xacro" />
</robot>
```

I will understand if this will make things more complicated since user would need to edit the down stretch launch files that utilized `stretch_description`

hello-binit, 2022-09-29:
Hi @youliangtan, here is some information on the current setup: the mesh/XACRO files for a specific tool are copied from this repo (the Stretch Tool Share) into the [Stretch Description](https://github.com/hello-robot/stretch_ros/tree/dev/noetic/stretch_description) package. The [`stretch_description.xacro`](https://github.com/hello-robot/stretch_ros/blob/dev/noetic/stretch_description/urdf/stretch_description.xacro) file is modified by the user to substitute the `stretch_gripper.xacro` with the XACRO file of the tool. Then, the XACRO is converted into a uncalibrated URDF, where 'uncalibrated' means that all of the link offsets are assumed to be perfect. In practice, robot have small deviations from the ideal design that must be measured and accounted for. [Stretch Calibration](https://github.com/hello-robot/stretch_ros/tree/dev/noetic/stretch_calibration) runs a calibration procedure on the robot by collecting a dataset of measured offsets using the ArUco tags mounted to the robot and running an optimization on the dataset. The result is used to convert the uncalibrated URDF to a calibrated URDF.

Since this process is complicated, I'd welcome any ideas on how to simplify the process. I believe your recommendation here is to provide the `stretch_description.xacro` directly in the Tool Share itself, because it can reference the Stretch Description package via ROS. Is this correct?

Closed 2024-03-01.

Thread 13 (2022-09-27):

Revert Servo Configuration Changes from ReactorX Wrist

nhanson2, 2022-09-27:
We recently applied the changes to our stretch to add the ReactorX wrist. We'd now like to change the robot back to it's default configuration, but are having trouble getting the original wrist rotation servo to home to the correct position.

Essentially when we run the calibration script, the wrist rotates beyond the correct stopping point. We've attempted to use Dynamixel Wizard to reset the home position, but it seems like the newly written home value is not respected. Is there a reset script to restore the default arm configuration?

hello-binit, 2022-09-28:
Hi @nhanson2, reverting to the original configuration should involve updating the User YAML back to what it was before applying the changes from the [ReactorX section](https://github.com/hello-robot/stretch_tool_share/tree/master/tool_share/reactorx_wrist_V1#code). The home position in Dynamixel Wizard doesn't affect where the joints go to. In order to make sure I understand the issue, would you take a video of the issue you're seeing?

hello-binit, 2024-03-01:
Closing this issue. If you're still facing this issue, please feel free to open a new one.

Closed 2024-03-01.

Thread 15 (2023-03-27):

Update pitch 'stall_max_effort' param default from 10.0 to 20.0

bm-hellorobot, 2023-03-27:
Solves the issue of pitch joint slowly dropping with ~1lb weight; tested for 30 min at high load and could not overheat servo.

Ping Chris Paxton's group when completed

hello-binit, 2024-03-01:
The pitch joint in now supported in Stretch Body. If this is still an issue, please feel free to open a new Github issue in the Stretch Body repository.

Closed 2024-03-01.

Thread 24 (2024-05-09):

Request: Model for SE3

atyshka, 2024-05-09:
Do you plan to add a STEP model for the SE3? As far as I'm aware the only CAD files for it would be STLs from the URDF, which can't be viewed as a whole robot but only separate links

bm-hellorobot, 2024-05-09:
Yes, good catch - will have this added in the next few days.

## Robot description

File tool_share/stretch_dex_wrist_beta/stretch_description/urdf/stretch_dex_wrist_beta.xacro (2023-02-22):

<?xml version="1.0"?>
<robot xmlns:xacro="http://www.ros.org/wiki/xacro" name="stretch_dex_wrist_beta">

  <xacro:property name="scale_finger_length" value="0.9" />

  <link name="link_wrist_yaw_bottom">
    <inertial>
      <origin xyz="-0.012839101377342 -0.0382787718640742 -0.0228400332263617" rpy="0 0 0" />
      <mass value="0.0988906816399982" />
      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
    </inertial>
    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
  </link>
  <joint name="joint_wrist_yaw_bottom" type="fixed">
    <origin xyz="0 0 0" rpy="-3.14159265358979 1.13367999021379E-14 1.57079632679489" />
    <parent link="link_wrist_yaw" />
    <child link="link_wrist_yaw_bottom" />
    <axis xyz="0 0 0" />
  </joint>
  <link name="link_wrist_pitch">
    <inertial>
      <origin xyz="-0.00310609611067142 -0.0150777141465843 0.0204734587925901" rpy="0 0 0" />
      <mass value="0.0701267146295583" />
      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
    </inertial>
    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
  </link>
  <joint name="joint_wrist_pitch" type="revolute">
    <origin xyz="0 -0.0195500000000002 -0.0247499999999984" rpy="1.5707963267949 -8.12895570882604E-15 -3.14159265358979" />
    <parent link="link_wrist_yaw_bottom" />
    <child link="link_wrist_pitch" />
    <axis xyz="0 0 -1" />
    <limit effort="100" lower="-1.57" upper="0.56" velocity="1.0"/>
  </joint>
  <link name="link_wrist_roll">
    <inertial>
      <origin xyz="9.63118473862323E-15 -6.38378239159465E-15 0.00768048802649798" rpy="0 0 0" />
      <mass value="0.00585666394358811" />
      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
    </inertial>
    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
  </link>
  <joint name="joint_wrist_roll" type="revolute">
    <origin xyz="-0.0188587444076125 -0.0239999999998942 0.01955" rpy="3.14159265358979 1.5707963267949 0" />
    <parent link="link_wrist_pitch" />
    <child link="link_wrist_roll" />
    <axis xyz="0 0 1" />
    <limit effort="100" lower="-3.14" upper="3.14" velocity="1.0"/>
  </joint>
  <link name="link_straight_gripper">
    <inertial>
      <origin xyz="0.00150764845432383 -0.00711581846201287 0.0399737901417758" rpy="0 0 0" />
      <mass value="0.0496384234458284" />
      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
    </inertial>
    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
  </link>
  <joint name="joint_straight_gripper" type="fixed">
    <origin xyz="0 0 0.0155" rpy="3.54987407349455E-30 3.24021254484265E-20 -3.14159265358979" />
    <parent link="link_wrist_roll" />
    <child link="link_straight_gripper" />
    <axis xyz="0 0 0" />
  </joint>
  <link name="link_gripper_finger_right">
    <inertial>
      <origin xyz="-0.094981 -0.0080152 -2.2204E-16" rpy="0 0 0" />
      <mass value="0.047621" />
      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
    </inertial>
    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
  </link>
  <joint name="joint_gripper_finger_right" type="revolute">
    <origin xyz="-0.018599 0.003 0.033689" rpy="1.5708 1.5708 0" />
    <parent link="link_straight_gripper" />
    <child link="link_gripper_finger_right" />
    <axis xyz="0 0 1" />
    <limit effort="100" lower="-0.6" upper="0.6" velocity="1.0"/>
  </joint>
  <link name="link_gripper_fingertip_right">
    <inertial>
      <origin xyz="2.83785970833783E-08 6.75131661687089E-09 0.00812578923434215" rpy="0 0 0" />
      <mass value="0.00382160881468841" />
      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
    </inertial>
    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
  </link>
  <joint name="joint_gripper_fingertip_right" type="fixed">
    <origin xyz="-0.190596948563868 -0.015 0" rpy="-1.57079632679483 -3.43320051448326E-14 0.540456056432235" />
    <parent link="link_gripper_finger_right" />
    <child link="link_gripper_fingertip_right" />
    <axis xyz="0 0 0" />
  </joint>
  <link name="link_gripper_finger_left">
    <inertial>
      <origin xyz="0.0949811095686165 -0.00801522758203194 1.38777878078145E-15" rpy="0 0 0" />
      <mass value="0.0476207785199479" />
      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
    </inertial>
    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
  </link>
  <joint name="joint_gripper_finger_left" type="revolute">
    <origin xyz="0.018599 0.003 0.033689" rpy="1.5708 -1.5708 0" />
    <parent link="link_straight_gripper" />
    <child link="link_gripper_finger_left" />
    <axis xyz="0 0 -1" />
    <limit effort="100" lower="-0.6" upper="0.6" velocity="1.0"/>
  </joint>
  <link name="link_gripper_fingertip_left">
    <inertial>
      <origin xyz="-2.59496317767116E-08 -6.65612598371723E-09 0.00812579036862837" rpy="0 0 0" />
      <mass value="0.00382160686584851" />
      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
    </inertial>
    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
  </link>
  <joint name="joint_gripper_fingertip_left" type="fixed">
    <origin xyz="0.190596948563868 -0.015 0" rpy="1.57079632679496 4.51275387511463E-14 2.60113659715756" />
    <parent link="link_gripper_finger_left" />
    <child link="link_gripper_fingertip_left" />
    <axis xyz="0 0 0" />
  </joint>

  <link name="link_grasp_center">
  </link>

  <joint name="joint_grasp_center" type="fixed">
    <origin xyz="0 0 0.23" rpy="-1.5707963267949 -1.5707963267949 0" />
    <parent link="link_straight_gripper" />
    <child link="link_grasp_center" />
  </joint>

</robot>

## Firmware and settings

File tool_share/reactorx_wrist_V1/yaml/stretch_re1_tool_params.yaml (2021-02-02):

# Include 3rd Party tool / Tool Share device parameters here

reactor_gripper:
  gr: 1.0
  id: 16
  max_voltage_limit: 15
  min_voltage_limit: 11
  motion:
    default: {accel: 8.0, vel: 3.0}
    fast: {accel: 15.0, vel: 6.0}
    max: {accel: 0, vel: 0}
    slow: {accel: 4.0, vel: 1.0}
  pid: [640, 0, 0]
  pwm_limit: 885
  range_t: [0, 4096]
  req_calibration: 0
  return_delay_time: 0
  temperature_limit: 72
  usb_name: /dev/hello-dynamixel-wrist
  use_multiturn: 0
  zero_t: 0
reactor_pitch:
  gr: 1.0
  id: 14
  max_voltage_limit: 15
  min_voltage_limit: 11
  motion:
    default: {accel: 8.0, vel: 3.0}
    fast: {accel: 15.0, vel: 6.0}
    max: {accel: 0, vel: 0}
    slow: {accel: 4.0, vel: 1.0}
  pid: [640, 0, 0]
  pwm_limit: 885
  range_t: [0, 4096]
  req_calibration: 0
  return_delay_time: 0
  temperature_limit: 72
  usb_name: /dev/hello-dynamixel-wrist
  use_multiturn: 0
  zero_t: 0
reactor_roll:
  gr: 1.0
  id: 15
  max_voltage_limit: 15
  min_voltage_limit: 11
  motion:
    default: {accel: 8.0, vel: 3.0}
    fast: {accel: 15.0, vel: 6.0}
    max: {accel: 0, vel: 0}
    slow: {accel: 4.0, vel: 1.0}
  pid: [640, 0, 0]
  pwm_limit: 885
  range_t: [0, 4096]
  req_calibration: 0
  return_delay_time: 0
  temperature_limit: 72
  usb_name: /dev/hello-dynamixel-wrist
  use_multiturn: 0
  zero_t: 0

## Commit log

2020-06-18 Initial commit for public version
    [ASSEM_Puller_V1.STL, ASSEM_tray_cupholder_V1.STL, Puller_V1.STL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]
2020-10-14 Added Stretch head STL and docs
    [Stretch_RE1_Head_Camera.STL, Stretch_RE1_Head_Left.STL, Stretch_RE1_Head_Right.STL]
2021-01-28 Added STEP of RE1 wrist
    [Hello-Robot-Stretch-RE1_Wrist_Module.STEP]
2021-02-11 Added urdf and usb board camerea. wip
    [link_dry_erase_holder.STL, link_dry_erase_marker.STL, link_wrist_USB_board_camera.STL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]
2021-02-11 Documented the wrist board camera
    [Spinel_camera_wide_fov.STL]
2021-02-11 reorg stretch_description
    [link_dry_erase_holder.STL, link_dry_erase_marker.STL, link_wrist_USB_board_camera.STL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]
2021-02-11 fix board camera xacro
    [stretch_wrist_USB_board_camera.xacro]
2021-02-24 Moving stretch_description to their tool folder
    [link_dry_erase_holder.STL, link_dry_erase_marker.STL, link_wrist_USB_board_camera.STL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]
2021-02-24 draft of beta wrist urdf
    [link_wrist_yaw.STL, stretch_beta_dexterous_wrist.xacro, stretch_description.urdf]
2021-03-02 updated beta wrist xacro
    [link_wrist_roll.STL, stretch_beta_dexterous_wrist.xacro]
2021-03-02 update beta wrist urdf
    [link_dry_erase_holder.STL, link_dry_erase_marker.STL, link_wrist_USB_board_camera.STL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]
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2021-03-03 update beta wrist xacro
    [stretch_beta_dexterous_wrist.xacro]
2021-03-05 reorg and renaming
    [ASSEM_Puller_V1.STL, ASSEM_tray_cupholder_V1.STL, Hello-Robot-Stretch-RE1_Wrist_Module.STEP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]
2021-03-05 dex wrist beta urdf done
    [stretch_dex_wrist_beta.xacro]
2021-03-11 update dex wrist
    [stretch_dex_wrist_beta.xacro]
2021-05-31 ready for 0.1.0 release of Stretch Body
    [link_wrist_pitch.STL, link_wrist_roll.STL, link_wrist_yaw_bottom.STL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]
2021-06-03 fix to dexwrist urdf
    [stretch_dex_wrist.xacro]
2021-06-03 adjust collision ranges to prevent bouncing behvior on dex_wrist pitch up
2021-06-15 remove print bug for py3
2021-06-20 update banner
    [wrist_mount_spacer.STL]
2021-08-27 fix py3 print error
2021-09-22 adding stretch_description for dex wrist
    [stretch_description.xacro]
2021-09-27 Added docking station beta URDF
    [Stretch_RE1_docking_station_beta_URDF.csv, Stretch_RE1_docking_station_beta_URDF.urdf, link_aruco_110mm.STL]
2021-09-27 docking station wip
    [Stretch_RE1_docking_station_beta_URDF.csv, stretch_re1_docking_station_beta.urdf]
2021-09-27 Trying again on docking station URDF
    [link_aruco_110mm.STL, stretch_docking_station_description.csv, stretch_docking_station_description.urdf]
2021-09-27 cleanup docking station
    [link_aruco_110mm.STL, stretch_docking_station_description.csv, stretch_docking_station_description.urdf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]
2021-11-18 dexwrist pitch no longer drops on exit
2022-04-28 Initial add of teleop URDF
    [base_link.STL, laser.STL, link_arm_l0.STL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]
2022-04-29 Teleop kit wip
    [3DP-808_Teleop_Camera_Mount_Front.STL, 3DP-809_Head_Teleop_Mount_Back.STL, 3DP-810_Head_Teleop_Mount.STL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]
2022-05-01 Added Teleop Kit xacro files
    [stretch_gazebo.urdf.xacro, stretch_teleop_kit.xacro]
2022-05-02 Added stretch_description.xacro for teleop kit
    [stretch_description.xacro]
2022-05-02 Teleop Xacro File path Change
    [stretch_description.xacro]
2022-05-02 Gazebo Support instructions Added to Teleop and cleanup
    [base_link.STL, laser.STL, link_arm_l0.STL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]
2022-05-09 added docking station. wip
    [link_docking_aruco.STL, stretch_docking_station_description.csv, stretch_docking_station_description.urdf]
2022-05-10 Adding Dex Wrist Gazebo Support Files
    [stretch_dex_wrist.xacro, stretch_gazebo.urdf.xacro]
2022-05-10 Added Dex Wrist Gazebo README
    [stretch_dex_wrist.xacro]
2022-07-17 Adding tool description for arm-mounted tray
    [stretch_tray.SLDPRT, tray_asm.SLDASM, tray_clip.SLDPRT]
2022-08-02 Added lower resolution STL files and updated README with newest pictures
    [A_frame.STL, base_v2.STL, gear_wheel.STL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]
2022-08-03 Added lower resolution STL files
    [stretch_arm_tray.STL, stretch_tray.SLDPRT, stretch_tray.STL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]
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2022-08-04 Improving file names
    [stretch_arm_tray_asm.STL]
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2022-08-05 bump version fix dex wrist homing
2022-09-06 Adding button pusher to feature branch
    [button_pusher_V2.stl]
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2023-01-04 Add Stretch 2 Step
    [ASM-207_Gripper_Simple.STEP, ASM-head_module.STEP, ASM_Arm_with_Wrist_simple.STEP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]
2023-01-04 Added DexWrist to Stretch 2 STEP
    [ASM-210_Straight_Gripper_simple.STEP, SIM-401_Roll_Hanger_simple.STEP, SUB-216_Dex_Wrist_simple.STEP]
2023-02-22 Add link_grasp_center to dex wrist
    [stretch_dex_wrist.xacro, stretch_dex_wrist_beta.xacro]
2023-03-30 Wrist camera fix (#16)
    * Add files via upload
    * Delete Boad_Camera_Ball_Cover.STL
    * Update README.md
    * Update README.md
    [Board_Camera_Ball_Cover.STL]
2023-04-05 Added tablet swivel mount
    [swivel_adapter.STL, tablet_tape_adapter.STL]
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2023-07-18 Initiating Jetson mount tool
    [swivel_adapter_bottom.STL, swivel_adapter_top.STL, tablet_tape_adapter.STL]
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2023-08-24 Create the README file for the jetson tutorials with general information and how to enter the FR mode
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2023-08-24 Separate the tutorial with steps and also add the way to shutdown the Jetson
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2024-01-28 Added URDF and CAD for 12in tablet
    [DW3_tablet_holder.STEP, DW3_tablet_holder.STL, link_DW3_tablet_12in.STL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]
2024-01-28 Tablet 12in urdf working in viz tool
    [stretch_tool_tablet_12in.xacro]
2025-03-24 Shoulder CAD
    [Shoulder_Mount_CAD.stp]
